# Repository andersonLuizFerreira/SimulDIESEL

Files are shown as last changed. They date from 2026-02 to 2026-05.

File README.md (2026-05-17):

# SimulDIESEL

---

# Português

O SimulDIESEL consiste em uma plataforma de bancada destinada à manutenção, diagnóstico, análise, simulação e validação de centrais e módulos automotivos da linha DIESEL, com foco em caminhões, máquinas agrícolas e equipamentos pesados.

Suas ferramentas permitem ao reparador realizar testes, simulações e análises de funcionamento de redes, sinais e módulos eletrônicos, auxiliando processos de manutenção, desenvolvimento, engenharia reversa e diagnóstico avançado em bancada.

Para conhecer mais sobre o projeto, leia:

- [`docs/README.md`](docs/README.md)
- [`docs/00-INDICE.md`](docs/00-INDICE.md)

Esses arquivos guiarão você pela documentação e estrutura do projeto.

## agentes de IA

Siga para:

- [`.agents/README.md`](.agents/README.md)

---

# English

SimulDIESEL is a bench platform designed for maintenance, diagnostics, analysis, simulation, and validation of DIESEL automotive control units and electronic modules, focused on trucks, agricultural machines, and heavy equipment.

Its tools allow technicians to perform tests, simulations, and analysis of networks, signals, and electronic modules, supporting maintenance, development, reverse engineering, and advanced bench diagnostics.

To learn more about the project, read:

- [`docs/README.md`](docs/README.md)
- [`docs/00-INDICE.md`](docs/00-INDICE.md)

These files will guide you through the project's documentation and structure.

## AI agents

Proceed to:

- [`.agents/README.md`](.agents/README.md)

---

# Español

SimulDIESEL es una plataforma de banco destinada al mantenimiento, diagnóstico, análisis, simulación y validación de centrales y módulos automotrices de la línea DIESEL, enfocada en camiones, maquinaria agrícola y equipos pesados.

Sus herramientas permiten al reparador realizar pruebas, simulaciones y análisis del funcionamiento de redes, señales y módulos electrónicos, ayudando en procesos de mantenimiento, desarrollo, ingeniería inversa y diagnóstico avanzado en banco.

Para conocer más sobre el proyecto, lea:

- [`docs/README.md`](docs/README.md)
- [`docs/00-INDICE.md`](docs/00-INDICE.md)

Estos archivos lo guiarán a través de la documentación y estructura del proyecto.

## agentes de IA

Diríjase a:

- [`.agents/README.md`](.agents/README.md)

---

# Deutsch

SimulDIESEL ist eine Prüfstandsplattform für Wartung, Diagnose, Analyse, Simulation und Validierung von Steuergeräten und elektronischen Modulen im DIESEL-Bereich mit Fokus auf Lastkraftwagen, landwirtschaftliche Maschinen und schwere Geräte.

Die Werkzeuge ermöglichen Technikern die Durchführung von Tests, Simulationen und Analysen von Netzwerken, Signalen und elektronischen Modulen und unterstützen Wartung, Entwicklung, Reverse Engineering und erweiterte Prüfstandsdiagnosen.

Um mehr über das Projekt zu erfahren, lesen Sie:

- [`docs/README.md`](docs/README.md)
- [`docs/00-INDICE.md`](docs/00-INDICE.md)

Diese Dateien führen Sie durch die Dokumentation und Struktur des Projekts.

## KI-Agenten

Weiter zu:

- [`.agents/README.md`](.agents/README.md)

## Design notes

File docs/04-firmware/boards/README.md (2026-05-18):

⬅ [Retornar para Catálogo de Baby Boards e Targets SDH](../05-catalogo-baby-boards.md)
⬅ [Retornar para Índice Geral](../../00-INDICE.md)

# Boards de Firmware

Esta pasta agrupa as boards sob o ponto de vista do firmware embarcado.

## Estado real da pasta

- **IMPLEMENTADO**: `BPM`, `GSA` e `UCE` têm firmware, arquivos, classes e fluxo observáveis.
- **PLANEJADO**: `PSU`, `GSC`, `URL`, `SLU`, `UCO`, `UCS`, `UIOD` e `UHM` permanecem como placeholders documentais.
- **LEGADO**: qualquer leitura que suponha firmware ativo para todas as boards listadas aqui.

## Índice

- [01. BPM](BPM/01-bpm.md)
- [02. PSU](PSU/02-psu.md)
- [03. GSA](GSA/03-gsa.md)
- [11. UCE](UCE/11-uce.md)
- [04. GSC](04-gsc.md)
- [05. URL](05-url.md)
- [06. SLU](06-slu.md)
- [07. UCO](07-uco.md)
- [08. UCS](08-ucs.md)
- [09. UIOD](09-uiod.md)
- [10. UHM](10-uhm.md)

## Leitura correta deste ramo

- `BPM`, `GSA` e `UCE` devem ser lidas como páginas vivas de firmware.
- As demais pages ajudam a preservar nomenclatura e intenção do projeto, mas ainda não representam código embarcado implementado.

## Glossário

- **Board**: unidade física com firmware próprio ou reservado.
- **Página viva**: documento ancorado em implementação real.
- **Placeholder documental**: página mantida para organização, mas sem código correspondente.

## Próximas camadas

- [BPM](BPM/01-bpm.md)
- [PSU](PSU/02-psu.md)
- [GSA](GSA/03-gsa.md)
- [UCE](UCE/11-uce.md)
- [GSC](04-gsc.md)
- [URL](05-url.md)
- [SLU](06-slu.md)
- [UCO](07-uco.md)
- [UCS](08-ucs.md)
- [UIOD](09-uiod.md)
- [UHM](10-uhm.md)

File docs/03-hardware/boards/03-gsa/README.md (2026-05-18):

⬅ [Retornar para Construção Física das Boards](../../05-boards-fisicas.md)
⬅ [Retornar para Índice Geral](../../../00-INDICE.md)

# GSA — Gerador de Sinais Analógicos

Esta página descreve a GSA como placa física.

## Evidências materiais usadas aqui

- `hardware/boards/GSA -gerador-sinais-analogicos/GSA - gerador de sinais analogicos.kicad_sch`
- `hardware/boards/GSA -gerador-sinais-analogicos/GERADOR DE NÍVEIS/GERADOR_NIVEIS.kicad_sch`
- firmware da GSA em `hardware/firmware/GSA - Gerador de sinais analógicos`

## Estrutura física confirmada

| bloco físico | evidência | papel | status |
| --- | --- | --- | --- |
| MCU principal | `Arduino_Nano_Every` no esquemático | lógica local da board | `IMPLEMENTADO` |
| `I2C` físico em `A4/A5` | esquemático + firmware | interface com a BPM | `IMPLEMENTADO` |
| `I2C` lógico em `D2/D3` | esquemático + firmware | barramento interno da board | `IMPLEMENTADO` |
| `IRQ` em `D4` | esquemático + firmware | evento assíncrono para a BPM | `IMPLEMENTADO` |
| reset do hub em `D8` | esquemático + firmware | controle do `TCA9548A` | `IMPLEMENTADO` |
| `TCA9548A` | `GERADOR_NIVEIS.kicad_sch` | seleção de ramo | `IMPLEMENTADO` |
| `MCP4725` | firmware e subprojeto da GSA | DAC por canal | `IMPLEMENTADO` |

## Empilhamento físico da placa

```text
BPM
  -> I2C físico
  -> MCU da GSA
  -> I2C lógico
  -> TCA9548A
  -> MCP4725
  -> estágio analógico
  -> saída do canal
```

## Observações importantes

- O firmware confirma 16 canais lógicos.
- O hub `TCA9548A` divide esses 16 canais em 8 ramos com 2 DACs por ramo.
- A GSA é hoje a principal referência física do projeto; outras boards ainda não apresentam o mesmo conjunto de evidências.

## Glossário

- **MCU**: microcontrolador principal da placa.
- **Ramo**: saída selecionável do `TCA9548A`.
- **DAC**: conversor digital-analógico responsável pelo valor base do canal.

## Próximas camadas

- [Funcionamento eletrônico](01-funcionamento-eletronico.md)

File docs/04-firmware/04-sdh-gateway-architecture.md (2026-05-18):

⬅ [Retornar para Arquitetura de Firmware](01-arquitetura-firmware.md)
⬅ [Retornar para Índice Geral](../00-INDICE.md)

# Arquitetura SDH no Gateway

O nome histórico desta página foi preservado, mas a verdade do código hoje é outra:

- o host interpreta `SDH`;
- a BPM não faz parse de `SDH`;
- o gateway embarcado recebe `SDGW` compacto e payload `TLV` já resolvido.

Esta página documenta **como o gateway realmente opera hoje**.

## Estado real do gateway

- **IMPLEMENTADO**: sessão `SDGW` com handshake textual, `COBS`, `CRC8`, `ACK`, `ERR`, sequência e watchdog.
- **IMPLEMENTADO**: roteamento local `BPM.gateway ping`.
- **IMPLEMENTADO**: roteamento remoto para a GSA via `GwRouter`.
- **IMPLEMENTADO**: roteamento remoto para a UCE via `GwRouter` e `GwSpiBus`.
- **PLANEJADO**: parser `SDH` dentro da BPM.

## Fluxo operacional real

```text
Host
  -> resolve SDH para SDGW compacto
  -> envia frame para BPM
  -> SdgwLink valida e trata handshake/ACK
  -> GatewayApp decide local x remoto
  -> GwRouter escolhe I2C ou SPI
  -> board remota responde TLV
  -> BPM devolve resposta SDGW
```

## Ponto de entrada do gateway

Em `src/main.cpp`, o loop principal da BPM é mínimo:

```cpp
void loop()
{
    sdgwLink.poll();
    app.tick();
}
```

Esse desenho é importante porque separa duas responsabilidades:

- `sdgwLink.poll()` cuida de sessão, framing e dispatch de comando;
- `app.tick()` drena eventos físicos pendentes, especialmente os da GSA.

## Onde o handshake acontece

O handshake não está em `GatewayApp`, mas em `SdgwLink`.

Trecho real de `SdgwLink::processHandshakeByte(...)`:

```cpp
if (memcmp(tail, SDGW_PC_BANNER, need) == 0)
{
    sendBanner();
    _hs = Linked;
    _tr.setTextEnabled(false);
}
```

Esse trecho faz três coisas críticas:

1. detecta o banner textual do host
2. responde com o banner do device
3. desliga o modo texto e entra em `Linked`

## Onde o comando vira ação local ou remota

O corte entre BPM local e board remota está em `GatewayApp::onCommand(...)`:

```cpp
const uint8_t addr = GW_CMD_ADDR(cmd);

if (addr == GW_ADDR_BPM) {
    handleGatewayLocal(cmd, data, dataLen);
    return;
}
```

Hoje isso significa:

- `GW_ADDR_BPM` fica na própria BPM;
- `GW_ADDR_GSA` segue para o roteador;
- `GW_ADDR_UCE` segue para o roteador;
- `GW_ADDR_BROADCAST` é ignorado no código atual.

## Onde a GSA entra no caminho

Quando a GSA baixa `IRQ`, a BPM não executa lógica analógica; ela apenas drena eventos:

```cpp
if (!_router.pollGsaEvent(eventPacket, sizeof(eventPacket), eventLen)) {
    break;
}

_link.sendEvent(SDGW_CMD_GSA_TLV, eventPacket, (uint8_t)eventLen);
```

Esse bloco existe para transformar o evento curto da GSA em evento `SDGW` para o host.

## Onde a UCE entra no caminho

A UCE está publicada na tabela de devices da BPM como `GW_ADDR_UCE` sobre `SPI`.

```cpp
{GW_ADDR_UCE, GW_BUS_SPI, 0x00, BPM_UCE_SPI_CS_PIN, BPM_UCE_IRQ_PIN, BPM_UCE_RESET_PIN, true}
```

Quando o host envia `SDGW_CMD_UCE_TLV`, a BPM não interpreta CAN ou LED. Ela seleciona a UCE por `CS`, transporta o TLV pelo `GwSpiBus` e devolve a resposta pelo mesmo link `SDGW`.

## Consequência arquitetural

O gateway ativo do projeto não é um interpretador semântico amplo. Ele é:

- um terminador de sessão `SDGW`;
- um roteador compacto `ADDR/OP`;
- um adaptador entre host e barramentos da bancada.
- um roteador físico que transporta TLV para GSA por `I2C` e para UCE por `SPI`.

## Glossário

- **GatewayApp**: camada da BPM que separa comandos locais de comandos roteados.
- **Handshake**: transição do banner textual para o modo binário `SDGW`.
- **ADDR/OP**: compactação do comando usada pelo gateway atual.
- **Tick**: trabalho cooperativo executado no loop fora do parser principal.
- **UCE**: board remota SPI que executa LED, CAN e SDCTP fora da BPM.

## Próximas camadas

- [Catálogo de Baby Boards e Targets SDH](05-catalogo-baby-boards.md)
- [Tabela Mestra de Binding Lógico-Físico do Gateway](06-gateway-binding-logico-fisico.md)
- [Resolver Engine do Gateway](07-resolver-engine-gateway.md)

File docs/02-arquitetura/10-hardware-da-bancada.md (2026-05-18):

⬅ [Retornar para Visão Física do Projeto](02-visao-fisica.md)
⬅ [Retornar para Índice Geral](../00-INDICE.md)

# Hardware da Bancada

Esta página agrupa a leitura **ONDE** do hardware físico restante do projeto.

## Inventário físico confirmado

| bloco | evidência real | papel | status |
| --- | --- | --- | --- |
| BPM | `hardware/firmware/BPM - BACKPLANE MANAGER MODULE` | gateway embarcado em ESP32 | `IMPLEMENTADO` |
| GSA | `hardware/firmware/GSA - Gerador de sinais analógicos`, `hardware/boards/GSA -gerador-sinais-analogicos` | baby board analógica | `IMPLEMENTADO` |
| backplane raiz SimulDIESEL | `hardware/boards/SimulDIESEL` | estrutura reservada da bancada | `PARCIALMENTE IMPLEMENTADO` |
| interligação BPM <-> GSA | `SdgwDefs.h`, `config.h`, esquemático da GSA | `I2C`, `IRQ`, reset | `IMPLEMENTADO` |
| X-CONN / chicote / módulo em teste | documentação viva e slots estruturais do host | interface inferior da bancada | `PARCIALMENTE IMPLEMENTADO` |

## Empilhamento físico real

```text
Host local
  -> BPM
  -> barramento físico BPM <-> GSA
  -> GSA
  -> backplane / X-CONN / chicote
  -> módulo em teste
```

## Limite de evidência desta camada

O diretório `hardware/boards/SimulDIESEL` existe, mas o arquivo `SimulDIESEL.kicad_sch` ainda não materializa um esquemático populado equivalente ao nível de detalhe da GSA.

Por isso:

- a posição estrutural do backplane é clara;
- a pinagem completa da placa mãe da bancada ainda não está no mesmo nível de confirmação da GSA.

## Papel desta página na árvore

Esta página não descreve handshake, parser ou fila de eventos. Ela só fixa onde cada parte física confirmada está na bancada.

## Glossário

- **Bancada**: conjunto físico de host, gateway, boards e módulo em teste.
- **Backplane**: base física de interligação da bancada.
- **Baby board**: placa especializada conectada à bancada.
- **X-CONN**: interface física entre bancada e chicote do módulo.

## Próximas camadas

- [Backplane](../03-hardware/01-backplane.md)

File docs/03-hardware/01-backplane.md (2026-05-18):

⬅ [Retornar para Hardware da Bancada](../02-arquitetura/10-hardware-da-bancada.md)
⬅ [Retornar para Índice Geral](../00-INDICE.md)

# Backplane

Esta página documenta o backplane sob a trilha **ONDE**.

## Estado real do backplane

- **PARCIALMENTE IMPLEMENTADO**: existe uma pasta física dedicada em `hardware/boards/SimulDIESEL`.
- **PARCIALMENTE IMPLEMENTADO**: `SimulDIESEL.kicad_pcb` e `SimulDIESEL.kicad_pro` existem como artefatos vivos.
- **PARCIALMENTE IMPLEMENTADO**: `SimulDIESEL.kicad_sch` ainda não materializa um esquemático populado no mesmo nível de detalhe da GSA.
- **IMPLEMENTADO**: a função estrutural do backplane aparece no firmware e na arquitetura física como base de interligação entre BPM, GSA, X-CONN e módulo em teste.

## Onde o backplane fica

```text
BPM
  -> backplane
  -> baby boards
  -> X-CONN
  -> módulo em teste
```

## O que já é possível afirmar com segurança

- a BPM ocupa o papel de gateway superior da bancada;
- a GSA é uma baby board efetivamente integrada à pilha;
- o backplane é a base física prevista para organizar essa ligação;
- a árvore física do projeto já reserva o caminho até X-CONN e chicote.

## O que ainda não é possível afirmar com a mesma segurança

- pinagem completa do backplane
- distribuição detalhada de cada net da placa raiz
- tabela definitiva de slots e conectores por board

Esses pontos permanecem parciais porque o esquemático raiz ainda não está populado como fonte de verdade equivalente à GSA.

## Glossário

- **Backplane**: base física de interligação da bancada.
- **Slot**: posição estrutural reservada para conexão de uma board.
- **Placa raiz**: PCB principal da bancada.

## Próximas camadas

- [Baby Boards](02-baby-boards.md)
- [Barramentos](03-barramentos.md)
- [Alimentação](04-alimentacao.md)

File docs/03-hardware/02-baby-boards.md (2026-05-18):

⬅ [Retornar para Backplane](01-backplane.md)
⬅ [Retornar para Índice Geral](../00-INDICE.md)

# Baby Boards

Esta página inventaria as boards físicas existentes no repositório.

## Inventário físico real

| board | evidência física | evidência de firmware | papel | status |
| --- | --- | --- | --- | --- |
| GSA | `hardware/boards/GSA -gerador-sinais-analogicos` | `hardware/firmware/GSA - Gerador de sinais analógicos` | geração de sinais analógicos | `IMPLEMENTADO` |
| BPM | não aparece aqui como baby board; atua acima da camada | `hardware/firmware/BPM - BACKPLANE MANAGER MODULE` | gateway da bancada | `IMPLEMENTADO` |
| legacy-comunicacao | `hardware/boards/SimulDIESEL/legacy-comunicacao` | nenhuma evidência ativa na pilha atual | acervo histórico | `LEGADO` |
| demais boards nomeadas na documentação | apenas páginas/documentação | não encontrada em `hardware/firmware` | catálogo reservado | `PLANEJADO` |

## Posição das baby boards na bancada

```text
BPM
  -> barramento físico
  -> baby board
  -> circuito local
  -> sinais para a bancada
```

## Observação importante

A GSA é hoje a única baby board com:

- pasta de hardware viva
- firmware vivo
- contrato funcional vivo no host

Por isso ela é a referência principal deste ramo.

## Glossário

- **Baby board**: placa especializada conectada ao backplane.
- **Acervo legado**: hardware mantido no repositório sem papel ativo na arquitetura corrente.
- **Referência física**: board que já possui evidência suficiente para documentar construção e integração.

## Próximas camadas

- [Construção Física das Boards](05-boards-fisicas.md)

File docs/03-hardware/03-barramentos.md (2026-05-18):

⬅ [Retornar para Backplane](01-backplane.md)
⬅ [Retornar para Índice Geral](../00-INDICE.md)

# Barramentos

Esta página fixa **onde** cada barramento físico confirmado entra na bancada.

## Barramentos confirmados

| barramento | origem | destino | evidência | status |
| --- | --- | --- | --- | --- |
| Serial | host | BPM | firmware BPM e `local-api` | `IMPLEMENTADO` |
| Bluetooth SPP | host | BPM | firmware BPM e `local-api` | `IMPLEMENTADO` |
| `I2C` físico | BPM `21/22` | GSA `A4/A5` | `SdgwDefs.h`, `config.h`, esquemático GSA | `IMPLEMENTADO` |
| `IRQ` dedicado | GSA `D4` | BPM `19` | `SdgwDefs.h`, `config.h` | `IMPLEMENTADO` |
| `SPI` | BPM `18/26/25` | UCE `SCK/MISO/MOSI` | `SdgwDefs.h`, `config.h`, `GwSpiBus`, `lib/core/transport/Transport.*` | `IMPLEMENTADO` |
| `CS` dedicado | BPM `33` | UCE `D10 / PA28 / NPCS0` | `SdgwDefs.h`, `config.h`, `lib/core/transport/Transport.*` | `IMPLEMENTADO` |
| `IRQ` dedicado | UCE `D2` | BPM `27` | `SdgwDefs.h`, `config.h`, `GwSpiBus`, `lib/core/transport/Transport.*` | `IMPLEMENTADO` |
| reset compartilhado | BPM `23` | reset físico da GSA e da UCE | `SdgwDefs.h`, `config.h` | `IMPLEMENTADO` |
| `I2C` lógico | GSA `D2/D3` | `TCA9548A` + `MCP4725` | `config.h`, firmware GSA | `IMPLEMENTADO` |

## Empilhamento físico dos barramentos

```text
Host
  -> Serial / Bluetooth
  -> BPM
  -> I2C físico / IRQ / reset
  -> GSA
  -> I2C lógico
  -> TCA9548A / MCP4725
  -> SPI / CS / IRQ / reset
  -> UCE
```

## Comentário orientado a código

Em `GwSpiBus::begin(...)`, o firmware fixa a pinagem `SPI` explicitamente:

```cpp
_spi.begin(_sckPin, _misoPin, _mosiPin, -1);
```

Isso existe para não usar o mapeamento padrão do ESP32, que conflitaria com o reset global em `GPIO23` e quebraria o contrato físico da UCE.

Na UCE, o `CS` fica sob o periférico nativo `SPI0` e recebe pull-up por registrador PIO:

```cpp
PIOA->PIO_PDR = kUceSpiSignalPins;
PIOA->PIO_ABSR &= ~kUceSpiSignalPins;
PIOA->PIO_PUER = kUceSpiNativeCsPin;
```

Esse trecho existe para manter `PA28/NPCS0` em função periférica, sem perder o nível alto de repouso do `CS`.

## Glossário

- **I2C físico**: barramento entre gateway BPM e GSA.
- **SPI físico**: barramento entre gateway BPM e UCE.
- **I2C lógico**: barramento interno da GSA para periféricos.
- **IRQ**: linha dedicada de sinalização assíncrona.
- **Open-drain por software**: técnica em que o firmware só força nível baixo e libera a linha no estado inativo.

## Próximas camadas

- Esta é uma página terminal do ramo físico. Os protocolos associados aos barramentos ficam no ramo lógico.

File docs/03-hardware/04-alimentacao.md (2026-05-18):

⬅ [Retornar para Backplane](01-backplane.md)
⬅ [Retornar para Índice Geral](../00-INDICE.md)

# Alimentação

Esta página documenta apenas o que a árvore atual permite afirmar com segurança sobre alimentação.

## Estado real

- **PARCIALMENTE IMPLEMENTADO**: a separação entre alimentação da bancada e lógica das boards aparece na arquitetura física e nas faixas de saída da GSA.
- **IMPLEMENTADO**: a GSA possui firmware e hardware orientados a canais `0..5 V` e `0..12 V`.
- **PARCIALMENTE IMPLEMENTADO**: a placa raiz da bancada ainda não expõe um esquema populado que permita documentar toda a distribuição de energia com pinagem e netlist.
- **PLANEJADO**: documentação completa de domínios, proteções e orçamento de potência do backplane.

## O que o código confirma

Em `config.h` da GSA:

- canais `1..8` usam faixa máxima de `5000 mV`
- canais `9..16` usam faixa máxima de `12000 mV`

Isso confirma a existência funcional de dois grupos de saída analógica.

## O que o hardware confirma parcialmente

- a GSA possui esquemático próprio e circuito local dedicado;
- a bancada possui placa raiz reservada em `hardware/boards/SimulDIESEL`;
- ainda falta material equivalente para descrever toda a distribuição de energia da placa mãe com o mesmo rigor da GSA.

## Leitura correta desta página

Esta não é uma ficha elétrica completa. Ela apenas registra que:

- há mais de um domínio funcional relevante na bancada;
- a GSA já opera com duas faixas de saída documentadas;
- a documentação de alimentação do backplane ainda está em maturação.

## Glossário

- **Domínio de alimentação**: conjunto de circuitos que compartilha uma mesma faixa ou propósito de energia.
- **Faixa de saída**: intervalo elétrico que um canal é projetado para produzir.
- **Placa mãe da bancada**: backplane físico principal do projeto.

## Próximas camadas

- Esta é uma página terminal deste ramo da documentação.

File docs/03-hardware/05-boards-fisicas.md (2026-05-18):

⬅ [Retornar para Baby Boards](02-baby-boards.md)
⬅ [Retornar para Índice Geral](../00-INDICE.md)

# Construção Física das Boards

Esta camada aprofunda a construção física das boards que possuem evidência suficiente no repositório.

## Estado real

- **IMPLEMENTADO**: a GSA possui esquemático, PCB e firmware coerentes entre si.
- **PARCIALMENTE IMPLEMENTADO**: a placa raiz `SimulDIESEL` existe como hardware, mas ainda não sustenta o mesmo nível de documentação física por netlist.
- **LEGADO**: `legacy-comunicacao` preserva uma solução anterior fora da arquitetura corrente.
- **PLANEJADO**: demais boards físicas ainda não atingiram o mesmo nível de detalhamento.

## Caminho deste ramo

```text
Board física
  -> MCU / lógica local
  -> barramentos locais
  -> periféricos elétricos
  -> conectores / saída
```

## Referência viva

A GSA é a board física mais madura desta árvore porque já mostra:

- microcontrolador identificado no esquemático
- barramento físico com a BPM
- barramento lógico interno
- periféricos `TCA9548A` e `MCP4725`
- firmware correspondente

## Glossário

- **Construção física**: leitura focada em componentes, conectores e interligações materiais.
- **Referência viva**: board que já possui evidência suficiente para aprofundamento.
- **Netlist**: material que permite afirmar conexões elétricas concretas.

## Próximas camadas

- [Abrir documentação física da GSA](./boards/03-gsa/README.md)

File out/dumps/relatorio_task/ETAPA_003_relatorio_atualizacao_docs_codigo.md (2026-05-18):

# ETAPA_003 - Relatorio de atualizacao docs <- codigo

## Status

Concluida em 2026-05-18.

## Escopo executado

Atualizacao de documentos existentes em `docs/` para refletir o estado atual comprovado no codigo versionado, conforme autorizacao humana explicita `codigo -> docs` desta etapa.

## Evidencias consultadas

- `local-api/src/SimulDIESEL/SimulDIESEL/BLL/Boards/BPM/Comm/Serial/BpmSerialService.cs`
- `local-api/src/SimulDIESEL/SimulDIESEL/BLL/Boards/UCE/UceClient.cs`
- `local-api/src/SimulDIESEL/SimulDIESEL/BLL/Boards/UCE/UceDispatcher.cs`
- `local-api/src/SimulDIESEL/SimulDIESEL/BLL/FormsLogic/UCE/FrmUceLogic.cs`
- `local-api/src/SimulDIESEL/SimulDIESEL/BLL/Services/CAN/CanControlApiService.cs`
- `local-api/src/SimulDIESEL/SimulDIESEL/BLL/Services/CAN/SDCTP/SdctpApiService.cs`
- `local-api/src/SimulDIESEL/SimulDIESEL/DAL/Protocols/SDH/SdhValidator.cs`
- `local-api/src/SimulDIESEL/SimulDIESEL/DAL/Protocols/SDH/SdhToSdgwMapper.cs`
- `local-api/src/SimulDIESEL/SimulDIESEL/DTL/Boards/UCE/`
- `local-api/src/SimulDIESEL/SimulDIESEL/DTL/Protocols/J1939/`
- `local-api/src/SimulDIESEL/SimulDIESEL/DTL/Protocols/SDCTP/`
- `hardware/firmware/BPM - BACKPLANE MANAGER MODULE/include/SdgwDefs.h`
- `hardware/firmware/BPM - BACKPLANE MANAGER MODULE/lib/GwDeviceTable/GwDeviceTable.cpp`
- `hardware/firmware/UCE - Unidade de comunicacao externa/src/main.cpp`
- `hardware/firmware/UCE - Unidade de comunicacao externa/lib/core/link/SpiLink.*`
- `hardware/firmware/UCE - Unidade de comunicacao externa/lib/core/transport/UceTransport.*`
- `hardware/firmware/UCE - Unidade de comunicacao externa/lib/core/services/UceServiceDispatcher.*`
- `hardware/firmware/UCE - Unidade de comunicacao externa/lib/services/can/`

## Arquivos atualizados

- `docs/00-INDICE.md`
- `docs/01-visao-geral/01-visao-geral-projeto.md`
- `docs/02-arquitetura/04-api-e-host-local.md`
- `docs/02-arquitetura/05-bll-do-host.md`
- `docs/02-arquitetura/05-bll-do-host/01-formslogic-e-fachadas.md`
- `docs/02-arquitetura/06-dal-do-host.md`
- `docs/02-arquitetura/06-dal-do-host/01-sessao-sdh-e-sdgw.md`
- `docs/02-arquitetura/07-dtl-do-host.md`
- `docs/02-arquitetura/07-dtl-do-host/01-contratos-sdh-e-dtos.md`
- `docs/04-firmware/01-arquitetura-firmware.md`
- `docs/04-firmware/02-drivers.md`
- `docs/04-firmware/04-sdh-gateway-architecture.md`
- `docs/04-firmware/boards/UCE/11-uce.md`
- `docs/05-software-dashboard/01-arquitetura-software.md`
- `docs/05-software-dashboard/04-sdh-host-architecture/04-parsing-e-tratamento-de-respostas.md`
- `docs/06-protocolos/07-uce-sdh-tlv.md`
- `docs/09-desenvolvimento/01-organizacao-repositorio.md`
- `docs/11-planejamento/01-planejamento.md`
- `docs/11-planejamento/02-proximas-funcionalidades.md`

## Principais divergencias corrigidas

- Estado geral do projeto deixou de tratar a UCE como proxima board apenas planejada e passou a refletir a rota `UCE.*` ja existente.
- Documentos de BLL, DAL e DTL passaram a incluir `UceClient`, `UceDispatcher`, `FrmUceLogic`, `CanControlApiService`, `SdctpApiService`, DTOs UCE, SDCTP e J1939.
- Documentos de firmware passaram a refletir a UCE real: `SpiLink`, `UceTransport`, `UceServiceDispatcher`, `LedService`, `SdctpService`, `CanService`, drivers e tabelas CAN.
- O gateway deixou de ser descrito como sem device `SPI`; a BPM publica a UCE por `GW_ADDR_UCE`.
- A organizacao do repositorio foi ajustada para remover referencias a `docs/archive`, `docs/generated` e pastas antigas de firmware que nao representam a arvore atual.
- O contrato UCE SDH/TLV passou a registrar comandos CAN/SDCTP e a restricao atual de `UCE.can.rx readAll` no mapper.

## Validacoes realizadas

- `git status --short`: alteracoes restritas a `docs/` antes da criacao deste relatorio.
- Verificacao de links Markdown em `docs/`: `broken_links=0`.
- Busca por referencias legadas removidas: `lib/app`, `lib/core/service`, `lib/protocol/tlv`, `lib/drivers/can`, `lib/diag/trace`, `Sam3xCanDriver`, `UceApp`, `docs/archive`, `docs/generated`, `esp32-api-bridge`.
- Conferencia da arvore real de firmware UCE com `rg --files`.
- Nenhum arquivo funcional de `local-api/`, `hardware/`, `cloud/`, `infra/`, `tools/` ou `tests/` foi alterado.

## Pendencias

- Validacao fisica de bancada ampla da UCE/CAN/SDCTP permanece fora desta etapa.
- Catalogo fisico completo de boards e detalhamento por netlist do backplane permanecem como evolucao futura.
- Commit de documentacao registrado: `2b061186` - `Update docs from code state`.

## Rollback

Como a etapa alterou apenas documentacao, relatorio e controle de execucao da propria ETAPA, o rollback pode ser feito revertendo o commit de documentacao correspondente.

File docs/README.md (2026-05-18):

# SimulDIESEL — Documentação Oficial

Bem-vindo à documentação oficial do **SimulDIESEL**.

Esta pasta é o ponto de entrada para a documentação consolidada do projeto. Ela não substitui o código, o histórico do Git ou os registros de validação, mas organiza a leitura humana sobre a arquitetura, os protocolos, o hardware, o firmware, o software e os casos de uso.

A documentação está organizada como uma **árvore hierárquica de aprofundamento progressivo**. A ideia é começar por um mapa geral, entrar na visão do projeto e avançar para documentos mais específicos somente quando necessário.

## Como navegar

Use o [índice geral](./00-INDICE.md) como ponto de partida. Ele funciona como o mapa global da documentação.

Dentro de cada página oficial:

* use o link de retorno ao pai imediato para subir um nível na árvore;
* use o link de retorno ao índice geral para voltar ao mapa principal;
* siga a seção **Próximas camadas** quando quiser continuar para documentos mais específicos.

Essa estrutura evita caminhos duplicados e mantém a leitura previsível.

## Visões de leitura

A documentação pode ser lida por duas perspectivas complementares:

* **visão física**: placas, conexões, sinais, barramentos e interfaces reais da bancada;
* **visão lógica**: camadas de software, protocolos, comandos, contratos e responsabilidades internas.

A visão geral do projeto está documentada em [Visão Geral do Projeto](./01-visao-geral/01-visao-geral-projeto.md).

## Governança documental

A governança oficial para agentes e manutenção documental está em [`.agents/README.md`](../.agents/README.md) e na skill [docs-governance](../.agents/skills/docs-governance/SKILL.md).

Para leitores humanos, a regra prática é simples: a pasta `docs/` deve explicar o projeto de forma clara, didática e atual, sem se confundir com logs de execução, dumps, prompts ou relatórios operacionais.

## Papel desta página

Esta página apresenta a lógica de navegação da pasta `docs/` e direciona o leitor para o índice global da documentação viva.

O acervo histórico removido da árvore viva continua preservado pelo Git e por registros em `out/dumps/`. Esses registros podem ser úteis para auditoria ou recuperação de versões antigas, mas não substituem a documentação consolidada desta pasta.

## Glossário

- **Documentação oficial**: árvore viva usada como referência atual do projeto.
- **Índice geral**: mapa global clicável da navegação documental.
- **Pai imediato**: documento estrutural acima da página atual.
- **Governança documental**: conjunto de regras que controla estrutura, navegação, estilo e revisões da documentação.
- **Visão física**: leitura orientada a placas, sinais, conectores, barramentos e módulos reais.
- **Visão lógica**: leitura orientada a camadas de software, protocolos, comandos, contratos e fluxos internos.

## Próximas camadas

* [00-INDICE — Índice Geral da Navegação](./00-INDICE.md)

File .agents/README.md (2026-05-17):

# .agents - Governanca de agentes do SimulDIESEL

Esta pasta e a unica estrutura oficial de governanca para agentes de IA no projeto SimulDIESEL.

## Objetivo

- Evitar dependencia de memoria conversacional.
- Centralizar bootstrap, regras globais e skills.
- Garantir consistencia arquitetural.
- Reduzir retrabalho e ambiguidade.
- Impedir implementacoes fora de escopo.
- Padronizar ETAPAS, validacoes, entregas e rollback.

## Bootstrap obrigatorio

Antes de qualquer analise, planejamento, ETAPA, alteracao de codigo ou alteracao documental:

1. Leia o `README.md` da raiz.
2. Leia este arquivo.
3. Carregue automaticamente a skill obrigatoria `.agents/skills/task-execution-workflow/SKILL.md`.
4. Carregue somente as demais skills relevantes em `.agents/skills/<skill>/SKILL.md`.
5. Consulte a documentacao aplicavel em `docs/`.
6. Trabalhe a partir dos arquivos versionados do repositorio, nunca apenas da memoria conversacional.

## Estrutura oficial

```text
.agents/
|-- README.md
|
|-- task-execution-workflow/
|   |-- ETAPA_001.md
|   |-- ETAPA_002.md
|
`-- skills/
    |-- task-execution-workflow/
    |   `-- SKILL.md
    `-- <skill>/
        `-- SKILL.md
```

A pasta `.agents/task-execution-workflow/` contem ETAPAS versionadas e pendentes de execucao.

Para regras operacionais de execucao de ETAPAS, selecao de tarefas, estados, tics, ownership, historico operacional, nomenclatura, validacao e fluxo de execucao:

```text
.agents/skills/task-execution-workflow/SKILL.md
```

Cada skill deve conter apenas conhecimento especializado do dominio.

Regras globais, bootstrap, rollback generico, validacao generica e regras globais de ETAPA pertencem exclusivamente a este README.

Detalhes operacionais, regras especificas de workflow e regras locais pertencem exclusivamente a skill correspondente.

Skills locais complementam a governanca global.

Skills locais nao podem reescrever, duplicar, substituir ou reinterpretar regras globais.

## Autoridade da governanca

A autoridade final sobre criacao, alteracao, remocao, consolidacao, excecao ou resolucao de conflito de governanca pertence ao humano responsavel pelo projeto.

A IA pode identificar lacunas, sugerir ajustes, validar coerencia e reportar conflitos, mas nao pode aprovar sozinha mudancas permanentes de governanca.

Quando houver duvida, lacuna, conflito ou ambiguidade de governanca, a IA deve interromper a ETAPA e solicitar decisao humana explicita.

## Hierarquia Global -> Local

A governanca segue obrigatoriamente esta hierarquia, sem fontes paralelas:

1. Global: `.agents/README.md`.
2. Local: `.agents/skills/<skill>/SKILL.md`.

Regras globais pertencem exclusivamente a `.agents/README.md`.

Regras locais pertencem exclusivamente a skill correspondente em `.agents/skills/<skill>/SKILL.md`.

Se uma regra nao existir nesse caminho Global -> Local, ela nao deve existir em nenhum outro local.

A busca por regras deve ocorrer somente em:

- `.agents/README.md`;
- `.agents/skills/<skill>/SKILL.md` da atividade em questao.

Quando uma ETAPA exigir mais de uma skill local, todas as skills aplicaveis devem ser lidas.

Se houver conflito, divergencia ou sobreposicao operacional entre skills locais, a IA nao deve escolher uma por conta propria: deve interromper a ETAPA, reportar o conflito e solicitar decisao humana.

## Fonte oficial

- `docs/` = documentacao consolidada do projeto.
- `.agents/` = governanca oficial de agentes.
- Git = historico, legado, rollback e recuperacao de versoes antigas.

Dumps registram historico e auditoria, mas nao substituem `docs/` nem `.agents/`.

## Arquitetura base

```text
UI -> BLL -> DAL -> DTL -> SDGW -> BPM -> SPI/BT/SERIAL -> UCE/GSA
```

## Fronteiras de responsabilidade

| Area | Pode conter | Nao deve conter |
| --- | --- | --- |
| UI | Formularios, controles, apresentacao e eventos de operador | TLV bruto, SDGW direto, regra de protocolo de baixo nivel |
| BLL | Casos de uso, FormsLogic, clients e servicos de aplicacao | Framing, COBS, CRC ou acesso direto a SerialPort |
| DAL | SDH, SDGW, sessao, scheduler e transportes | Regra de UI ou decoders automotivos |
| DTL | DTOs, enums e contratos | Logica de execucao, IO ou retry |
| SDGW | Transporte, framing, ACK/ERR, retry e roteamento | Regra CAN, J1939, UI ou negocio |
| SDCTP | Massa CAN, mirror, buffers e TX/RX table | Apresentacao, regra de tela ou framing SDGW |
| Firmware | Execucao embarcada e servicos fisicos | Dependencias de UI/host |

## Regras globais

- Use sempre o termo `ETAPA`; nunca `FASE`.
- Nao implementar comportamento nao validado.
- Nao ampliar escopo automaticamente.
- Nao misturar UI, BLL, DAL, DTL, firmware e protocolos sem autorizacao.
- Nao alterar contratos consolidados sem autorizacao explicita.
- Nao assumir comportamento nao confirmado por codigo, documentacao atual ou validacao.
- Registrar ambiguidades como `pendente de confirmacao`.
- Nao alterar codigo, firmware, banco, UI ou contratos quando o pedido for exclusivamente documental.
- Nao promover automaticamente algo de `PLANEJADO` para `IMPLEMENTADO` sem evidencia concreta no codigo, teste, build ou validacao aplicavel.
- BPM deve permanecer gateway/roteador.
- UCE deve permanecer camada de execucao fisica CAN/LED.
- GSA deve permanecer geradora de sinais analogicos.

## Estados documentais

- `IMPLEMENTADO`: confirmado em codigo, contrato ou validacao aplicavel.
- `PARCIALMENTE IMPLEMENTADO`: existe, mas com limite conhecido.
- `PLANEJADO`: descrito como futuro ou placeholder.
- `LEGADO`: preservado por compatibilidade ou historico.
- `pendente de confirmacao`: nao ha evidencia suficiente.

## Regras globais de ETAPA

Toda ETAPA deve declarar:

- tema e objetivo;
- escopo permitido;
- fora de escopo;
- arquivos provaveis;
- regras de implementacao;
- validacao obrigatoria;
- entrega esperada;
- restricoes e rollback.

ETAPAS de refatoracao devem preservar comportamento.

ETAPAS de limpeza de legado devem provar ausencia de uso por busca, teste ou evidencia equivalente.

ETAPAS de congelamento devem registrar decisoes congeladas, decisoes pendentes e regras de nao regressao.

Detalhes operacionais de ETAPA pertencem exclusivamente a:

```text
.agents/skills/task-execution-workflow/SKILL.md
```

## Validacao

Valide apenas o que se aplica ao escopo.

- API C# WinForms: build da solucao `local-api/src/SimulDIESEL/SimulDIESEL.sln`, quando houver alteracao funcional C#.
- Firmware BPM/UCE/GSA: `platformio run` na pasta correspondente, quando a ETAPA permitir.
- Protocolos CAN/SDCTP/J1939: scripts em `tools/testes/`, quando pertinentes.
- Banco de Modulos: validadores e dumps do modelo quando houver alteracao de schema/modelo.
- Documentacao: conferir arquivos criados, links basicos, referencias internas e coerencia com `docs/`.

Para ETAPA exclusivamente documental, nao execute build funcional se nao houver alteracao de codigo; registre que nao se aplica.

## Checklist geral de validacao

- O escopo da ETAPA foi respeitado.
- Nao houve alteracao fora do escopo autorizado.
- Arquivos funcionais nao foram alterados em ETAPA documental.
- Contratos SDH, SDGW e SDCTP foram preservados ou a alteracao foi explicitamente autorizada.
- UI, BLL, DAL, DTL, firmware e banco nao foram misturados sem autorizacao.
- Warnings, erros e limitacoes foram relatados.
- Lista de arquivos alterados foi gerada.
- Resultado de build/teste foi registrado ou marcado como nao aplicavel.
- Documentacao impactada foi revisada/atualizada ao concluir a ETAPA.
- Rollback foi preservado.

## Resolucao de conflitos

Quando houver duplicidade ou divergencia:

- Preserve a versao mais completa, mais atual e mais coerente com o estado real do projeto.
- Absorva conteudo util da versao inferior antes de remove-la.
- Mantenha apenas uma fonte oficial para cada regra.
- Aplique a regra mais conservadora ate confirmacao.
- Nao invente regra para preencher lacuna.
- Registre divergencias e decisoes na entrega da ETAPA.

Conflitos entre regras globais e locais, ou entre duas ou mais skills locais, nao podem ser resolvidos por escolha autonoma da IA. Nesses casos, a ETAPA deve ser interrompida e encaminhada para decisao humana.

## Rollback

- Use Git como mecanismo de recuperacao.
- Nao use `git reset --hard`, checkout destrutivo, limpeza de arquivos ou force push sem pedido explicito.
- Nunca reverta trabalho preexistente de outro autor sem autorizacao.
- Antes de commit, confira `git status --short` e os arquivos staged.
- Em entrega, informe arquivos removidos, migrados, alterados e validacoes executadas.

## Entrega obrigatoria

Toda entrega deve conter:

- arquivos criados, alterados, migrados e removidos;
- resumo objetivo do que mudou;
- conflitos resolvidos e redundancias removidas;
- validacoes executadas e resultados;
- warnings, erros ou validacoes nao executadas;
- pontos pendentes;
- confirmacao de rollback preservado;
- commit hash e confirmacao de push quando a ETAPA pedir commit/push.

## Skills oficiais

| Skill | Quando usar |
| --- | --- |
| `task-execution-workflow` | Workflow operacional de execucao de ETAPAS versionadas. |
| `simuldiesel-architecture` | Arquitetura geral, fronteiras e congelamentos. |
| `winforms-ui` | Telas WinForms, controles e FormsLogic. |
| `bll-dal-dtl` | Camadas BLL, DAL e DTL do host C#. |
| `sdh-contract` | Comandos, validacao e contrato semantico SDH. |
| `sdctp-contract` | Massa CAN RX/TX, mirror e output buffer. |
| `sdgw-transport` | Transporte/gateway SDGW no host e BPM. |
| `j1939-decode` | Decodificacao J1939, PGN, SPN e catalogos. |
| `module-database` | Banco de Modulos, schema, perfis e comandos SDH armazenados. |
| `firmware-uce` | Firmware UCE, SPI, LED, CAN e SDCTP embarcado. |
| `firmware-bpm` | Firmware BPM como SDGW e roteador fisico. |
| `git-checkpoint` | Status, diff, rollback e consolidacao Git autorizada. |
| `build-validation` | Builds, scripts e validacoes reproduziveis. |
| `dump-generation` | Dumps de ETAPA, inventarios e registros de decisoes. |
| `governance-rule-management` | Criacao, alteracao e consolidacao de regras de governanca. |

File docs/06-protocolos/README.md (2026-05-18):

⬅ [Retornar para Fluxo de Comunicação](../02-arquitetura/03-fluxo-de-comunicacao.md)
⬅ [Retornar para Índice Geral](../00-INDICE.md)

# Protocolos e Contratos

## Estado atual

Este ramo reúne os protocolos e contratos que participam da leitura lógica do sistema.

## Classificação de estado

- **IMPLEMENTADO**: cadeia SDH -> SDGW -> TLV curto para a GSA.
- **IMPLEMENTADO**: contrato funcional já exercitado para `BPM.gateway` e para o conjunto atual da GSA.
- **PARCIALMENTE IMPLEMENTADO**: CAN no host/UCE, com fluxo RX/TX consolidado por SDCTP e limites de bancada documentados.
- **PARCIALMENTE IMPLEMENTADO**: J1939 no host, sobre `CanFrameDto`, com decodificação, diagnósticos, gerenciamento de rede e captura temporal para engenharia reversa.

## Papel desta página

Ela separa a topologia física dos barramentos da semântica dos protocolos. Aqui o foco é **como os dados são modelados, encapsulados e interpretados**.

## Glossário

- **Protocolo**: conjunto de regras de comunicação e interpretação.
- **Contrato**: formato estável de um comando, resposta ou evento.
- **SDH**: envelope semântico de comandos do host.
- **SDGW**: enlace binário entre host e gateway.
- **TLV**: contrato compacto interno usado entre gateway e device.

## Próximas camadas

- [Onboarding — Arquitetura de Comandos (SDH)](00-onboarding-comandos.md)
- [CAN](04-can.md)
- [J1939](05-j1939.md)

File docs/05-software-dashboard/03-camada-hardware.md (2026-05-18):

⬅ [Retornar para Arquitetura do Software Dashboard (Local API)](01-arquitetura-software.md)
⬅ [Retornar para Índice Geral](../00-INDICE.md)

# Camada Hardware do Software

## O que esta camada faz

Na leitura lógica do host, a camada hardware do software é o conjunto de classes que:

- sobe a sessão entre host e BPM;
- mantém o link lógico vivo;
- transforma comandos SDH em frames SDGW;
- devolve respostas e eventos para a camada funcional.

## Componentes ativos

| função | classes | estado | observação |
| --- | --- | --- | --- |
| sessão e estados do link | `SdgwHostSession`, `BpmSerialService` | `IMPLEMENTADO` | fazem handshake textual, rearmam tentativa e projetam estado |
| semântica SDH | `SdhClient`, `SdhValidator`, `SdhToSdgwMapper` | `IMPLEMENTADO` | validam targets e montam payloads compactos |
| fila, framing e ACK | `SdGwTxScheduler`, `SdGwLinkEngine` | `IMPLEMENTADO` | stop-and-wait, COBS, CRC, timeout e retry |
| watchdog de saúde | `SdGwLinkSupervisor` | `IMPLEMENTADO` | mede silêncio de RX válido e agenda ping |
| adaptação física | `SwitchableTransport`, `SerialTransport`, `BluetoothTransport` | `IMPLEMENTADO` | entregam bytes ao endpoint físico ativo |
| casos funcionais de board | `GsaClient`, `UceClient`, `BpmClient` | `IMPLEMENTADO` | transformam resposta técnica em resultado funcional; `UceClient` agora cobre LED e configuração CAN |

## Fluxos lógicos confirmados

### Subida de sessão

`SdgwHostSession` abre o transporte, drena ruído inicial, envia o banner textual `SIMULDIESELAPI` e só então libera o estado `Linked`.

### Caminho de comando

`FrmGsaLogic`, `FrmUceLogic` ou `BpmClient` chamam `SdhClient`, que valida o comando, mapeia o target para TLV SDGW e entrega o envio para `SdgwSession`.

Na UCE, isso agora cobre dois grupos de uso:

- LED residual: `UCE.led set state=on|off`
- CAN: `UCE.can.config`, `UCE.can.enable`, `UCE.can.status` e `UCE.can reset`

### Caminho de resposta

`SdGwLinkEngine` decodifica o frame, valida CRC, trata `ACK` e `ERR`, e `SdgwSession` repassa o frame lógico para quem estiver inscrito.

Para a UCE, as respostas continuam síncronas e compactas. `UceParsers` agora interpreta:

- confirmação do LED
- resposta de `config`
- resposta de `enable`
- resposta de `status`
- resposta de `reset`
- erro funcional `0x7F`
- erro de gateway `0xFE`

### Caminho de evento

`GsaClient` consome `SdgwSession.EventReceived`, interpreta `fault` e resultado físico, e sobe esses eventos para `FrmGsaLogic` e `frmGSA_UI`. `UceClient` continua trabalhando apenas com resposta síncrona compacta e entrega o resultado para `FrmUceLogic` e `frmUCE_UI`; a feature CAN da UCE não abriu canal assíncrono novo no host.

## Ponto específico da UI da UCE

Na tela `frmUCE_UI`, a área CAN agora faz:

- leitura inicial de `UCE.can.status get` ao carregar a janela
- `UCE.can.config set` ao alterar velocidade ou modo
- `UCE.can.enable set` ao marcar ou desmarcar a porta

O controller segue fixo em `can0` na UI desta rodada.

## Trecho comentado: composição lógica do host

No construtor de `SdgwHostSession`, a pilha operacional aparece inteira:

```csharp
_engine = new SdGwLinkEngine(cfg, WriteRaw);
_txScheduler = new SdGwTxScheduler(_engine);
Sdgw = new SdgwSession(_engine, _txScheduler);
Sdh = new SdhClient(Sdgw);
_linkSupervisor = new SdGwLinkSupervisor(linkSupervisorCfg, SendSupervisorPingAsync);
```

O que esse trecho faz:

- define o encadeamento real entre envio semântico, fila, engine e supervisor;
- mostra que o host possui uma sessão própria, independente de `SerialPort`;
- prepara a base que todas as operações BPM/GSA usam depois.

## O que o código não sustenta

- Não há evidência em `local-api` de barramentos internos da BPM, pinos, ISR ou IRQ de firmware como entidades observáveis pelo host.
- Não há modelo remoto `BUSY`/`IDLE` além do `Busy` local do `SdGwLinkEngine`.
- Não há stack Bluetooth nativa além do reaproveitamento de COM SPP.

## Glossário

- **Subida de sessão**: processo que leva o host de desconectado para `Linked`.
- **Watchdog lógico**: regra que considera o link vivo ou morto a partir de atividade recebida.
- **Camada hardware do software**: zona do software PC que fala diretamente com sessão, enlace e transporte.

## Próximas camadas

- [Arquitetura SDH no Host](04-sdh-host-architecture.md)

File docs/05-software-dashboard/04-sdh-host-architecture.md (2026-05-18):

⬅ [Retornar para Camada Hardware do Software](03-camada-hardware.md)
⬅ [Retornar para Índice Geral](../00-INDICE.md)

# Arquitetura SDH no Host

## Objetivo

Este documento descreve o comportamento do host SDH/SDGW realmente implementado em `local-api`, sem misturar detalhes de firmware que o código do PC não observa.

## Pilha lógica ativa

```text
UI / FormsLogic
  -> BpmSerialService
  -> GsaClient / BpmClient
  -> SdhClient
  -> SdhValidator / SdhToSdgwMapper
  -> SdgwSession
  -> SdGwTxScheduler
  -> SdGwLinkEngine
  -> SwitchableTransport
  -> SerialTransport / BluetoothTransport
```

## Comportamentos confirmados

| comportamento | evidência principal | estado |
| --- | --- | --- |
| handshake textual antes do binário | `SdgwHostSession.LinkTick(...)`, `HandleHandshakeBytes(...)` | `IMPLEMENTADO` |
| sessão `Linked` habilita supervisor | `SdgwHostSession.OnStateChanged_ForLinkSupervisor(...)` | `IMPLEMENTADO` |
| envio concorrente passa por fila única | `SdGwTxScheduler.EnqueueAsync(...)` | `IMPLEMENTADO` |
| stop-and-wait com ACK/ERR/retry | `SdGwLinkEngine.SendWithSeq(...)`, `AckTimeoutTick(...)` | `IMPLEMENTADO` |
| saúde do link baseada em RX válido | `SdGwLinkSupervisor.OnValidFrameReceived(...)`, `Tick(...)` | `IMPLEMENTADO` |
| GSA com resposta síncrona e evento assíncrono | `GsaClient.ExecuteOperationAsync(...)`, `OnEventReceived(...)` | `IMPLEMENTADO` |
| parsing e tratamento de resposta | `SdhTextParser`, `SdhValidator`, `SdhToSdgwMapper`, `GsaParsers` | `IMPLEMENTADO` |

## Limites do host atual

- O host só valida e mapeia targets SDH conhecidos; outros targets geram `NotSupportedException`.
- O caminho funcional maduro está concentrado em `GSA.*` e no ping `BPM.gateway`.
- Bluetooth no host ainda é SPP sobre COM.
- O contrato `SdhResponse` existe, mas não participa do hot path desta aplicação.

## Aprofundamentos deste ramo

- [Handshake e Estados da Sessão](04-sdh-host-architecture/01-handshake-e-estados-da-sessao.md)
- [Scheduler, Retry e Supervisão do Link](04-sdh-host-architecture/02-scheduler-retry-e-supervisao.md)
- [Fluxo GSA do Comando ao Evento](04-sdh-host-architecture/03-fluxo-gsa-do-comando-ao-evento.md)
- [Parsing e Tratamento de Respostas](04-sdh-host-architecture/04-parsing-e-tratamento-de-respostas.md)

## Glossário

- **SDH**: envelope semântico que a aplicação monta antes do envio.
- **SDGW**: enlace compacto e enquadrado que circula no fio.
- **Linked**: estado em que o handshake terminou e o supervisor do link já pode operar.

## Próximas camadas

- [Handshake e Estados da Sessão](04-sdh-host-architecture/01-handshake-e-estados-da-sessao.md)
- [Scheduler, Retry e Supervisão do Link](04-sdh-host-architecture/02-scheduler-retry-e-supervisao.md)
- [Fluxo GSA do Comando ao Evento](04-sdh-host-architecture/03-fluxo-gsa-do-comando-ao-evento.md)
- [Parsing e Tratamento de Respostas](04-sdh-host-architecture/04-parsing-e-tratamento-de-respostas.md)

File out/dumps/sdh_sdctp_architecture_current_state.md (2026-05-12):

# Levantamento Arquitetural SDH / SDCTP / SDGW / UCE Dispatcher / CanService

Data do levantamento: 2026-05-11

Escopo: API C# em `local-api/src/SimulDIESEL/SimulDIESEL`, firmware UCE e firmware BPM relacionados a SDH, SDGW, Dispatcher UCE, CAN, SDCTP e J1939.

Terminologia oficial: `SDCTP` = SimulDIESEL CAN Transport Protocol.

## 1. Resumo Executivo

Estado atual encontrado:

- A API ja possui uma camada SDH formal no host: `SdhCommand`, `SdhValidator`, `SdhClient`, `SdhToSdgwMapper`, parsers/serializers de texto e JSON.
- O fluxo de controle CAN da UCE passa por metodos de alto nivel da UI, `FrmUceLogic`, `SdctpApiService`/`IUceDispatcher`, `UceClient`, `BoardTlvDispatcher`, `SdhClient`, `SdhToSdgwMapper`, `SdgwSession` e finalmente SDGW/BPM/UCE.
- O SDGW da API (`SdGwLinkEngine`, `SdgwSession`) esta essencialmente puro como frame/transporte: COBS, CRC, ACK/ERR, flags, sequencia, eventos e entrega de frames.
- O firmware BPM tambem atua como gateway/roteador: recebe SDGW, roteia TLV para GSA/UCE, valida TLV e drena eventos da UCE por IRQ.
- A massa de dados CAN esta formalizada no codigo como `SDCTP`, mas a implementacao ainda e uma fachada sobre classes historicas: na API `SdctpApiService` envolve `ApiCanService`; no firmware UCE `SdctpService` envolve `CanService`; `SdctpCodec` e typedef de `CanCrudProtocol`.
- O Dispatcher UCE da API (`UceClient`/`UceDispatcher`) ainda faz parsing de eventos CAN_RX e CAN CRUD antes de repassar para o CanService API. Isso e parcialmente correto como roteamento, mas tambem concentra conhecimento de tipos TLV CAN no lado dispatcher.
- A UI nao consome TLV bruto nem SDGW diretamente para massa CAN. Ela consome `FrmUceLogic.TryReadRxFrame`, que drena o `CanRxOutputBuffer` via `SdctpApiService`/`ApiCanService`.

Principais desvios de responsabilidade:

- `SdctpApiService` tambem expoe comandos de controle CAN (`SetCanConfigAsync`, `SetCanEnabledAsync`, `GetCanStatusAsync`, `ResetCanAsync`, `PollCanDriverLogAsync`). Pelo modelo desejado, SDCTP deveria ficar restrito a massa/sincronizacao CAN, enquanto controle/operação deveria ser SDH.
- `SdhValidator` e `SdhToSdgwMapper` conhecem detalhes de CAN TX, flags, DATA_MASK, periodos, indices e payloads. Isso mistura a linguagem SDH de operacao com detalhes de contrato CAN/SDCTP.
- `UceClient.OnEventReceived` conhece e classifica `CAN_RX_EVENT`, `CAN_CREATE`, `CAN_EDIT`, `CAN_DELETE`, `CAN_ROW`, `CAN_READ_ALL_DONE`, `CAN_TIC` via `UceParsers`. E um roteamento funcional, mas o dispatcher ainda precisa conhecer a lista de eventos de massa CAN.
- `FrmUceLogic` contem servicos J1939 e decodificacao J1939 sobre frames CAN. Isso nao mistura SDGW, mas coloca protocolo de aplicacao automotiva na logica do formulario. Pode ser aceitavel como camada de aplicacao, mas nao e uma abstracao preparada para multiplos protocolos de forma neutra.
- A UI referencia `GwProtocol` para interpretar status de TX e logs de driver. Nao consome TLV bruto, mas conhece constantes de contrato de baixo nivel.

Riscos arquiteturais:

- Risco de confusao semantica: SDH, SDCTP e TLV usam os mesmos codigos definidos em `GwProtocol`, entao a separacao existe por classes, mas nao por contratos de namespace/domínio.
- Risco de crescimento acoplado: K-LINE/J1949/J1939 futuros podem acabar entrando em `GwProtocol`, `UceParsers`, `UceClient` e `FrmUceLogic` sem fronteira clara.
- Risco de manutencao: a camada chamada SDCTP e, em varios pontos, apenas uma fachada, o que pode esconder responsabilidades antigas em `ApiCanService`, `CanService` e `CanCrudProtocol`.
- Risco de duplicidade de comando CAN: controle CAN passa tanto por `IUceDispatcher` quanto por `SdctpApiService`, tornando ambigua a fronteira "controle SDH" versus "massa SDCTP".

## 2. Fluxo atual de controle/operação

Fluxo real encontrado para configuracao/operacao da UCE:

`UI UCE -> FrmUceLogic -> SdctpApiService ou IUceDispatcher -> UceDispatcher -> UceClient -> BoardTlvDispatcher -> SdhClient -> SdhValidator/SdhToSdgwMapper -> SdgwSession -> SdGwLinkEngine -> BPM Gateway -> UCE Transport -> UceServiceDispatcher -> SdctpService/CanService ou LedService -> Hardware`

Evidencias principais:

- UI chama logica de formulario, nao SDGW diretamente:
  - `frmUCE_UI.ApplyCanConfigAsync` chama `_logic.SetCanConfigAsync(...)` em `local-api/.../UI/frmUCE_UI.cs:442`.
  - `frmUCE_UI.ApplyCanEnabledAsync` chama `_logic.SetCanEnabledAsync(...)` em `local-api/.../UI/frmUCE_UI.cs:466`.
  - `frmUCE_UI.RefreshCanStatusAsync` chama `_logic.GetCanStatusAsync()` em `local-api/.../UI/frmUCE_UI.cs:487`.
  - `frmUCE_UI.BtnEnable_Click` envia CAN TX pela logica em `local-api/.../UI/frmUCE_UI.cs:272`.

- `FrmUceLogic` decide se usa dispatcher direto ou `SdctpApiService`:
  - LED: `SetBuiltinLedAsync` chama `_uceDispatcher.SetBuiltinLedAsync(...)`.
  - CAN config/enable/status/reset/driverLog/readAll/TX: metodos chamam `_sdctp.*` em `local-api/.../BLL/FormsLogic/UCE/FrmUceLogic.cs`.

- `SdctpApiService` delega controle CAN para `IUceDispatcher`:
  - `SetCanConfigAsync`, `SetCanEnabledAsync`, `GetCanStatusAsync`, `ResetCanAsync`, `PollCanDriverLogAsync` chamam `RequireDispatcher().*` em `local-api/.../BLL/Services/CAN/SDCTP/SdctpApiService.cs`.
  - `RequestReadAllAsync`, `SendDirectAsync`, `StartTxAsync`, `StopTxAsync`, `CreateTxRowAsync`, `EditTxRowAsync`, `DeleteTxRowAsync` passam pelo `ApiCanService`/`CanTxManager`.

- `UceDispatcher` e um repassador sobre `UceClient`:
  - Interface `IUceDispatcher` em `local-api/.../BLL/Boards/UCE/UceDispatcher.cs:7`.
  - Classe `UceDispatcher` em `local-api/.../BLL/Boards/UCE/UceDispatcher.cs:32`.
  - Eventos e metodos sao repassados para `_client` em `UceDispatcher.cs:39` e seguintes.

- `UceClient` cria comandos SDH internamente:
  - `CreateCanConfigCommand` em `local-api/.../BLL/Boards/UCE/UceClient.cs:410`.
  - `CreateCanReadAllCommand` em `local-api/.../BLL/Boards/UCE/UceClient.cs:475`.
  - `ExecuteOperationAsync` chama `BoardTlvDispatcher.TransactAsync` em `UceClient.cs:222`.

- `BoardTlvDispatcher` envia via `SdhClient` e aguarda resposta TLV:
  - Classe em `local-api/.../BLL/Boards/BoardTlvDispatcher.cs:9`.
  - `TransactAsync` em `BoardTlvDispatcher.cs:36`.
  - `OnFrameReceived` filtra resposta por comando compacto e matcher em `BoardTlvDispatcher.cs:78`.

- `SdhClient` valida e mapeia SDH para SDGW:
  - Classe em `local-api/.../DAL/Protocols/SDGW/SdhClient.cs:12`.
  - `SendAsync(SdhCommand...)` valida com `SdhValidator` e mapeia com `SdhToSdgwMapper` em `SdhClient.cs:44`.

- `SdhToSdgwMapper` converte SDH em TLV:
  - Classe em `local-api/.../DAL/Protocols/SDGW/SdhToSdgwMapper.cs:15`.
  - `MapUce` em `SdhToSdgwMapper.cs:132`.
  - `BuildTlvPayload` em `SdhToSdgwMapper.cs:292`.

- `SdgwSession` e `SdGwLinkEngine` transportam:
  - `SdgwSession.OnAppFrameReceived` converte AppFrame em `SdgwFrame` e separa evento por flag em `local-api/.../DAL/Protocols/SDGW/SdgwSession.cs:27`.
  - `SdGwLinkEngine.OnBytesReceived` faz RX COBS/CRC/ACK e entrega AppFrame em `local-api/.../DAL/Protocols/SDGW/SdgwLinkEngine.cs:146`.
  - `SdGwLinkEngine.SendWithSeq` faz TX com ACK/retry/timeout em `SdgwLinkEngine.cs:256`.

- Firmware BPM roteia:
  - `GatewayApp::onCommand` recebe comando SDGW e chama `_router.route(...)` em `hardware/.../BPM.../lib/Gateway/GatewayApp.cpp:34`.
  - `GwRouter::route` escolhe bus e faz transact para a board em `hardware/.../BPM.../lib/GwRouter/GwRouter.cpp:15`.

- Firmware UCE executa:
  - `UceTransport::poll` recebe pacote SPI, parseia TLV e chama `_dispatcher.dispatch(...)` em `hardware/.../UCE.../lib/core/transport/UceTransport.cpp:11`.
  - `UceServiceDispatcher::dispatch` roteia `CMD_CAN_*` para `_sdctp.handleTlv(...)` em `hardware/.../UCE.../lib/core/services/UceServiceDispatcher.cpp:22`.
  - `CanService::handleTlv` executa comandos CAN em `hardware/.../UCE.../lib/services/can/service/CanService.cpp:100`.

Diagnostico do fluxo de controle:

- O fluxo passa por SDH no host/API, mas a UI nao gera objeto/texto SDH diretamente. Ela chama servicos de alto nivel; `UceClient` gera SDH.
- A conversao SDH -> TLV esta centralizada em `SdhToSdgwMapper`.
- Ha ambiguidade: `SdctpApiService` tambem oferece operacoes de controle, entao o nome SDCTP aparece no caminho de controle.

## 3. Fluxo atual de massa de dados CAN

Fluxo real encontrado:

`UCE CAN RX -> CanDriver/CanRxHub/CanRxTableManager -> CanService -> CanCrudProtocol ou CAN_RX_EVENT -> UceServiceDispatcher event queue -> UceTransport -> BPM Gateway pollUceEvent/drainPendingUceEvents -> SDGW event -> SdgwSession.EventReceived -> UceClient.OnEventReceived -> UceParsers -> UceDispatcher events -> ApiCanService.OnCanRxEventReceived/OnCanCrudEventReceived -> CanEventProcessor/CanRxMirrorManager/CanRxOutputBuffer -> FrmUceLogic.TryReadRxFrame -> UI/J1939`

Evidencias principais:

- Firmware UCE coleta massa CAN:
  - `CanService::collectRxFrames` em `hardware/.../UCE.../lib/services/can/service/CanService.cpp:368`.
  - Usa `_rxHub.process(...)`, `_rxTable` e gera eventos CRUD.
  - `CanRxTableManager::processFrame` decide `CMD_CAN_CREATE`, `CMD_CAN_EDIT`, `CMD_CAN_TIC` em `hardware/.../UCE.../lib/services/can/table/CanRxTableManager.cpp:46`.
  - `CanService::checkRxTimeouts` gera `CMD_CAN_DELETE` por timeout.

- Firmware UCE codifica SDCTP/CanCrud:
  - `CanCrudProtocol::encodeCreate`, `encodeEdit`, `encodeTic`, `encodeDelete`, `encodeReadAllDone` em `hardware/.../UCE.../lib/services/can/protocol/CanCrudProtocol.cpp:7`.
  - `SdctpCodec.h` define `typedef CanCrudProtocol SdctpCodec` e `SdctpProtocol` em `hardware/.../UCE.../lib/services/can/sdctp/SdctpCodec.h:7`.

- Firmware UCE publica eventos:
  - `CanService::publishNextCrudEvent` em `hardware/.../UCE.../lib/services/can/service/CanService.cpp:543`.
  - `CanService::publishNextRxEvent` em `CanService.cpp:570`.
  - `UceServiceDispatcher::enqueueEvent` monta evento TLV `[type,len,value]` em `UceServiceDispatcher.cpp`.
  - `UceTransport::drainPendingEvent` monta pacote TLV para SPI.

- BPM drena eventos UCE:
  - `GwRouter::pollUceEvent` em `hardware/.../BPM.../lib/GwRouter/GwRouter.cpp:121`.
  - `GatewayApp::drainPendingUceEvents` envia `SDGW_CMD_UCE_TLV` como evento SDGW em `hardware/.../BPM.../lib/Gateway/GatewayApp.cpp:132`.

- API recebe eventos:
  - `SdgwSession.OnAppFrameReceived` dispara `EventReceived` se flag evento estiver setada em `local-api/.../DAL/Protocols/SDGW/SdgwSession.cs:27`.
  - `UceClient.OnEventReceived` filtra comando UCE, tenta `TryReadLedEvent`, `TryReadCanRxEvent`, `TryReadCanCrudEvent`, `TryReadTransportDiagnosticEvent` em `local-api/.../BLL/Boards/UCE/UceClient.cs:286`.
  - `UceParsers.TryReadCanRxEvent` em `local-api/.../BLL/Boards/UCE/UceParsers.cs:352`.
  - `UceParsers.TryReadCanCrudEvent` em `UceParsers.cs:434`.

- API CanService atualiza massa CAN:
  - `ApiCanService` se inscreve em `IUceDispatcher.CanRxEventReceived` e `CanCrudEventReceived` em `local-api/.../BLL/Services/CAN/ApiCanService.cs:51`.
  - `ApiCanService.OnCanRxEventReceived` processa evento direto e enfileira frames em `ApiCanService.cs:243`.
  - `ApiCanService.OnCanCrudEventReceived` chama `_eventProcessor.ProcessEvent(...)` e, se aplicavel, reconstrói frame da mirror table em `ApiCanService.cs:253`.
  - `CanEventProcessor.ProcessEvent` decodifica `CAN_CREATE`, `CAN_EDIT`, `CAN_DELETE`, `CAN_ROW`, `CAN_READ_ALL_DONE`, `CAN_TIC` em `local-api/.../BLL/Services/CAN/CanEventProcessor.cs:22`.
  - `CanRxMirrorManager.ApplyCreate`, `ApplyEdit`, `ApplyReadAllDone` ficam em `local-api/.../BLL/Services/CAN/CanRxMirrorManager.cs:75`, `:101`, `:247`.
  - `CanRxOutputBuffer.Enqueue` em `local-api/.../BLL/Services/CAN/CanRxOutputBuffer.cs:60`.

- UI consome buffer:
  - `frmUCE_UI.DrainCanRxOutputBuffer` chama `_logic.TryReadRxFrame(out frame)` em `local-api/.../UI/frmUCE_UI.cs:846`.
  - `FrmUceLogic.TryReadRxFrame` chama `_sdctp.TryReadRxFrame(out frame)`.
  - `ApiCanService.TryReadRxFrame` chama `_rxOutputBuffer.TryDequeue(out frame)` em `ApiCanService.cs:181`.
  - `frmUCE_UI.ProcessJ1939Frame` decodifica J1939 a partir de `CanFrameDto` em `frmUCE_UI.cs:860`.

Diagnostico do fluxo de massa:

- A UI nao recebe TLV bruto nem SDGW bruto para massa CAN.
- A massa passa pelo dispatcher, mas e desviada por eventos tipados (`CanRxEventReceived`, `CanCrudEventReceived`) para o `ApiCanService`.
- A logica equivalente ao SDCTP esta formalmente em `BLL/Services/CAN/SDCTP`, mas a implementacao real ainda esta em `ApiCanService`, `CanEventProcessor`, `CanRxMirrorManager`, `CanRxOutputBuffer` e `CanTxManager`.

## 4. Mapa de responsabilidades atual

| Componente | Responsabilidade esperada | Responsabilidade atual encontrada | Esta correto? | Observacao |
|---|---|---|---|---|
| UI UCE | Acionar casos de uso e consumir dados tratados | Chama `FrmUceLogic`; consome `CanFrameDto` via buffer; tambem interpreta alguns status `GwProtocol` e executa exibicao/decodificacao J1939 | Parcial | Nao consome TLV bruto, mas conhece constantes de contrato baixo nivel e concentra parte de exibicao J1939 |
| UceDispatcher API | Roteador/decodificador de comandos/eventos da UCE | `UceDispatcher` repassa `UceClient`; `UceClient` cria SDH, espera respostas e classifica eventos CAN/LED/diag | Parcial | Roteia bem, mas ainda conhece lista detalhada de eventos de massa CAN |
| SDH | Linguagem de configuracao/operacao do hardware | Existe como `SdhCommand`, validator, mapper e client; gerado internamente por `UceClient` | Parcial | Central para comandos, mas contem detalhes CAN TX/SDCTP e nao e gerado pela UI diretamente |
| SDGW | Transporte/gateway API <-> BPM <-> UCE | API: COBS/CRC/ACK/eventos. BPM: roteia TLV para UCE/GSA e retorna eventos | Sim | Nao foi encontrada regra CAN/J1939 na engine SDGW da API; BPM conhece apenas enderecos/bus/TLV |
| CanService API | Dono da massa CAN, buffers, mirror table e protocolo SDCTP | `ApiCanService` recebe eventos do dispatcher, atualiza mirror e `CanRxOutputBuffer`, controla TX | Parcial | Dono real da massa, mas nome oficial SDCTP e fachada; tambem dispara READ_ALL via dispatcher |
| CanEventProcessor | Decodificar eventos SDCTP/CanCrud e aplicar na mirror | Processa `CREATE/EDIT/DELETE/TIC/ROW/READ_ALL_DONE` e aplica em `CanRxMirrorManager` | Sim | Responsabilidade coerente com massa CAN |
| CanRxMirrorManager | Estado interno da tabela espelho CAN RX | Aplica create/edit/delete/tic/row/done, detecta out-of-sync | Sim | Bom isolamento de mirror table |
| CanRxOutputBuffer | Saida oficial de frames CAN para aplicacao/UI | Fila clonada e limitada; recebe frames diretos e reconstruidos | Sim | UI consome por `TryReadRxFrame` |
| UCE firmware dispatcher | Roteador de TLV para servicos da UCE | `UceServiceDispatcher` roteia LED para `LedService` e CAN para `SdctpService` | Parcial | CAN config/enable/status/readAll/TX todos entram no servico SDCTP/CanService |
| UCE CanService | Operar CAN fisico e massa SDCTP | Faz config/enable/status/reset, RX hub, CRUD, direct RX events, TX, readAll | Parcial | Agrega controle de hardware e massa CAN no mesmo servico |
| CanCrudProtocol / equivalente | Codec de compactacao/sincronizacao de massa CAN | Implementa payloads `CREATE/EDIT/TIC/DELETE/ROW/READ_ALL_DONE`; `SdctpCodec` e typedef | Sim | Contrato de massa bem localizado no firmware |
| J1939 services | Decodificar J1939 sobre frames CAN | `J1939ProtocolService` e servicos de diagnostico/rede sao usados por `FrmUceLogic` e UI | Parcial | Nao esta no SDGW; esta na camada de aplicacao/UI logic. Para multiplos protocolos, faltam fronteiras mais genericas |

## 5. Pontos de mistura indevida

### 5.1 SDCTP usado como fachada tambem para comandos de controle CAN

- Arquivo: `local-api/src/SimulDIESEL/SimulDIESEL/BLL/Services/CAN/SDCTP/SdctpApiService.cs`
- Classe: `SdctpApiService`
- Metodo: `SetCanConfigAsync`, `SetCanEnabledAsync`, `GetCanStatusAsync`, `ResetCanAsync`, `PollCanDriverLogAsync`
- Descricao do problema: a classe nomeada como entrypoint SDCTP expoe controle de hardware CAN e delega para `IUceDispatcher`.
- Impacto: embaralha a fronteira conceitual entre SDH (controle/operação) e SDCTP (massa/sincronizacao CAN).
- Sugestao conceitual: manter SDCTP apenas para RX/TX massa, mirror, output buffer, readAll/sync; expor controle CAN por facade de aplicacao/SDH com nome separado.

### 5.2 SDH conhece detalhes de frame CAN TX e DATA_MASK

- Arquivo: `local-api/src/SimulDIESEL/SimulDIESEL/DAL/Protocols/SDGW/SdhValidator.cs`
- Classe: `SdhValidator`
- Metodo: `ValidateUceCanTx`, `ValidateCanFrameArgs`, `ValidateUceCanTxEdit`
- Descricao do problema: valida flags, DLC, ID, DATA_MASK, periodos, indices e bytes `d0..d7`.
- Impacto: SDH deixa de ser apenas linguagem de operacao e passa a conhecer detalhes de contrato CAN/SDCTP.
- Sugestao conceitual: decidir se TX e comando operacional SDH ou parte do dominio CanService; se for SDH, documentar explicitamente como "controle TX"; se for massa/SDCTP, mover regras de baixo nivel para contrato SDCTP.

### 5.3 Mapper SDH monta TLVs de SDCTP/TX diretamente

- Arquivo: `local-api/src/SimulDIESEL/SimulDIESEL/DAL/Protocols/SDGW/SdhToSdgwMapper.cs`
- Classe: `SdhToSdgwMapper`
- Metodo: `MapUce`, `BuildUceCanTxDirectPayload`, `BuildUceCanTxCreatePayload`, `BuildUceCanTxEditPayload`
- Descricao do problema: mapeador SDH monta payloads CAN TX direct/create/edit/delete e `CAN_READ_ALL`.
- Impacto: acopla SDH ao layout binario CAN/SDCTP.
- Sugestao conceitual: separar comandos de operacao de hardware de payloads de transporte de massa; usar builder/codec dedicado ao dominio CAN quando a montagem for inevitavel.

### 5.4 Dispatcher API classifica eventos de massa CAN

- Arquivo: `local-api/src/SimulDIESEL/SimulDIESEL/BLL/Boards/UCE/UceClient.cs`
- Classe: `UceClient`
- Metodo: `OnEventReceived`
- Descricao do problema: o client/dispatcher tenta `TryReadCanRxEvent` e `TryReadCanCrudEvent`, depois publica eventos especificos.
- Impacto: o dispatcher precisa conhecer todos os tipos de massa CAN para desviar corretamente.
- Sugestao conceitual: manter no dispatcher apenas classificacao minima por dominio/protocolo, por exemplo "TLV pertence ao dominio SDCTP", e entregar payload bruto desse dominio ao CanService/SDCTP.

### 5.5 Parser UCE contem parsers detalhados de massa CAN

- Arquivo: `local-api/src/SimulDIESEL/SimulDIESEL/BLL/Boards/UCE/UceParsers.cs`
- Classe: `UceParsers`
- Metodo: `TryReadCanRxEvent`, `TryReadCanCrudEvent`, `TryReadCanReadAllResponse`
- Descricao do problema: parser de board UCE conhece layout de eventos de massa CAN.
- Impacto: parser do dispatcher cresce junto com protocolos de massa.
- Sugestao conceitual: mover parsers de massa para namespace SDCTP/CanService e deixar `UceParsers` apenas para respostas de controle ou envelope minimo.

### 5.6 UI conhece constantes `GwProtocol`

- Arquivo: `local-api/src/SimulDIESEL/SimulDIESEL/UI/frmUCE_UI.cs`
- Classe: `frmUCE_UI`
- Metodo: `BtnEnable_Click`, `StopCanTxAsync`, `DescribeDriverEvent`, `FormatDriverEventDetail`
- Descricao do problema: UI compara status de TX e eventos de driver por constantes `GwProtocol`.
- Impacto: UI nao consome TLV bruto, mas conhece contrato de baixo nivel.
- Sugestao conceitual: mover traducao de status/eventos para DTOs ou servico de apresentacao da BLL.

### 5.7 Firmware UCE `CanService` agrega controle e massa

- Arquivo: `hardware/firmware/UCE - Unidade de comunicacao externa/lib/services/can/service/CanService.cpp`
- Classe: `CanService`
- Metodo: `handleTlv`, `collectRxFrames`, `handleReadAll`, `handleTx*`
- Descricao do problema: o mesmo servico trata config/enable/status/reset, RX massa, CRUD, TX direct/table e readAll.
- Impacto: no firmware, a separacao SDH x SDCTP ainda e interna/nominal; a classe concentra controle e massa.
- Sugestao conceitual: em etapa futura, separar "CAN control service" de "SDCTP RX/TX stream/sync service", mantendo os mesmos codigos ate estabilizar.

### 5.8 J1939 acoplado a logica de formulario

- Arquivo: `local-api/src/SimulDIESEL/SimulDIESEL/BLL/FormsLogic/UCE/FrmUceLogic.cs`
- Classe: `FrmUceLogic`
- Metodo: `TryDecodeJ1939Frame`, `TryProcessJ1939NetworkFrame`, `RequestJ1939DiagnosticCodesAsync`
- Descricao do problema: servicos J1939 sao instanciados diretamente na logica da tela UCE.
- Impacto: novos protocolos (K-LINE/J1949) podem entrar na mesma classe e misturar casos de uso.
- Sugestao conceitual: criar uma camada de aplicacao/protocolos automotivos acima do `CanRxOutputBuffer`, sem colocar isso no SDGW nem no dispatcher.

Nao foram encontradas evidencias fortes de:

- UI consumindo TLV bruto diretamente para massa CAN.
- SDGW API contendo regra CAN/J1939.
- CanService API dependendo da UI.

## 6. Contratos e codigos TLV envolvidos

Fonte principal API: `local-api/src/SimulDIESEL/SimulDIESEL/DTL/Protocols/SDGW/GwProtocol.cs`.

Fonte firmware UCE: `hardware/firmware/UCE - Unidade de comunicacao externa/include/defs.h`.

| Codigo | Nome simbolico API | Nome firmware UCE | Quem envia | Quem recebe | Dominio diagnosticado |
|---|---|---|---|---|---|
| `0x12` | `UceSetLedType` | `CMD_LED_BUILTIN` | API/UceClient via SDH | UCE `LedService` | SDH/controle |
| `0x13` | `UceLedEventType` | `CMD_LED_EVENT` | UCE | API/UceClient/UI | Evento controle |
| `0x20` | `UceCanConfigType` | `CMD_CAN_CONFIG` | API via SDH | UCE `CanService::handleConfig` | SDH/controle CAN |
| `0x21` | `UceCanEnableType` | `CMD_CAN_ENABLE` | API via SDH | UCE `CanService::handleEnable` | SDH/controle CAN |
| `0x22` | `UceCanStatusType` | `CMD_CAN_STATUS` | API via SDH | UCE `CanService::handleStatus` | SDH/controle CAN |
| `0x23` | `UceCanResetType` | `CMD_CAN_RESET` | API via SDH | UCE `CanService::handleReset` | SDH/controle CAN |
| `0x24` | `UceCanRxPollType` | `CMD_CAN_RX_POLL` | API via SDH | UCE `CanService::handleRxPoll` | Ambiguo: controle/poll legado de RX |
| `0x25` | `UceCanDriverLogPollType` | `CMD_CAN_DRIVER_LOG_POLL` | API via SDH | UCE `CanService::handleDriverLogPoll` | Diagnostico/controle |
| `0x26` | `UceCanTxType` | `CMD_CAN_TX` | API via SDH | UCE `CanService::handleTx` | Ambiguo/legado TX |
| `0x27` | `UceCanTxStopType` | `CMD_CAN_TX_STOP` | API via SDH | UCE `CanService::handleTxStop` | Controle TX |
| `0x28` | `UceCanRxEventType` | `CMD_CAN_RX_EVENT` | UCE `CanService::publishNextRxEvent` | API `UceClient` -> `ApiCanService` | SDCTP/massa CAN direta |
| `0x40` | `UceCanCreateType` | `CMD_CAN_CREATE` | UCE `CanService`/`CanRxTableManager` | API `CanEventProcessor` | SDCTP/massa CAN |
| `0x41` | `UceCanEditType` | `CMD_CAN_EDIT` | UCE `CanService`/`CanRxTableManager` | API `CanEventProcessor` | SDCTP/massa CAN |
| `0x42` | `UceCanDeleteType` | `CMD_CAN_DELETE` | UCE timeout/table | API `CanEventProcessor` | SDCTP/massa CAN |
| `0x43` | `UceCanReadAllType` | `CMD_CAN_READ_ALL` | API `ApiCanService.RequestReadAllAsync` via dispatcher/SDH | UCE `CanService::handleReadAll` | Ambiguo: comando SDH que dispara sync SDCTP |
| `0x44` | `UceCanRowType` | `CMD_CAN_ROW` | UCE `handleReadAll` | API `CanEventProcessor.ApplyRow` | SDCTP/massa CAN |
| `0x45` | `UceCanReadAllDoneType` | `CMD_CAN_READ_ALL_DONE` | UCE `handleReadAll` | API `CanEventProcessor.ApplyReadAllDone` | SDCTP/massa CAN |
| `0x46` | `UceCanTicType` | `CMD_CAN_TIC` | UCE `CanRxTableManager` | API `CanEventProcessor.ApplyTic` | SDCTP/massa CAN |
| `0x50` | `UceCanTxDirectType` | `CMD_CAN_TX_DIRECT` | API `CanTxManager`/SDH | UCE `CanService::handleTxDirect` | Ambiguo: operacao TX via CAN service |
| `0x51` | `UceCanTxCreateType` | `CMD_CAN_TX_CREATE` | API `CanTxManager`/SDH | UCE `CanService::handleTxCreate` | Ambiguo: tabela TX, controle/SDCTP |
| `0x52` | `UceCanTxEditType` | `CMD_CAN_TX_EDIT` | API `CanTxManager`/SDH | UCE `CanService::handleTxEdit` | Ambiguo: tabela TX, controle/SDCTP |
| `0x53` | `UceCanTxDeleteType` | `CMD_CAN_TX_DELETE` | API `CanTxManager`/SDH | UCE `CanService::handleTxDelete` | Ambiguo: tabela TX, controle/SDCTP |
| `0x7E` | `UceTransportDiagType` | `CMD_TRANSPORT_DIAG` | UCE dispatcher | API `UceClient`/`ApiCanService` | Diagnostico transporte/dispatcher |
| `0x7F` | `UceErrorType` | `CMD_FUNCTIONAL_ERROR` | UCE | API parser | Erro funcional |
| `0xFE` | `GatewayErrorType` | `SDGW_TLV_GATEWAY_ERR` no BPM | BPM gateway | API `UceParsers.TryReadGatewayError` | SDGW/erro gateway |

J1939:

- Nao ha TLV UCE especifico `0x81` encontrado no codigo analisado.
- J1939 e tratado como protocolo decodificado sobre `CanFrameDto` pela API:
  - `J1939ProtocolService.ProcessCanFrame` em `local-api/.../BLL/Protocols/J1939/J1939ProtocolService.cs:23`.
  - `FrmUceLogic.TryDecodeJ1939Frame` chama `_j1939Protocol.ProcessCanFrame(frame)` em `FrmUceLogic.cs:253`.
  - `frmUCE_UI.ProcessJ1939Frame` consome `CanFrameDto`, nao TLV, em `frmUCE_UI.cs:860`.

## 7. Diagnostico SDH

- SDH esta realmente centralizado?
  - Parcialmente. O modelo `SdhCommand`, validacao e mapeamento estao centralizados em `DTL/DAL/Protocols/SDGW`. Entretanto, a geracao dos comandos UCE esta dentro de `UceClient` e os detalhes CAN TX estao no validator/mapper.

- SDH e usado como linguagem de operacao do hardware?
  - Sim para LED, CAN config, enable, status, reset, driverLog, TX e readAll no caminho de comandos da API.

- A UI gera SDH ou pula essa camada?
  - A UI nao gera SDH diretamente. Ela chama `FrmUceLogic`, que chama `SdctpApiService` ou `IUceDispatcher`. O SDH e criado dentro de `UceClient` pelos metodos `Create*Command`.

- O Dispatcher converte SDH para TLV de forma clara?
  - A conversao clara esta em `SdhToSdgwMapper`, nao no `UceDispatcher` em si. O `BoardTlvDispatcher` envia o `SdhCommand` ao `SdhClient`, que valida e mapeia.

- Existem comandos de controle fora do SDH?
  - No caminho API analisado, comandos UCE passam por `UceClient`/SDH. A ambiguidade e de nomenclatura: chamadas de controle passam por `SdctpApiService` antes de chegar ao dispatcher.

## 8. Diagnostico SDCTP

- Existe protocolo formal para massa CAN?
  - Sim. O nome oficial e `SDCTP` = SimulDIESEL CAN Transport Protocol.

- O nome usado no codigo e SDCTP, CanCrudProtocol ou outro?
  - API: `BLL/Services/CAN/SDCTP/*`, `SdctpApiService`, `SdctpProtocol`, `SdctpEventProcessor`, `SdctpRxMirrorManager`.
  - Firmware UCE: `services/can/sdctp/*`, `SdctpService`, `SdctpCodec`, `SdctpProtocol`.
  - Implementacao historica/subjacente: `ApiCanService`, `CanEventProcessor`, `CanRxMirrorManager`, `CanRxOutputBuffer`, `CanTxManager`, `CanCrudProtocol`, `CanService`.

- O protocolo esta isolado no CanService?
  - Parcialmente. A massa RX esta no `ApiCanService`/`CanEventProcessor`/`CanRxMirrorManager`/`CanRxOutputBuffer`; a fachada oficial `SdctpApiService` envolve isso. No firmware, `SdctpService` e wrapper de `CanService`.

- Eventos CAN sao desviados corretamente pelo Dispatcher para o CanService?
  - Sim em termos funcionais: `UceClient` identifica eventos e `UceDispatcher` repassa; `ApiCanService` assina eventos do dispatcher. Mas o dispatcher ainda conhece tipos e parsing de massa CAN.

- A aplicacao consome buffer RX ou consome TLV bruto?
  - Consome buffer RX. `frmUCE_UI.DrainCanRxOutputBuffer` chama `_logic.TryReadRxFrame`, que chega ao `CanRxOutputBuffer.TryDequeue`.

## 9. Diagnostico SDGW

- SDGW esta puro como gateway/transporte?
  - API: sim. `SdGwLinkEngine` trata framing, COBS, CRC, ACK/ERR, sequencia, retries e entrega de frames.
  - BPM: majoritariamente sim. `GatewayApp` e `GwRouter` roteiam por endereco/bus e validam TLV; nao foi encontrada regra CAN/J1939 no gateway.

- SDGW tem conhecimento indevido de CAN/J1939?
  - Nao na API. No BPM, ha conhecimento de endereco UCE/GSA e diagnostico de erro SPI, mas nao de semantica CAN/J1939.

- SDGW depende de SDH ou SDCTP alem do transporte bruto?
  - `SdGwLinkEngine` nao. `SdgwSession` tambem nao. A dependencia semantica esta acima, em `SdhClient`, `UceClient` e `BoardTlvDispatcher`.

## 10. Preparacao para protocolos futuros

K-LINE:

- A arquitetura de transporte SDGW poderia carregar TLVs de K-LINE sem mudancas conceituais no link.
- O risco esta em adicionar K-LINE em `GwProtocol`, `UceParsers`, `UceClient`, `FrmUceLogic` e `CanService` sem criar um servico/protocolo separado.

J1939:

- Ja existe decodificacao J1939 sobre `CanFrameDto`, e isso e positivo porque nao polui SDGW.
- A decodificacao esta em `FrmUceLogic`/UI logic; para escalar, deveria ser um consumidor separado do `CanRxOutputBuffer`.

J1949:

- Nao foi encontrado contrato especifico J1949 no codigo analisado.
- Se for sobre CAN, deve consumir `CanFrameDto` do buffer como J1939. Se exigir transporte proprio, precisa de servico separado.

Outros protocolos automotivos:

- O SDGW esta preparado como transporte generico.
- A camada de aplicacao ainda nao tem uma abstracao generica clara para "protocolos consumidores de fluxo CAN" versus "servicos de controle de hardware".
- Recomendacao conceitual: manter quatro eixos separados: comando/controle (SDH), transporte/gateway (SDGW), massa CAN (SDCTP), decoders automotivos (J1939/K-LINE/J1949/etc.).

## 11. Proposta de ETAPAS de correcao

Nao implementar nesta etapa.

ETAPA 01 - Congelar contratos atuais e documentar nomes oficiais

- Documentar oficialmente `SDCTP` como SimulDIESEL CAN Transport Protocol.
- Documentar que `CanCrudProtocol` e codec interno do protocolo oficial, se essa for a decisao.
- Documentar quais codigos TLV pertencem a SDH/controle, SDCTP/massa, SDGW/erro.

ETAPA 02 - Formalizar separacao SDH x SDCTP x SDGW

- SDH: comandos operacionais.
- SDCTP: massa CAN RX/TX/sync.
- SDGW: transporte.
- Evitar nomes de fachada que misturem controle com massa.

ETAPA 03 - Corrigir fluxo de comandos da UI para SDH

- Manter UI chamando casos de uso, mas garantir que comandos de controle aparecam em facade de aplicacao/SDH, nao em `SdctpApiService`.

ETAPA 04 - Corrigir desvio de massa CAN para CanService

- Reduzir conhecimento de massa CAN no `UceClient`/`UceParsers`.
- Dispatcher deve rotear por dominio; CanService/SDCTP deve decodificar payloads de massa.

ETAPA 05 - Isolar SDCTP dentro do CanService

- Mover parsers/constantes de massa para namespace SDCTP.
- Transformar `ApiCanService` em implementacao interna ou renomear apenas em etapa planejada.

ETAPA 06 - Garantir que UI consuma apenas CanRxOutputBuffer

- Remover dependencias diretas da UI para `GwProtocol` quando forem apenas display/status.
- Fornecer DTOs de apresentacao para TX status e driver log.

ETAPA 07 - Preparar abstracao para K-LINE/J1939/J1949

- Criar consumidores de frames/eventos separados da tela.
- J1939 deve continuar sobre `CanFrameDto`, sem passar por SDGW/TLV.

ETAPA 08 - Criar testes/harness de validacao arquitetural

- Testes de mapeamento SDH -> TLV.
- Testes de roteamento de eventos SDCTP -> mirror/output buffer.
- Testes de que UI nao referencia SDGW/TLV bruto.
- Testes de que SDGW nao referencia protocolos de aplicacao.

## 12. Arquivos analisados

API C#:

- `local-api/src/SimulDIESEL/SimulDIESEL/DTL/Protocols/SDGW/GwProtocol.cs`
- `local-api/src/SimulDIESEL/SimulDIESEL/DTL/Protocols/SDGW/SdhCommand.cs`
- `local-api/src/SimulDIESEL/SimulDIESEL/DAL/Protocols/SDGW/SdhClient.cs`
- `local-api/src/SimulDIESEL/SimulDIESEL/DAL/Protocols/SDGW/SdhValidator.cs`
- `local-api/src/SimulDIESEL/SimulDIESEL/DAL/Protocols/SDGW/SdhToSdgwMapper.cs`
- `local-api/src/SimulDIESEL/SimulDIESEL/DAL/Protocols/SDGW/SdgwSession.cs`
- `local-api/src/SimulDIESEL/SimulDIESEL/DAL/Protocols/SDGW/SdgwLinkEngine.cs`
- `local-api/src/SimulDIESEL/SimulDIESEL/DAL/Protocols/SDGW/SdgwFrameCodec.cs`
- `local-api/src/SimulDIESEL/SimulDIESEL/BLL/Boards/BoardTlvDispatcher.cs`
- `local-api/src/SimulDIESEL/SimulDIESEL/BLL/Boards/UCE/UceClient.cs`
- `local-api/src/SimulDIESEL/SimulDIESEL/BLL/Boards/UCE/UceDispatcher.cs`
- `local-api/src/SimulDIESEL/SimulDIESEL/BLL/Boards/UCE/UceParsers.cs`
- `local-api/src/SimulDIESEL/SimulDIESEL/BLL/Boards/UCE/UceGatewayDiagnosticLog.cs`
- `local-api/src/SimulDIESEL/SimulDIESEL/BLL/FormsLogic/UCE/FrmUceLogic.cs`
- `local-api/src/SimulDIESEL/SimulDIESEL/UI/frmUCE_UI.cs`
- `local-api/src/SimulDIESEL/SimulDIESEL/BLL/Services/CAN/ApiCanService.cs`
- `local-api/src/SimulDIESEL/SimulDIESEL/BLL/Services/CAN/CanEventProcessor.cs`
- `local-api/src/SimulDIESEL/SimulDIESEL/BLL/Services/CAN/CanRxMirrorManager.cs`
- `local-api/src/SimulDIESEL/SimulDIESEL/BLL/Services/CAN/CanRxOutputBuffer.cs`
- `local-api/src/SimulDIESEL/SimulDIESEL/BLL/Services/CAN/CanTxManager.cs`
- `local-api/src/SimulDIESEL/SimulDIESEL/BLL/Services/CAN/SDCTP/SdctpApiService.cs`
- `local-api/src/SimulDIESEL/SimulDIESEL/BLL/Services/CAN/SDCTP/SdctpProtocol.cs`
- `local-api/src/SimulDIESEL/SimulDIESEL/BLL/Services/CAN/SDCTP/SdctpEventProcessor.cs`
- `local-api/src/SimulDIESEL/SimulDIESEL/BLL/Services/CAN/SDCTP/SdctpRxMirrorManager.cs`
- `local-api/src/SimulDIESEL/SimulDIESEL/BLL/Services/CAN/SDCTP/SdctpRxOutputBuffer.cs`
- `local-api/src/SimulDIESEL/SimulDIESEL/BLL/Protocols/ProtocolDecoderGateway.cs`
- `local-api/src/SimulDIESEL/SimulDIESEL/BLL/Protocols/J1939/J1939ProtocolService.cs`
- Arquivos J1939 sob `BLL/Protocols/J1939/*` e DTOs J1939 sob `DTL/Protocols/J1939/*` por busca/simbolos.
- DTOs CAN sob `local-api/src/SimulDIESEL/SimulDIESEL/DTL/Boards/UCE/Can/*`.
- DTOs UCE sob `local-api/src/SimulDIESEL/SimulDIESEL/DTL/Boards/UCE/*`.

Firmware UCE:

- `hardware/firmware/UCE - Unidade de comunicacao externa/include/defs.h`
- `hardware/firmware/UCE - Unidade de comunicacao externa/src/main.cpp`
- `hardware/firmware/UCE - Unidade de comunicacao externa/lib/core/transport/UceTransport.cpp`
- `hardware/firmware/UCE - Unidade de comunicacao externa/lib/core/transport/UceTransport.h`
- `hardware/firmware/UCE - Unidade de comunicacao externa/lib/core/services/UceServiceDispatcher.cpp`
- `hardware/firmware/UCE - Unidade de comunicacao externa/lib/core/services/UceServiceDispatcher.h`
- `hardware/firmware/UCE - Unidade de comunicacao externa/lib/services/can/service/CanService.cpp`
- `hardware/firmware/UCE - Unidade de comunicacao externa/lib/services/can/service/CanService.h`
- `hardware/firmware/UCE - Unidade de comunicacao externa/lib/services/can/protocol/CanCrudProtocol.cpp`
- `hardware/firmware/UCE - Unidade de comunicacao externa/lib/services/can/protocol/CanCrudProtocol.h`
- `hardware/firmware/UCE - Unidade de comunicacao externa/lib/services/can/table/CanRxTableManager.cpp`
- `hardware/firmware/UCE - Unidade de comunicacao externa/lib/services/can/table/CanRxTableManager.h`
- `hardware/firmware/UCE - Unidade de comunicacao externa/lib/services/can/table/CanTxTableManager.cpp`
- `hardware/firmware/UCE - Unidade de comunicacao externa/lib/services/can/table/CanTxTableManager.h`
- `hardware/firmware/UCE - Unidade de comunicacao externa/lib/services/can/rxhub/CanRxHub.cpp`
- `hardware/firmware/UCE - Unidade de comunicacao externa/lib/services/can/rxhub/CanRxHub.h`
- `hardware/firmware/UCE - Unidade de comunicacao externa/lib/services/can/sdctp/SdctpService.h`
- `hardware/firmware/UCE - Unidade de comunicacao externa/lib/services/can/sdctp/SdctpCodec.h`
- `hardware/firmware/UCE - Unidade de comunicacao externa/lib/services/can/sdctp/SdctpRxTableManager.h`
- `hardware/firmware/UCE - Unidade de comunicacao externa/lib/services/can/sdctp/SdctpTxTableManager.h`
- `hardware/firmware/UCE - Unidade de comunicacao externa/lib/services/can/sdctp/SdctpTypes.h`

Firmware BPM:

- `hardware/firmware/BPM - BACKPLANE MANAGER MODULE/include/SdgwDefs.h`
- `hardware/firmware/BPM - BACKPLANE MANAGER MODULE/lib/Gateway/GatewayApp.cpp`
- `hardware/firmware/BPM - BACKPLANE MANAGER MODULE/lib/Gateway/GatewayApp.h`
- `hardware/firmware/BPM - BACKPLANE MANAGER MODULE/lib/GwRouter/GwRouter.cpp`
- `hardware/firmware/BPM - BACKPLANE MANAGER MODULE/lib/GwRouter/GwRouter.h`
- `hardware/firmware/BPM - BACKPLANE MANAGER MODULE/lib/GwTlv/GwTlv.cpp`
- `hardware/firmware/BPM - BACKPLANE MANAGER MODULE/lib/GwTlv/GwTlv.h`
- `hardware/firmware/BPM - BACKPLANE MANAGER MODULE/lib/SdgwLink/SdgwLink.cpp`
- `hardware/firmware/BPM - BACKPLANE MANAGER MODULE/lib/SdgwLink/SdgwLink.h`
- `hardware/firmware/BPM - BACKPLANE MANAGER MODULE/lib/SdgwParser/SdgwParser.cpp`
- `hardware/firmware/BPM - BACKPLANE MANAGER MODULE/lib/SdgwParser/SdgwParser.h`

## 13. Conclusao

O que esta correto:

- SDGW na API esta bem separado como transporte/frame/ACK/evento.
- SDH existe como camada formal de comando no host/API.
- Massa CAN chega na UI por `CanRxOutputBuffer`, nao por TLV bruto.
- `CanEventProcessor`, `CanRxMirrorManager` e `CanRxOutputBuffer` formam um nucleo coerente para massa CAN na API.
- Firmware BPM atua majoritariamente como gateway, sem regra CAN/J1939 aparente.
- J1939 e decodificado a partir de `CanFrameDto`, nao dentro do SDGW.

O que esta errado ou desalinhado com o paradigma desejado:

- `SdctpApiService` esta sendo usado tambem como facade de controle CAN.
- `SdhValidator` e `SdhToSdgwMapper` conhecem detalhes profundos de payload CAN/SDCTP.
- `UceClient`/`UceParsers` conhecem e parseiam eventos de massa CAN em vez de apenas rotear para o dominio SDCTP/CanService.
- Firmware UCE `CanService` mistura controle de hardware CAN e massa SDCTP na mesma classe.
- UI conhece constantes `GwProtocol` em alguns pontos de status/log.

O que esta ambiguo:

- Se `CAN_TX_DIRECT`, `CAN_TX_CREATE`, `CAN_TX_EDIT`, `CAN_TX_DELETE` devem ser SDH/controle operacional ou SDCTP/TX table. O codigo atual trata como comando SDH que passa por CanService.
- Se `CAN_READ_ALL` deve ser considerado comando SDH de solicitacao ou parte integral do protocolo SDCTP. Atualmente e um comando SDH que dispara eventos SDCTP.
- Se a UI logic deve continuar sendo dona da decodificacao J1939 ou se deve existir uma camada de consumidores de protocolo acima do buffer CAN.

O que precisa ser decidido antes de alterar codigo:

- Nome oficial do protocolo de massa CAN: `SDCTP` = SimulDIESEL CAN Transport Protocol.
- Lista oficial de TLVs pertencentes a SDH, SDCTP e SDGW.
- Fronteira de TX CAN: comando de operacao SDH ou parte de SDCTP.
- Fronteira do dispatcher: parser detalhado de eventos CAN ou roteador por dominio.
- Fronteira de protocolos futuros: onde entram K-LINE, J1939 e J1949 sem acoplar UI, dispatcher e transporte.

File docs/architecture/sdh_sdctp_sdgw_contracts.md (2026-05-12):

# Contratos Arquiteturais SDH / SDCTP / SDGW

Documento oficial de congelamento arquitetural da ETAPA 01.

Base de referencia: levantamento arquitetural corrente gerado antes da ETAPA 01.

## 1. Nomenclatura oficial

- SDH: SimulDIESEL Hardware Language
- SDCTP: SimulDIESEL CAN Transport Protocol
- SDGW: SimulDIESEL Gateway

O termo correto e oficial e SDCTP.

Qualquer ocorrencia antiga com letras invertidas deve ser tratada como erro de digitacao em documentacao historica.

## 2. Responsabilidade de cada camada

### SDH

SDH e a linguagem de configuracao e operacao do hardware.

Pertencem ao SDH:

- Configurar bitrate CAN
- Configurar modo CAN
- Abrir, fechar, habilitar ou desabilitar CAN
- Solicitar status CAN
- Resetar servico CAN
- Operar LED e service commands
- Comandos futuros de configuracao ou operacao de hardware

Nao pertencem ao SDH:

- Trafego continuo de massa CAN RX
- CAN_CREATE
- CAN_EDIT
- CAN_DELETE
- CAN_ROW
- CAN_TIC
- Sincronizacao da tabela RX CAN
- Compactacao DATA_MASK de massa RX

### SDCTP

SDCTP e o protocolo de transporte, compactacao e sincronizacao de massa de dados CAN.

Pertencem ao SDCTP:

- CAN_RX_EVENT
- CAN_CREATE
- CAN_EDIT
- CAN_DELETE
- CAN_ROW
- CAN_READ_ALL_DONE
- CAN_TIC
- CAN_TX
- CAN_TX_STOP
- CAN_TX_DIRECT
- CAN_TX_CREATE
- CAN_TX_EDIT
- CAN_TX_DELETE
- Mirror table RX
- Mirror/buffer table TX
- CanRxOutputBuffer
- Compactacao por DATA_MASK
- Sincronizacao de massa CAN RX/TX entre UCE e API

TX CAN segue o mesmo paradigma de massa/sincronizacao do RX CAN. O CanService possui lado RX e lado TX: RX alimenta mirror table e `CanRxOutputBuffer`; TX utiliza tabela/buffer local para envio direto, envio ciclico e manutencao de linhas TX.

`CAN_READ_ALL` e legado. O fluxo oficial nao deve solicitar `CAN_READ_ALL` para funcionamento da UI/API; consumidores devem usar `CanRxOutputBuffer`, snapshot local da mirror table e eventos SDCTP. `CAN_READ_ALL_DONE` pode permanecer apenas como compatibilidade tecnica de evento recebido enquanto o firmware ainda puder emiti-lo.

Nao pertencem ao SDCTP:

- Framing SDGW
- ACK/ERR SDGW
- COBS/CRC SDGW
- Regra de UI
- Decodificacao J1939, K-LINE ou outros protocolos automotivos de aplicacao

### SDGW

SDGW e o gateway/transporte puro entre API, BPM e UCE.

Pertencem ao SDGW:

- Framing
- COBS
- CRC
- ACK/ERR
- Sequencia
- Retry
- Timeout
- Transporte de TLVs
- Entrega de eventos

Nao pertencem ao SDGW:

- Regra CAN
- Regra J1939
- Regra K-LINE
- Decodificacao de massa CAN
- Decodificacao de PGN
- Regra de UI
- Regra de aplicacao

## 3. Fluxos oficiais

### Fluxo de controle/operação

```text
UI / Aplicacao
-> caso de uso BLL
-> comando SDH
-> Dispatcher UCE API
-> conversao SDH para TLV
-> SDGW
-> BPM gateway
-> UCE dispatcher
-> servico de hardware
-> resposta
```

### Fluxo de massa CAN RX

```text
Interface CAN UCE
-> CanService UCE
-> SDCTP
-> TLV de massa CAN
-> SDGW
-> Dispatcher UCE API
-> roteamento para CanService API / SDCTP
-> mirror table / CanRxOutputBuffer
-> aplicacao/UI consome CanFrameDto
```

## 4. Regras de fronteira

1. UI nao deve consumir TLV bruto.
2. UI nao deve conhecer SDGW para massa CAN.
3. UI deve consumir massa CAN por DTO/buffer de aplicacao.
4. SDGW nao deve conhecer CAN, J1939, K-LINE ou protocolos automotivos.
5. Dispatcher UCE deve rotear por dominio, nao concentrar regra de massa CAN.
6. SDH deve ser usado para operacao/configuracao de hardware.
7. SDCTP deve ser usado para massa/sincronizacao CAN.
8. CanService API deve ser o dono da mirror table e do CanRxOutputBuffer.
9. Decoders como J1939 devem consumir CanFrameDto, nunca TLV bruto.
10. Protocolos futuros devem entrar como dominios proprios, sem poluir SDGW.

## 5. Classificação inicial dos TLVs

| Codigo | Nome | Dominio oficial | Situacao | Observacao |
|---|---|---|---|---|
| `0x12` | LED | SDH / Controle | Congelado | Operacao de LED/service command |
| `0x20` | CAN_CONFIG | SDH / Controle | Congelado | Configura bitrate, modo e parametros de operacao CAN |
| `0x21` | CAN_ENABLE | SDH / Controle | Congelado | Habilita, desabilita, abre ou fecha CAN |
| `0x22` | CAN_STATUS | SDH / Controle | Congelado | Solicita estado atual do servico CAN |
| `0x23` | CAN_RESET | SDH / Controle | Congelado | Reseta servico/porta CAN |
| `0x25` | CAN_DRIVER_LOG_POLL | SDH / Controle | Congelado | Diagnostico operacional do driver CAN |
| `0x28` | CAN_RX_EVENT | SDCTP / Massa CAN | Congelado | Evento de frame CAN RX direto |
| `0x40` | CAN_CREATE | SDCTP / Massa CAN | Congelado | Criacao de entrada na mirror table RX |
| `0x41` | CAN_EDIT | SDCTP / Massa CAN | Congelado | Atualizacao compactada de entrada RX |
| `0x42` | CAN_DELETE | SDCTP / Massa CAN | Congelado | Remocao/invalidation de entrada RX |
| `0x44` | CAN_ROW | SDCTP / Massa CAN | Congelado | Linha de snapshot RX |
| `0x45` | CAN_READ_ALL_DONE | SDCTP / Massa CAN | Compatibilidade legada | Marcador recebido de conclusao de sincronizacao RX; nao deve depender de solicitacao nova de CAN_READ_ALL |
| `0x46` | CAN_TIC | SDCTP / Massa CAN | Congelado | Evento de vida/recorrencia de entrada RX |
| `0x24` | CAN_RX_POLL | Ambiguo / Pendente | Pendente | Poll legado de RX; fronteira oficial ainda nao congelada |
| `0x26` | CAN_TX | SDCTP / Massa CAN TX | Legado | TX legado; manter apenas enquanto houver compatibilidade com contrato antigo |
| `0x27` | CAN_TX_STOP | SDCTP / Massa CAN TX | Congelado | Parada de TX periodico |
| `0x43` | CAN_READ_ALL | Legado / Deprecated | Removido do fluxo principal | Nao deve ser usado por UI/API como contrato valido |
| `0x50` | CAN_TX_DIRECT | SDCTP / Massa CAN TX | Congelado | Envio CAN TX direto |
| `0x51` | CAN_TX_CREATE | SDCTP / Massa CAN TX | Congelado | Criacao de linha TX |
| `0x52` | CAN_TX_EDIT | SDCTP / Massa CAN TX | Congelado | Edicao compactada de linha TX |
| `0x53` | CAN_TX_DELETE | SDCTP / Massa CAN TX | Congelado | Remocao de linha TX |
| `0x7E` | TRANSPORT_DIAG | Diagnostico / Transporte | Congelado | Diagnostico de transporte/dispatcher |
| `0x7F` | FUNCTIONAL_ERROR | Diagnostico / Transporte | Congelado | Erro funcional retornado pela UCE |
| `0xFE` | GATEWAY_ERROR | Diagnostico / Transporte | Congelado | Erro gerado pelo gateway BPM |

## 6. Decisões congeladas

- Nome oficial: SDCTP.
- SDH e controle/operacao.
- SDCTP e massa/sincronizacao CAN.
- RX CAN pertence ao SDCTP.
- TX CAN pertence ao SDCTP.
- SDGW e transporte.
- UI nao consome TLV bruto.
- CanRxOutputBuffer e a saida oficial de massa CAN para aplicacao/UI.
- CanService API possui lado RX e lado TX.
- J1939 deve consumir CanFrameDto, nao TLV bruto.
- SDGW nao deve receber regra de protocolo automotivo.
- CAN_READ_ALL e legado e nao deve ser usado no fluxo principal.

## 7. Decisões pendentes

- Se UceClient deve apenas rotear payload bruto SDCTP ou continuar parseando eventos.
- Se UceParsers deve manter parsers CAN ou mover tudo para namespace SDCTP.
- Separacao futura entre CanControlService e SdctpCanDataService no firmware UCE.
- Camada futura para consumidores de protocolo automotivo, como J1939, K-LINE e J1949.

## 8. ETAPAS futuras sugeridas

ETAPA 02 - Separar fachada de controle CAN da fachada SDCTP na API.

ETAPA 03 - Reduzir conhecimento SDCTP dentro de UceClient/UceParsers.

ETAPA 04 - Consolidar SDCTP RX/TX e remover CAN_READ_ALL legado.

ETAPA 05 - Reduzir conhecimento SDCTP dentro de UceClient/UceParsers remanescente.

ETAPA 06 - Revisar mecanismo futuro de snapshot SDCTP sem CAN_READ_ALL.

ETAPA 07 - Remover dependencia da UI em GwProtocol onde for apenas apresentacao.

ETAPA 08 - Preparar camada de consumidores de protocolos automotivos.

ETAPA 09 - Avaliar separacao do CanService firmware em controle CAN e massa SDCTP.

## 9. Validação

Este documento executa somente a ETAPA 01 de congelamento arquitetural.

Validacoes aplicaveis:

- Nao altera codigo funcional.
- Nao renomeia classes.
- Nao move arquivos.
- Nao cria refatoracao.
- Nao altera contratos runtime.
- TX CAN foi congelado como SDCTP na ETAPA 04.
- CAN_READ_ALL foi declarado legado na ETAPA 04.

Ambiguidades registradas:

- Dispatcher UCE API ainda precisa de decisao futura sobre roteamento por payload bruto SDCTP versus parsing local.
- UceParsers ainda precisa de decisao futura sobre permanencia dos parsers CAN ou migracao para namespace SDCTP.
- Firmware UCE ainda precisa de decisao futura sobre separacao entre controle CAN e massa SDCTP.
- O mecanismo futuro de snapshot SDCTP sem `CAN_READ_ALL` ainda precisa ser especificado para recuperacao completa apos perda de mirror table.

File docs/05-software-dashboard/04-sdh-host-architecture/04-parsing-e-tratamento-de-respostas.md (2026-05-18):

⬅ [Retornar para Arquitetura SDH no Host](../04-sdh-host-architecture.md)
⬅ [Retornar para Índice Geral](../../00-INDICE.md)

# Parsing e Tratamento de Respostas

## Função lógica

Esta página cobre a trilha `COMO` do parsing real do host: como texto SDH vira comando validado, como o mapper vira TLV SDGW e como a resposta volta como DTO ou erro tipado.

## Blocos lógicos envolvidos

| classe | função lógica | estado |
| --- | --- | --- |
| `SdhTextParser` | transforma texto em `SdhCommand` | `IMPLEMENTADO` |
| `SdhTextSerializer` | serializa `SdhCommand` em texto ordenado | `IMPLEMENTADO` |
| `SdhTarget` | quebra `target` em `Board`, `Resource`, `Subresource` | `IMPLEMENTADO` |
| `SdhValidator` | valida versão, target, op e argumentos | `IMPLEMENTADO` |
| `SdhToSdgwMapper` | transforma SDH em `cmd + payload + timeout + retries` | `IMPLEMENTADO` |
| `GsaParsers` | interpreta TLVs síncronos, erros e eventos da GSA | `IMPLEMENTADO` |
| `SdhResponse` | contrato pronto para resposta semântica | `PARCIALMENTE IMPLEMENTADO` |

## Trecho comentado: parser textual

Em `SdhTextParser.Parse(...)`:

```csharp
string[] tokens = text.Split(new[] { ' ' }, StringSplitOptions.RemoveEmptyEntries);
if (tokens.Length < 3)
    throw new InvalidOperationException("Comando SDH inválido. Esperado: version target op [chave=valor...]");
```

O que esse trecho faz:

- exige pelo menos `version target op`;
- permite argumentos extras apenas no formato `chave=valor`;
- cria um `SdhCommand` usado depois pela mesma trilha de validação e mapeamento da UI.

## Trecho comentado: validação do catálogo

Em `SdhValidator.Validate(...)`, o host fecha explicitamente o escopo aceito:

```csharp
if (string.Equals(target.Board, GsaBoard, StringComparison.OrdinalIgnoreCase))
{
    ValidateGsaCommand(target, command);
    return;
}

if (string.Equals(target.Board, BpmBoard, StringComparison.OrdinalIgnoreCase) &&
    string.Equals(target.Resource, BpmResource, StringComparison.OrdinalIgnoreCase) &&
    string.IsNullOrWhiteSpace(target.Subresource))
{
    ValidateBpmGateway(command);
    return;
}
```

Por que isso importa:

- impede que a documentação trate targets futuros como presentes;
- concentra em um ponto único as regras de `channel`, `state`, `kind`, `value` e faixa de canais `1..16`.

## Trecho comentado: montagem do TLV

Em `SdhToSdgwMapper.BuildTlvPayload(...)`, a DAL fecha o payload GSA:

```csharp
byte[] payload = new byte[payloadLength + 3];
payload[0] = type;
payload[1] = (byte)payloadLength;
...
payload[payload.Length - 1] = SdgwFrameCodec.Crc8Atm(payload, 0, payload.Length - 1);
```

O que esse trecho faz:

- monta `type + len + data + crc`;
- deixa o payload GSA pronto para ser encapsulado no frame SDGW;
- explica por que `GsaParsers.TryReadTlv(...)` aceita payload com ou sem o CRC final.

## Trecho comentado: tratamento de resposta GSA

Em `GsaClient.ExecuteOperationAsync(...)`, o client tenta três caminhos de interpretação antes do DTO final:

```csharp
if (GsaParsers.TryReadGatewayError(responseFrame, out gatewayError, out gatewayErrorParseMessage))
    return GsaOperationResult<T>.Fail(gatewayError.Message, outcome);

if (GsaParsers.TryReadFunctionalError(responseFrame, out functionalError, out functionalErrorParseMessage))
    return GsaOperationResult<T>.FunctionalFail(functionalError, outcome);

if (!parser(responseFrame, out response, out error))
    return GsaOperationResult<T>.Fail(error, outcome);
```

O que esse trecho faz:

- separa erro de gateway vindo da BPM;
- separa erro funcional devolvido pela própria GSA;
- só no final chama o parser específico do DTO esperado.

## Trecho comentado: leitura do TLV

Em `GsaParsers.TryReadTlv(...)`, o host aplica checagens mínimas antes de aceitar o payload:

```csharp
if (payloadLength != expectedLen + 2 && payloadLength != expectedLen + 3)
{
    error = "Resposta da GSA com tamanho inválido para " + operationName + ".";
    return false;
}
```

Esse detalhe é importante porque o host aceita:

- payload sem CRC final destacado;
- payload com CRC TLV embutido;
- mas continua exigindo `type` e `len` exatos para cada operação.

## O que ainda não virou fluxo quente

- `SdhResponse` existe como tipo de contrato, mas não é a forma usada hoje para devolver resposta ao restante do host.
- `OperationStatusDto` existe como DTO comum, mas a trilha ativa prefere resultados específicos de BPM, GSA e UCE.

## Glossário

- **Parsing**: interpretação estrutural de texto, target ou payload em tipos do host.
- **Erro de gateway**: falha retornada pela BPM ao intermediar uma operação da GSA.
- **Erro funcional**: falha devolvida pela própria GSA para o TLV solicitado.

## Próximas camadas

- Esta é uma página terminal deste ramo da documentação.

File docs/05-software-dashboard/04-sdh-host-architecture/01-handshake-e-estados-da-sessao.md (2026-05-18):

⬅ [Retornar para Arquitetura SDH no Host](../04-sdh-host-architecture.md)
⬅ [Retornar para Índice Geral](../../00-INDICE.md)

# Handshake e Estados da Sessão

## Função lógica

`SdgwHostSession` é a classe que leva o host de `Disconnected` para `Linked`. Ela segura o binário SDGW até terminar o bootstrap textual com a BPM.

## Estados confirmados

| estado na sessão | papel | estado de implementação |
| --- | --- | --- |
| `Disconnected` | sem transporte aberto | `IMPLEMENTADO` |
| `TransportConnected` | transporte abriu, mas ainda sem banner aceito | `IMPLEMENTADO` |
| `Draining` | janela curta para drenar ruído inicial | `IMPLEMENTADO` |
| `BannerSent` | banner textual foi enviado e a sessão aguarda a linha da BPM | `IMPLEMENTADO` |
| `Linked` | sessão SDGW estabelecida | `IMPLEMENTADO` |
| `LinkFailed` | tentativa expirou ou supervisor derrubou o link | `IMPLEMENTADO` |

Na UI BPM, esse estado ainda é projetado como `SerialConnected` ou `BluetoothConnected` por `BpmSerialService.MapState(...)`.

## Parâmetros reais

- `DrainWindow = 300 ms`
- `HandshakeTimeout = 2000 ms`
- `RetryInterval = 3 s`
- `ApiBanner = "\nSIMULDIESELAPI\n"`
- prefixo de identificação esperado pela BPM: `SimulDIESEL ver`

## Trecho comentado: abertura de tentativa

Em `SdgwHostSession.LinkTick(...)`, linhas em torno da abertura da tentativa:

```csharp
if (!_attemptActive)
{
    _rxBuffer.Clear();
    _draining = true;
    _drainUntil = now.Add(DrainWindow);
    _attemptDeadlineUtc = now.Add(HandshakeTimeout);
    _attemptActive = true;
    SetState(SessionState.Draining);
    return;
}
```

O que esse trecho faz:

- inicia uma tentativa formal de subida do link;
- limpa texto residual acumulado no buffer;
- abre uma janela curta de drenagem antes do banner;
- fixa um deadline absoluto para a tentativa atual.

## Trecho comentado: envio do banner

Ainda em `LinkTick(...)`, quando a janela de drain termina:

```csharp
if (_draining && now >= _drainUntil)
{
    _draining = false;
    _transport.Write(Encoding.ASCII.GetBytes(ApiBanner));
    SetState(SessionState.BannerSent);
}
```

Esse é o ponto exato em que o host troca o estado de apenas conectado para tentativa efetiva de sessão.

## Trecho comentado: aceitação da interface

Em `HandleHandshakeBytes(...)`, o host fecha a transição para `Linked`:

```csharp
if (BpmParsers.TryParseInterfaceInfo(line, out deviceInfo))
{
    _sdgwSessionEstablished = true;
    SetState(SessionState.Linked);
    _attemptActive = false;
    StopAndDisposeLinkTimer_NoLock();
    InterfaceName = deviceInfo.Version;
}
```

O que esse trecho faz:

- testa cada linha ASCII recebida contra `BpmParsers.TryParseInterfaceInfo(...)`;
- só considera o handshake concluído quando a linha contém `SimulDIESEL ver`;
- grava o texto inteiro em `InterfaceName`, que depois sobe para a UI.

## Regras de transição observadas

- se o transporte caiu, a sessão volta para `Disconnected`;
- se a tentativa local de handshake expirou, a sessão entra em `LinkFailed` e só tenta de novo após `RetryInterval`;
- se o supervisor derruba a saúde do link já em `Linked`, a sessão entra em `LinkFailed` e rearma a tentativa imediatamente.

## Glossário

- **Bootstrap textual**: etapa inicial em que o host ainda conversa por linhas ASCII.
- **Drain**: janela curta de descarte de ruído antes do banner.
- **Linha de interface**: texto da BPM que identifica a versão e autoriza a entrada em `Linked`.
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

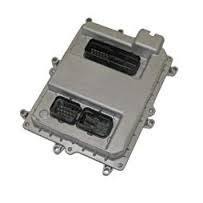
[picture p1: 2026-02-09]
local-api/src/SimulDIESEL/SimulDIESEL/RESOURCES/EDC7.jpg

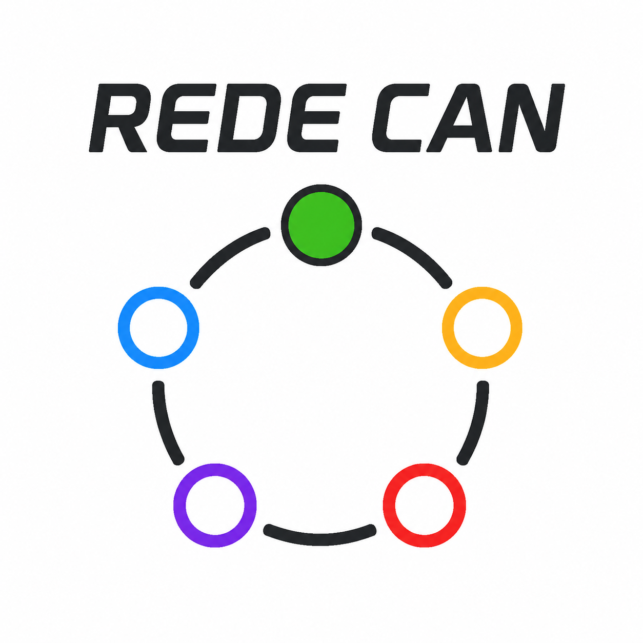
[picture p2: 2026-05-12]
local-api/src/SimulDIESEL/SimulDIESEL/RESOURCES/Rede_can_ico.png

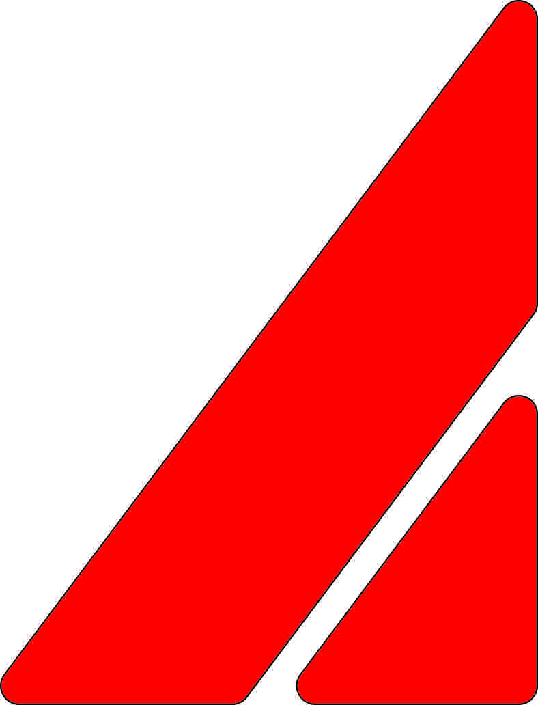
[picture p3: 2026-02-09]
local-api/src/SimulDIESEL/SimulDIESEL/RESOURCES/Simbolo ANDERTECH.jpg

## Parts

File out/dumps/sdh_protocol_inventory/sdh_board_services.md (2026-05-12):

# Mapeamento por board e por servico

## BPM

Endereco: `GwProtocol.BpmAddress = 0x0`

| Servico | Comandos | Codigos | Classes |
|---|---|---|---|
| gateway | `BPM.gateway ping` | compact cmd `0x00`, op `BpmPingOp 0x0` | `BpmClient`, `SdhToSdgwMapper`, `SdhValidator` |
| serial/bluetooth/link | Nao exposto como SDH funcional, mas presente no host | NAO CONFIRMADO NO CODIGO como comando SDH | `BpmSerialService`, `BluetoothTransport`, `SerialTransport`, `SdgwHostSession` |
| backplane/xconn | Servicos BLL existem, comandos SDH nao confirmados | NAO CONFIRMADO NO CODIGO | `BackplaneService`, `XConnService` |

Observacao: BPM e tambem gateway SDGW. No host, `BpmClient.GetStatus()` le estado local de conexao/link/transporte, nao comando SDH.

## GSA

Endereco: `GwProtocol.GsaAddress = 0x1`; operacao compacta `GsaTlvTransactOp = 0x0`; command compact `0x10`.

| Servico | Comandos SDH | TLV type | Request | Response/event |
|---|---|---:|---|---|
| led | `GSA.led set` | `0x12` | `state` | `GsaLedResponse` |
| channel.setpoint | `GSA.channel.setpoint set` | `0x10` | `channel`, `value` | `GsaChannelSetpointResponse` |
| channel.enable | `GSA.channel.enable set` | `0x11` | `channel`, `state` | `GsaChannelEnableResponse` |
| channels.enable | `GSA.channels.enable set` | `0x14` | `state` | `GsaChannelsEnableResponse` |
| channel.status | `GSA.channel.status get` | `0x1B` | `channel` | `GsaChannelStatusResponse` |
| channels.status | `GSA.channels.status get` | `0x13` | vazio | `GsaChannelsStatusResponse` |
| channel.fault | `GSA.channel.fault reset` | `0x15` | `channel` | `GsaChannelFaultResetResponse` |
| channel.offset | `set|get|save|reset` | `0x16..0x19` | `channel`, `kind`, `value` conforme op | offset/save/reset DTOs |
| offset | `GSA.offset reset` | `0x1A` | vazio | `GsaOffsetResetResponse` |
| async fault | nao e comando SDH | `0x30` | Board -> API | `GsaChannelFaultEvent` |
| async physical op | nao e comando SDH | `0x31` | Board -> API | `GsaPhysicalOperationEvent` |
| functional error | resposta de erro | `0x7F` | Board -> API | `GsaFunctionalErrorResponse` |

Servicos internos host:

- `GsaClient`: monta `SdhCommand`, executa transacao e interpreta resposta.
- `GsaDispatcher`: fachada/event bridge.
- `GsaParsers`: interpreta TLV de resposta/evento.
- `FrmGsaLogic`: camada de forms logic para UI.

## UCE

Endereco: `GwProtocol.UceAddress = 0x2`; operacao compacta `UceTlvTransactOp = 0x0`; command compact `0x20`.

| Servico | Comandos SDH | TLV type | Request | Response/event |
|---|---|---:|---|---|
| led | `UCE.led set` | `0x12` | `state` | `UceLedResponse` |
| led event | nao e comando SDH | `0x13` | Board -> API | `UceLedEvent` |
| can.config | `UCE.can.config set` | `0x20` | `controller`, `bitrate`, `mode`, possivel `rxMode` | `UceCanConfigResponse` |
| can.enable | `UCE.can.enable set` | `0x21` | `controller`, `state` | `UceCanEnableResponse` |
| can.status | `UCE.can.status get` | `0x22` | `controller` | `UceCanStatusResponse` |
| can.reset | `UCE.can reset` | `0x23` | `controller` | `UceCanResetResponse` |
| can.rx poll | `UCE.can.rx poll` | `0x24` | `controller` | `UceCanRxPollResponse` |
| can.driverLog | `UCE.can.driverLog poll` | `0x25` | `controller` | `UceCanDriverLogPollResponse` |
| can.tx legado | `UCE.can.tx send` | `0x26` | frame + period | `UceCanTxResponse` |
| can.tx stop | `UCE.can.tx stop` | `0x27` | `controller`, `slot` | `UceCanTxStopResponse` |
| CAN_RX event | nao e comando SDH | `0x28` | Board -> API | `UceCanRxEvent` |
| CAN TX direct | `UCE.can.tx direct` | `0x50` | frame | `UceCanTxResponse` |
| CAN TX create | `UCE.can.tx create` | `0x51` | row completa | `UceCanTxResponse` |
| CAN TX edit | `UCE.can.tx edit` | `0x52` | row parcial por mask | `UceCanTxResponse` |
| CAN TX delete | `UCE.can.tx delete` | `0x53` | `index`, `reason` | `UceCanTxResponse` |
| CAN CRUD create | nao e comando SDH direto | `0x40` | Board -> API | `CanCreateDto` via processors |
| CAN CRUD edit | nao e comando SDH direto | `0x41` | Board -> API | `CanEditDto` |
| CAN CRUD delete | nao e comando SDH direto | `0x42` | Board -> API | `CanDeleteDto` |
| CAN read all | `UCE.can.rx readAll` no client/mapper | `0x43` | sem payload TLV no mapper | `UceCanReadAllResponse`, eventos `0x44/0x45` |
| CAN row | nao e comando SDH | `0x44` | Board -> API | `CanRowDto` |
| CAN read all done | nao e comando SDH | `0x45` | Board -> API | `CanReadAllResponseDto` |
| CAN tic | nao e comando SDH | `0x46` | Board -> API | `CanTicDto` |
| transport diag | nao e comando SDH | `0x7E` | Board -> API | `UceDispatcherOverflowDiagnostic` |
| functional error | resposta de erro | `0x7F` | Board -> API | mensagem funcional |

Servicos internos host:

- `UceClient`: monta comandos SDH e parseia respostas/eventos.
- `UceDispatcher`: fachada/event bridge.
- `UceParsers`: interpreta TLVs de UCE.
- `ApiCanService` e `SdctpApiService`: fronteiras de servico CAN/SDCTP sobre UCE.
- `CanEventProcessor`, `CanRxMirrorManager`, `SdctpEventProcessor`, `SdctpRxMirrorManager`: processam eventos CAN/SDCTP.
- `FrmUceLogic`: camada de forms logic para UI.

## Boards documentais sem suporte SDH host confirmado

| Board | Evidencia | Status |
|---|---|---|
| PSU | docs oficiais de boards/exemplos | NAO CONFIRMADO NO CODIGO host |
| UCO | docs oficiais de boards/exemplos | NAO CONFIRMADO NO CODIGO host |
| URL | docs oficiais de boards/exemplos | NAO CONFIRMADO NO CODIGO host |
| UIOD | docs oficiais de boards/exemplos | NAO CONFIRMADO NO CODIGO host |
| GSC | docs oficiais de boards/exemplos | NAO CONFIRMADO NO CODIGO host |

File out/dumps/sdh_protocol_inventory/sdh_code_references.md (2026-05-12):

# Referencias de codigo SDH

## Contratos e DAL

| Arquivo | Classes/metodos | Conteudo relevante |
|---|---|---|
| `DTL/Protocols/SDGW/SdhCommand.cs` | `SdhCommand` | DTO de comando SDH; `Version`, `Target`, `Op`, `Args`, `Meta`. |
| `DTL/Protocols/SDGW/SdhResponse.cs` | `SdhResponse` | DTO de resposta SDH documental; nao e usado como resposta principal de board. |
| `DTL/Protocols/SDGW/SdhTarget.cs` | `SdhTarget.Parse` | Divide `Board.resource.subresource`. |
| `DTL/Protocols/SDGW/GwProtocol.cs` | constantes | Enderecos, ops, TLV types, payload lengths, status e masks. |
| `DTL/Protocols/SDGW/SdgwCommand.cs` | enum | `Ping 0x55`, `Ack 0xF1`, `Err 0xF2`. |
| `DTL/Protocols/SDGW/SdgwFrame.cs` | `SdgwFrame` | Frame logico sem CRC/COBS. |
| `DAL/Protocols/SDGW/SdhTextParser.cs` | `Parse` | Parser textual `sdh/1 target op chave=valor`. |
| `DAL/Protocols/SDGW/SdhTextSerializer.cs` | `Serialize` | Serializador textual; args ordenados por chave. |
| `DAL/Protocols/SDGW/SdhValidator.cs` | `Validate*` | Catalogo aceito e validacao de argumentos. |
| `DAL/Protocols/SDGW/SdhToSdgwMapper.cs` | `Map*`, `BuildTlvPayload` | Traducao SDH -> SDGW/TLV. |
| `DAL/Protocols/SDGW/SdhClient.cs` | `SendAsync`, `SendTextAsync`, `ToText` | Entrada semantica SDH. |
| `DAL/Protocols/SDGW/SdgwSession.cs` | `SendAsync`, `FrameReceived`, `EventReceived` | Sessao SDGW e eventos por flag. |
| `DAL/Protocols/SDGW/SdGwTxScheduler.cs` | `EnqueueAsync` | Agendamento TX. |
| `DAL/Protocols/SDGW/SdgwLinkEngine.cs` | framing/app frames | Link engine e estados de transporte. |

## BPM

| Arquivo | Classes/metodos | Conteudo relevante |
|---|---|---|
| `BLL/Boards/BPM/BpmClient.cs` | `PingGatewayAsync` | Cria `SdhCommand Target=BPM.gateway Op=ping`. |
| `BLL/Boards/BPM/Comm/Serial/BpmSerialService.cs` | `Shared`, `BoardDispatcher`, `Sdctp` | Monta servicos compartilhados, transporte serial/Bluetooth e dispatchers. |
| `BLL/Boards/BPM/Comm/SdgwHostSession.cs` | sessao host | Conecta engine/sessao SDGW no host. |
| `DTL/Boards/BPM/BpmStatusDto.cs` | `BpmStatusDto` | Status local de link/transporte. |

## GSA

| Arquivo | Classes/metodos | Conteudo relevante |
|---|---|---|
| `BLL/Boards/GSA/GsaClient.cs` | `SetBuiltinLedAsync`, `SetChannelSetpointAsync`, `SetChannelEnableAsync`, `SetChannelsEnableAsync`, `GetChannelStatusAsync`, `GetChannelsStatusAsync`, `ResetChannelFaultAsync`, offsets | Cria comandos SDH GSA e executa transacoes. |
| `BLL/Boards/GSA/GsaParsers.cs` | `TryRead*` | Parse de TLVs GSA, erros e eventos. |
| `BLL/Boards/GSA/GsaDispatcher.cs` | eventos e fachada | Encaminha eventos e metodos publicos. |
| `BLL/FormsLogic/GSA/FrmGsaLogic.cs` | forms logic | Consome dispatcher GSA para UI. |
| `DTL/Boards/GSA/GsaRequests.cs` | request DTOs | Requisicoes tipadas BLL/UI. |
| `DTL/Boards/GSA/GsaResponses.cs` | response DTOs | Respostas tipadas. |
| `DTL/Boards/GSA/GsaCommon.cs` | enums/event DTOs | `GsaOffsetKind`, erros, eventos. |

## UCE

| Arquivo | Classes/metodos | Conteudo relevante |
|---|---|---|
| `BLL/Boards/UCE/UceClient.cs` | LED, CAN config/enable/status/reset/rx/driverLog/tx | Cria comandos SDH UCE e executa transacoes. |
| `BLL/Boards/UCE/UceParsers.cs` | `TryRead*` | Parse de TLVs UCE, erros e eventos. |
| `BLL/Boards/UCE/UceDispatcher.cs` | eventos e fachada | Encaminha eventos e metodos publicos. |
| `BLL/Boards/UCE/UceGatewayDiagnosticLog.cs` | diagnosticos | Log de erros gateway/CAN/transport. |
| `BLL/FormsLogic/UCE/FrmUceLogic.cs` | forms logic | Usa `UceDispatcher`/`SdctpApiService`; CAN/J1939 acima da UCE. |
| `DTL/Boards/UCE/UceCanProtocol.cs` | enums/conversoes | Controller, mode, bitrate, status. |
| `DTL/Boards/UCE/UceCanResponses.cs` | response/event DTOs | CAN/LED responses e eventos. |
| `DTL/Boards/UCE/Can/*.cs` | CAN DTOs | `CanCreateDto`, `CanEditDto`, `CanDeleteDto`, `CanRowDto`, `CanFrameDto`, `CanReadAllResponseDto`, `CanTicDto`, `CanTxRowDto`. |

## CAN/SDCTP sobre UCE

| Arquivo | Conteudo relevante |
|---|---|
| `BLL/Services/CAN/ApiCanService.cs` | Servico CAN legado/alto nivel; solicita readAll, processa eventos UCE. |
| `BLL/Services/CAN/CanEventProcessor.cs` | Decodifica CAN_CREATE/EDIT/DELETE/ROW/READ_ALL_DONE/TIC. |
| `BLL/Services/CAN/CanRxMirrorManager.cs` | Tabela espelho CAN RX. |
| `BLL/Services/CAN/CanRxOutputBuffer.cs` | Buffer de frames RX para consumidores. |
| `BLL/Services/CAN/CanTxManager.cs` | Gerencia TX CAN. |
| `BLL/Services/CAN/SDCTP/SdctpApiService.cs` | Fronteira atual recomendada para CAN/SDCTP. |
| `BLL/Services/CAN/SDCTP/SdctpProtocol.cs` | Alias dos TLVs UCE CAN/SDCTP. |
| `BLL/Services/CAN/SDCTP/SdctpEventProcessor.cs` | Facade para eventos SDCTP. |
| `BLL/Services/CAN/SDCTP/SdctpRxMirrorManager.cs` | Mirror SDCTP. |
| `BLL/Services/CAN/SDCTP/SdctpRxOutputBuffer.cs` | Output buffer SDCTP. |

## Firmware e documentacao correlata

| Caminho | Conteudo |
|---|---|
| `hardware/firmware/UCE - Unidade de comunicacao externa/include/defs.h` | Defines UCE/TLV como `CMD_CAN_READ_ALL 0x43`, `CMD_CAN_CREATE 0x40`, etc. |
| `hardware/firmware/UCE - Unidade de comunicacao externa/lib/core/services/UceServiceDispatcher.cpp` | Despacho interno UCE. |
| `hardware/firmware/UCE - Unidade de comunicacao externa/lib/services/can/service/CanService.cpp` | CAN_READ_ALL, publish RX events, CAN_READ_ALL_DONE. |
| `hardware/firmware/BPM - BACKPLANE MANAGER MODULE/lib/*` | SDGW transport/router/link no firmware BPM. |
| `docs/official/06-protocolos/01-sdh-command-model.md` | Modelo documental SDH. |
| `docs/official/06-protocolos/02-sdh-response-model.md` | Modelo documental de resposta/JSON. |
| `docs/official/06-protocolos/06-gsa-sdh-tlv.md` | Contrato GSA SDH/TLV. |
| `docs/official/06-protocolos/07-uce-sdh-tlv.md` | Contrato UCE SDH/TLV. |

## Exemplos encontrados

Confirmados em codigo:

```text
sdh/1 BPM.gateway ping
sdh/1 GSA.led set state=on
sdh/1 GSA.channel.setpoint set channel=6 value=128
sdh/1 UCE.can.config set controller=can0 bitrate=250 mode=normal
sdh/1 UCE.can.tx direct controller=can0 extended=1 rtr=0 id=419364352 dlc=8 d0=0 ...
```

Somente documentais / NAO CONFIRMADO NO CODIGO host:

```text
sdh/1 PSU.power.main set state=on
sdh/1 UCO.can1 cfg bitrate=250000 mode=normal
sdh/1 URL.relay3 status
sdh/1 UIOD.di1 read
sdh/1 GSC.signal1 cfg mode=pulse freq=1000 duty=50
```

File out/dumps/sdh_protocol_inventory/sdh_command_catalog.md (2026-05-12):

# Catalogo de comandos SDH encontrados

Formato base: `sdh/1 <target> <op> chave=valor ...`  
CommandCode abaixo e o comando compacto SDGW quando aplicavel: `GwProtocol.MakeCompactCommand(address, op)`. Para GSA/UCE, o `TLVMapping` identifica o type interno transportado no payload.

## BPM

### BPM.gateway ping

- CommandName: `BPM.gateway ping`
- CommandCode: `0x00` (`BpmAddress 0x0`, `BpmPingOp 0x0`)
- Board: BPM
- Service: gateway
- Direction: API -> Board
- RequestPayload: vazio
- ResponsePayload: ACK SDGW; DTO final `BpmCommandResult`
- JsonContract: NAO CONFIRMADO NO CODIGO
- TLVMapping: nenhum TLV; payload `Array.Empty<byte>()`
- SourceFiles: `BLL/Boards/BPM/BpmClient.cs`, `DAL/Protocols/SDGW/SdhValidator.cs`, `DAL/Protocols/SDGW/SdhToSdgwMapper.cs`
- UsedBy: `BpmClient.PingGatewayAsync()`
- Notes: timeout 150 ms, 1 retry no mapper.
- DatabaseRelevance: baixo para perfil de modulo; alto para diagnostico de conectividade da bancada.

## GSA

### GSA.led set

- CommandName: `GSA.led set`
- CommandCode: `0x10`
- Board: GSA
- Service: led
- Direction: API -> Board
- RequestPayload: `state=on|off`
- ResponsePayload: `GsaLedResponse.AcceptedState`
- JsonContract: NAO CONFIRMADO NO CODIGO
- TLVMapping: `GsaSetLedType 0x12`, payload `[state: 0|1]`
- SourceFiles: `GsaClient.cs`, `GsaParsers.cs`, `SdhValidator.cs`, `SdhToSdgwMapper.cs`, `GwProtocol.cs`
- UsedBy: `GsaClient.SetBuiltinLedAsync()`, `FrmGsaLogic`
- Notes: comando operacional simples.
- DatabaseRelevance: baixo; util para teste de presenca/atuacao basica.

### GSA.channel.setpoint set

- CommandName: `GSA.channel.setpoint set`
- CommandCode: `0x10`
- Board: GSA
- Service: channel.setpoint
- Direction: API -> Board
- RequestPayload: `channel=1..16`, `value=0..255`
- ResponsePayload: `GsaChannelSetpointResponse.Channel`, `AcceptedValue`
- JsonContract: NAO CONFIRMADO NO CODIGO
- TLVMapping: `GsaChannelSetpointType 0x10`, payload `[channel, value]`
- SourceFiles: `GsaClient.cs`, `GsaParsers.cs`, `SdhValidator.cs`, `SdhToSdgwMapper.cs`
- UsedBy: `GsaClient.SetChannelSetpointAsync()`, `FrmGsaLogic`
- Notes: controla setpoint analogico por canal.
- DatabaseRelevance: alto para sinais eletricos e perfis de modulo.

### GSA.channel.enable set

- CommandName: `GSA.channel.enable set`
- CommandCode: `0x10`
- Board: GSA
- Service: channel.enable
- Direction: API -> Board
- RequestPayload: `channel=1..16`, `state=on|off`
- ResponsePayload: `GsaChannelEnableResponse.Channel`, `AcceptedState`
- JsonContract: NAO CONFIRMADO NO CODIGO
- TLVMapping: `GsaChannelEnableType 0x11`, payload `[channel, state]`
- SourceFiles: `GsaClient.cs`, `GsaParsers.cs`, `SdhValidator.cs`, `SdhToSdgwMapper.cs`
- UsedBy: `GsaClient.SetChannelEnableAsync()`
- Notes: habilita/desabilita canal individual.
- DatabaseRelevance: alto para configuracao de hardware/sinais.

### GSA.channels.enable set

- CommandName: `GSA.channels.enable set`
- CommandCode: `0x10`
- Board: GSA
- Service: channels.enable
- Direction: API -> Board
- RequestPayload: `state=on|off`
- ResponsePayload: `GsaChannelsEnableResponse.RequestedState`, `AffectedCount`
- JsonContract: NAO CONFIRMADO NO CODIGO
- TLVMapping: `GsaChannelsEnableType 0x14`, payload `[state]`
- SourceFiles: `GsaClient.cs`, `GsaParsers.cs`, `SdhValidator.cs`, `SdhToSdgwMapper.cs`
- UsedBy: `GsaClient.SetChannelsEnableAsync()`
- Notes: enable global.
- DatabaseRelevance: medio/alto para aplicar perfil de bancada.

### GSA.channel.status get

- CommandName: `GSA.channel.status get`
- CommandCode: `0x10`
- Board: GSA
- Service: channel.status
- Direction: API -> Board
- RequestPayload: `channel=1..16`
- ResponsePayload: `GsaChannelStatusResponse`: `Channel`, `Setpoint`, `VoltageRead`, `CurrentRead`, `Enabled`, `Fault`
- JsonContract: NAO CONFIRMADO NO CODIGO
- TLVMapping: `GsaChannelStatusType 0x1B`, payload request `[channel]`, response len `0x06`
- SourceFiles: `GsaClient.cs`, `GsaParsers.cs`, `SdhValidator.cs`, `SdhToSdgwMapper.cs`
- UsedBy: `GsaClient.GetChannelStatusAsync()`
- Notes: leitura por canal.
- DatabaseRelevance: alto para captura de estado, validacao e testes.

### GSA.channels.status get

- CommandName: `GSA.channels.status get`
- CommandCode: `0x10`
- Board: GSA
- Service: channels.status
- Direction: API -> Board
- RequestPayload: vazio
- ResponsePayload: `GsaChannelsStatusResponse.Channels`, 16 registros de 6 bytes no parser atual
- JsonContract: NAO CONFIRMADO NO CODIGO
- TLVMapping: `GsaChannelsStatusType 0x13`, request vazio, response len `0x60`
- SourceFiles: `GsaClient.cs`, `GsaParsers.cs`, `SdhValidator.cs`, `SdhToSdgwMapper.cs`
- UsedBy: `GsaClient.GetChannelsStatusAsync()`
- Notes: snapshot global GSA.
- DatabaseRelevance: alto para captura temporal e perfil de modulo.

### GSA.channel.fault reset

- CommandName: `GSA.channel.fault reset`
- CommandCode: `0x10`
- Board: GSA
- Service: channel.fault
- Direction: API -> Board
- RequestPayload: `channel=1..16`
- ResponsePayload: `GsaChannelFaultResetResponse.Channel`, `FaultState`
- JsonContract: NAO CONFIRMADO NO CODIGO
- TLVMapping: `GsaChannelFaultResetType 0x15`, payload `[channel]`
- SourceFiles: `GsaClient.cs`, `GsaParsers.cs`, `SdhValidator.cs`, `SdhToSdgwMapper.cs`
- UsedBy: `GsaClient.ResetChannelFaultAsync()`
- Notes: limpa latch de fault por canal.
- DatabaseRelevance: medio para rotinas de teste/manutencao.

### GSA.channel.offset set/get/save/reset

- CommandName: `GSA.channel.offset set|get|save|reset`
- CommandCode: `0x10`
- Board: GSA
- Service: channel.offset
- Direction: API -> Board
- RequestPayload: `channel=1..16`; `kind=vout|vread|iread` para set/get; `value=int16` para set
- ResponsePayload: set/get `GsaChannelOffsetResponse`; save/reset retornam o `Channel`
- JsonContract: NAO CONFIRMADO NO CODIGO
- TLVMapping: `0x16 set`, `0x17 get`, `0x18 save`, `0x19 reset`; kind `vout=0x01`, `vread=0x02`, `iread=0x03`
- SourceFiles: `GsaClient.cs`, `GsaParsers.cs`, `SdhValidator.cs`, `SdhToSdgwMapper.cs`, `GsaCommon.cs`
- UsedBy: `GsaClient.Set/Get/Save/ResetChannelOffsetAsync()`
- Notes: offset little-endian via `BitConverter.GetBytes(short)`.
- DatabaseRelevance: alto para calibracao, configuracao eletrica e perfis salvos.

### GSA.offset reset

- CommandName: `GSA.offset reset`
- CommandCode: `0x10`
- Board: GSA
- Service: offset
- Direction: API -> Board
- RequestPayload: vazio
- ResponsePayload: `GsaOffsetResetResponse.AffectedChannels`
- JsonContract: NAO CONFIRMADO NO CODIGO
- TLVMapping: `GsaOffsetResetType 0x1A`
- SourceFiles: `GsaClient.cs`, `GsaParsers.cs`, `SdhValidator.cs`, `SdhToSdgwMapper.cs`
- UsedBy: `GsaClient.ResetOffsetsAsync()`
- Notes: reset global.
- DatabaseRelevance: medio para restauracao/limpeza de perfil.

## UCE

### UCE.led set

- CommandName: `UCE.led set`
- CommandCode: `0x20`
- Board: UCE
- Service: led
- Direction: API -> Board
- RequestPayload: `state=on|off`
- ResponsePayload: `UceLedResponse.AcceptedState`
- JsonContract: NAO CONFIRMADO NO CODIGO
- TLVMapping: `UceSetLedType 0x12`, payload `[state]`
- SourceFiles: `UceClient.cs`, `UceParsers.cs`, `SdhValidator.cs`, `SdhToSdgwMapper.cs`
- UsedBy: `UceClient.SetBuiltinLedAsync()`, `FrmUceLogic`
- Notes: equivalente ao LED GSA para UCE.
- DatabaseRelevance: baixo; diagnostico de board.

### UCE.can.config set

- CommandName: `UCE.can.config set`
- CommandCode: `0x20`
- Board: UCE
- Service: can.config
- Direction: API -> Board
- RequestPayload: `controller=can0|can1`, `bitrate=5|10|25|50|125|250|500|800|1000`, `mode=normal|listen|loopback`; `rxMode=auto|directOnly` aparece no mapper/client, mas NAO e aceito pelo validator atual
- ResponsePayload: `UceCanConfigResponse.Controller`, `AcceptedBitrateKbps`, `AcceptedMode`
- JsonContract: NAO CONFIRMADO NO CODIGO
- TLVMapping: `UceCanConfigType 0x20`, payload `[controller, bitrateCode, mode]` ou `[controller, bitrateCode, mode, rxMode]`
- SourceFiles: `UceClient.cs`, `UceParsers.cs`, `UceCanProtocol.cs`, `SdhValidator.cs`, `SdhToSdgwMapper.cs`
- UsedBy: `UceClient.SetCanConfigAsync()`, `SdctpApiService`, `FrmUceLogic`
- Notes: divergencia validator vs mapper para `rxMode`.
- DatabaseRelevance: alto para CAN/J1939 e configuracao de hardware.

### UCE.can.enable set

- CommandName: `UCE.can.enable set`
- CommandCode: `0x20`
- Board: UCE
- Service: can.enable
- Direction: API -> Board
- RequestPayload: `controller=can0|can1`, `state=on|off`
- ResponsePayload: `UceCanEnableResponse.Controller`, `EffectiveEnabled`
- JsonContract: NAO CONFIRMADO NO CODIGO
- TLVMapping: `UceCanEnableType 0x21`, payload `[controller, state]`
- SourceFiles: `UceClient.cs`, `UceParsers.cs`, `SdhValidator.cs`, `SdhToSdgwMapper.cs`
- UsedBy: `UceClient.SetCanEnabledAsync()`, `SdctpApiService`, `FrmUceLogic`
- Notes: abre/fecha porta CAN via UCE.
- DatabaseRelevance: alto para execucao de testes e perfis CAN.

### UCE.can.status get

- CommandName: `UCE.can.status get`
- CommandCode: `0x20`
- Board: UCE
- Service: can.status
- Direction: API -> Board
- RequestPayload: `controller=can0|can1`
- ResponsePayload: `UceCanStatusResponse.Controller`, `State`, `BitrateKbps`, `Mode`
- JsonContract: NAO CONFIRMADO NO CODIGO
- TLVMapping: `UceCanStatusType 0x22`, request `[controller]`, response len `0x04`
- SourceFiles: `UceClient.cs`, `UceParsers.cs`, `SdhValidator.cs`, `SdhToSdgwMapper.cs`
- UsedBy: `UceClient.GetCanStatusAsync()`, `FrmUceLogic`
- Notes: status operacional CAN.
- DatabaseRelevance: alto para validacao e auditoria de execucao.

### UCE.can reset

- CommandName: `UCE.can reset`
- CommandCode: `0x20`
- Board: UCE
- Service: can
- Direction: API -> Board
- RequestPayload: `controller=can0|can1`
- ResponsePayload: `UceCanResetResponse.Controller`, `ResetSucceeded`
- JsonContract: NAO CONFIRMADO NO CODIGO
- TLVMapping: `UceCanResetType 0x23`, payload `[controller]`
- SourceFiles: `UceClient.cs`, `UceParsers.cs`, `SdhValidator.cs`, `SdhToSdgwMapper.cs`
- UsedBy: `UceClient.ResetCanAsync()`
- Notes: reset da interface CAN.
- DatabaseRelevance: medio para procedimentos de teste.

### UCE.can.rx poll

- CommandName: `UCE.can.rx poll`
- CommandCode: `0x20`
- Board: UCE
- Service: can.rx
- Direction: API -> Board
- RequestPayload: `controller=can0|can1`
- ResponsePayload: `UceCanRxPollResponse.Controller`, lista `UceCanFrame`
- JsonContract: NAO CONFIRMADO NO CODIGO
- TLVMapping: `UceCanRxPollType 0x24`, payload `[controller]`; frame `[id32, flags, dlc, data8]`
- SourceFiles: `UceClient.cs`, `UceParsers.cs`, `SdhValidator.cs`, `SdhToSdgwMapper.cs`
- UsedBy: `UceClient.PollCanRxAsync()`
- Notes: parser aceita ate `UceCanRxMaxFramesPerResponse = 3`.
- DatabaseRelevance: alto para captura temporal e monitor CAN/J1939.

### UCE.can.rx readAll

- CommandName: `UCE.can.rx readAll`
- CommandCode: `0x20`
- Board: UCE
- Service: can.rx
- Direction: API -> Board
- RequestPayload: `controller=can0|can1` no `UceClient`; mapper envia TLV sem payload
- ResponsePayload: ACK/`UceCanReadAllResponse.Accepted`, eventos posteriores `CAN_ROW`/`CAN_READ_ALL_DONE`
- JsonContract: NAO CONFIRMADO NO CODIGO
- TLVMapping: `UceCanReadAllType 0x43`
- SourceFiles: `UceClient.cs`, `UceParsers.cs`, `SdhToSdgwMapper.cs`, `SdhValidator.cs`
- UsedBy: `UceClient.RequestCanReadAllAsync()`, `ApiCanService`/`SdctpApiService`
- Notes: NAO CONFIRMADO COMO ACEITO PELO VALIDATOR atual; `SdhValidator` aceita apenas `poll` para `UCE.can.rx`.
- DatabaseRelevance: alto para snapshot de tabela CAN e recuperacao de mirror.

### UCE.can.driverLog poll

- CommandName: `UCE.can.driverLog poll`
- CommandCode: `0x20`
- Board: UCE
- Service: can.driverLog
- Direction: API -> Board
- RequestPayload: `controller=can0|can1`
- ResponsePayload: `UceCanDriverLogPollResponse.Controller`, lista `UceCanDriverLogEntry`
- JsonContract: NAO CONFIRMADO NO CODIGO
- TLVMapping: `UceCanDriverLogPollType 0x25`
- SourceFiles: `UceClient.cs`, `UceParsers.cs`, `SdhValidator.cs`, `SdhToSdgwMapper.cs`
- UsedBy: `FrmUceLogic.PollCanDriverLogAsync()`
- Notes: diagnostico de driver CAN.
- DatabaseRelevance: medio para auditoria de testes e falhas.

### UCE.can.tx send/direct/create/edit/delete/stop

- CommandName: `UCE.can.tx send|direct|create|edit|delete|stop`
- CommandCode: `0x20`
- Board: UCE
- Service: can.tx
- Direction: API -> Board
- RequestPayload: ver detalhes abaixo
- ResponsePayload: `UceCanTxResponse` para send/direct/create/edit/delete; `UceCanTxStopResponse` para stop
- JsonContract: NAO CONFIRMADO NO CODIGO
- TLVMapping: `0x26 send legado`, `0x50 direct`, `0x51 create`, `0x52 edit`, `0x53 delete`, `0x27 stop`
- SourceFiles: `UceClient.cs`, `UceParsers.cs`, `SdhValidator.cs`, `SdhToSdgwMapper.cs`, `UceCanProtocol.cs`
- UsedBy: `UceClient`, `SdctpApiService`, `FrmUceLogic.SendCanAsync()`
- Notes: `send` legado esta marcado `[Obsolete]`; preferencia atual para `direct` e tabela TX SDCTP.
- DatabaseRelevance: muito alto para simulacao/reproducao de perfis CAN/J1939.

Detalhes de payload:

| Op | Args obrigatorios |
|---|---|
| `send` | `controller`, `extended`, `id`, `dlc`, `period`, `d0..d7` |
| `direct` | `controller`, `extended`, `rtr`, `id`, `dlc`, `d0..d7` |
| `create` | `controller`, `index`, `extended`, `rtr`, `id`, `dlc`, `d0..d7`, `period`, `enabled` |
| `edit` | `controller`, `index`, `mask`, e campos condicionais por mask: `flags`, `id`, `dlc`, `dataMask`, `d0..d7`, `period`, `enabled` |
| `delete` | `controller`, `index`, `reason=1..4` |
| `stop` | `controller`, `slot=0|255` |

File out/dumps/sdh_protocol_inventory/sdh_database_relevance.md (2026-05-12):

# Relevancia do SDH para o futuro Banco de Dados de Modulos

## Premissa

Este dump nao implementa banco de dados. A analise abaixo identifica quais partes do SDH atual podem virar entidades, tabelas ou contratos de execucao para um Banco de Dados de Modulos.

## Entidades candidatas

| Entidade futura | Origem SDH/codigo | Campos candidatos |
|---|---|---|
| BoardType | `SdhTarget.Board`, `GwProtocol.*Address` | nome, endereco SDGW, firmware esperado, capacidades |
| BoardService | targets como `GSA.channel.setpoint`, `UCE.can.config` | board, resource, subresource, op, tlvType |
| CommandDefinition | `SdhValidator`, `SdhToSdgwMapper` | target, op, args obrigatorios, ranges, enum values, databaseRelevance |
| CommandArgument | `Require*Arg`, DTOs request | nome, tipo, obrigatorio, range, enum, default |
| TlvContract | `GwProtocol`, parsers | type, length, payload schema, direction |
| ResponseContract | DTOs response/event | dto, propriedades, tipos, mapping TLV |
| ModuleProfile | comandos SDH parametrizados | sequencia, args, versionamento, board dependencies |
| TestStep | comandos + assertions | comando, timeout, retries, expected response/event |
| CaptureChannel | CAN/GSA status events | fonte, periodicidade, tipo de dado |
| DiagnosticEvent | eventos/erros | board, type, payload, severidade |

## Relevancia por dominio

### Configurar hardware

Comandos relevantes:

- `GSA.channel.enable set`
- `GSA.channels.enable set`
- `GSA.channel.setpoint set`
- `GSA.channel.offset set/save/reset`
- `UCE.can.config set`
- `UCE.can.enable set`
- `UCE.can reset`

Observacao: outros boards de hardware aparecem em docs, mas nao estao confirmados em `SdhValidator`.

### Configurar sinais eletricos

Comandos mais relevantes:

- `GSA.channel.setpoint set`: valor 0..255 por canal.
- `GSA.channel.enable set`: liga/desliga canal.
- `GSA.channel.offset set/get/save/reset`: calibracao `vout`, `vread`, `iread`.
- `GSA.channels.status get`: snapshot de todos os canais.

Campos que merecem modelagem:

- canal 1..16;
- setpoint;
- offset por kind;
- enabled/fault;
- leituras `VoltageRead` e `CurrentRead`.

### Configurar alimentacao

No host atual nao ha comando SDH implementado para PSU/alimentacao. Exemplos `PSU.power.main` aparecem em docs, mas sao **NAO CONFIRMADO NO CODIGO**. Para banco futuro, tratar como capacidade planejada, nao como contrato executavel.

### Configurar CAN/J1939

Comandos relevantes:

- `UCE.can.config set`
- `UCE.can.enable set`
- `UCE.can.status get`
- `UCE.can.rx poll`
- `UCE.can.rx readAll` com ressalva de validator
- `UCE.can.tx direct/create/edit/delete/stop`

Eventos relevantes:

- `UceCanRxEvent 0x28`
- `CAN_CREATE 0x40`
- `CAN_EDIT 0x41`
- `CAN_DELETE 0x42`
- `CAN_ROW 0x44`
- `CAN_READ_ALL_DONE 0x45`
- `CAN_TIC 0x46`

J1939 atual e derivado de frames CAN no host, nao de comando SDH proprio. Para banco, armazenar perfis J1939 como especializacao de mensagens CAN/PGN, nao como protocolo SDH independente ate surgir contrato dedicado.

### Configurar sensores simulados

Confirmado no codigo via GSA:

- setpoints e enables de canais analogicos;
- offsets de calibracao;
- status/leitura por canal.

Nao confirmado no codigo:

- outros tipos de sensores via GSC/UIOD/UCO/PSU.

### Ler atuadores

Confirmado parcialmente:

- GSA status por canal/global.
- CAN RX/TX status via UCE.

Atuadores de outras boards: NAO CONFIRMADO NO CODIGO.

### Medir corrente

Confirmado em GSA:

- `GsaChannelStatusResponse.CurrentRead`
- `GsaChannelsStatusResponse.Channels[].CurrentRead`
- offset kind `iread`.

Unidades/escala fisica final: NAO CONFIRMADO NO CODIGO deste inventario; verificar `GsaChannelScaling.cs` antes de modelar unidade final.

### Executar testes automatizados

O SDH e adequado como contrato de test step:

- `SdhCommand` pode ser o comando executavel.
- `MappedSdgwCommand.TimeoutMs` e `Retries` dao parametros tecnicos iniciais.
- Responses/events sao DTOs para assertions.

Recomendacao de modelagem:

- `test_steps.command_target`
- `test_steps.command_op`
- `test_steps.args_json`
- `test_steps.expected_response_type`
- `test_steps.expected_event_type`
- `test_steps.timeout_ms`
- `test_steps.retry_count`

### Capturar dados temporais

Fontes confirmadas:

- `GSA.channel.status get` / `GSA.channels.status get`
- `GsaChannelFaultEvent`
- `GsaPhysicalOperationEvent`
- `UceCanRxEvent`
- CAN mirror events `CREATE/EDIT/DELETE/ROW/TIC`
- driver logs `UCE.can.driverLog poll`

Modelar timestamps no host, pois varios DTOs atuais nao carregam timestamp absoluto no payload.

### Salvar perfil de modulo

Campos SDH uteis:

- lista de comandos de preparacao GSA;
- configuracao CAN UCE;
- linhas CAN TX (`CanTxRowDto`);
- offsets GSA;
- criterios de leitura/status.

Guardar tambem:

- versao do contrato SDH (`sdh/1`);
- commit/versao do software;
- firmware esperado;
- board address / target.

### Reproduzir perfil de modulo

Sequencia sugerida baseada no contrato atual:

1. `BPM.gateway ping`
2. Configurar GSA offsets/setpoints/enables.
3. Configurar UCE CAN (`config`, `enable`).
4. Criar linhas CAN TX com `UCE.can.tx create` ou enviar frames com `direct`.
5. Capturar `UCE.can.rx`/eventos e status GSA.
6. Aplicar assertions.
7. Limpar/parar TX com `UCE.can.tx stop/delete` e desabilitar recursos conforme perfil.

## Riscos e lacunas para banco

| Lacuna | Evidencia | Impacto |
|---|---|---|
| JSON SDH nao implementado | Apenas docs; sem parser JSON SDH no host | Banco pode armazenar JSON, mas precisa adaptador. |
| `SdhValidator` diverge do mapper/client em `rxMode` e `readAll` | Codigo real | Algumas capacidades existentes em BLL podem falhar via SDH ate corrigir contrato. |
| Unidades fisicas GSA nao consolidadas neste dump | DTOs usam bytes; escala em outro servico | Banco deve guardar unidade/escala explicitamente. |
| Boards futuras sem validator | PSU/UCO/URL/UIOD/GSC em docs | Nao executar via SDH ate implementar host/firmware. |
| Timestamps ausentes em varios DTOs | DTOs atuais | Banco de captura deve adicionar timestamp no host. |

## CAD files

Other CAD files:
hardware/boards/mechanical/gsa-board-outline.FCStd
hardware/boards/mechanical/gsa-board-outline.dxf

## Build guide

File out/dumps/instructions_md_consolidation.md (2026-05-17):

# Dump - Consolidacao definitiva do bootstrap CODEX usando .agents/README.md

Data: 2026-05-12

## Tema e objetivo

ETAPA documental para eliminar a ambiguidade entre o arquivo sem extensao no diretorio `.agents` e `.agents/README.md`.

Objetivo: consolidar o bootstrap CODEX oficial usando somente `.agents/README.md`.

## Escopo executado

- Documentacao de bootstrap CODEX.
- `.agents/README.md`.
- `.agents/README.md`.
- `.agents/`.
- Dumps com registro historico da duplicidade.

## Fora de escopo preservado

- Codigo funcional.
- Firmware.
- Banco.
- UI.
- Contratos SDH, SDGW e SDCTP.
- Scripts automatizados.
- Branch, commit e tag.

## Arquivos alterados

- `.agents/README.md`
- `.agents/README.md`
- `.agents/README.md`
- `out/dumps/codex_agents_skills_bootstrap.md`

## Arquivos removidos

- Arquivo sem extensao no diretorio `.agents`.

## Arquivos criados

- `out/dumps/instructions_md_consolidation.md`

## Referencias corrigidas

- `.agents/README.md`: passou a declarar o fluxo oficial CODEX:
  1. `.agents/README.md`
  2. `.agents/README.md`
  3. `.agents/skills/`
  4. `.agents/`
- `.agents/README.md`: passou a se declarar como arquivo oficial de bootstrap CODEX e a listar a ordem oficial.
- `.agents/README.md`: passou a incluir `.agents/README.md` no fluxo de leitura.
- `out/dumps/codex_agents_skills_bootstrap.md`: o registro historico da duplicidade foi marcado como supersedido, sem manter instrucao ativa de uso do arquivo sem extensao.

## Confirmacao da remocao

- O arquivo sem extensao no diretorio `.agents` foi removido.
- `.agents/README.md` foi preservado como bootstrap oficial.

## Referencias restantes

- Referencias validas a `.agents/README.md` permanecem em documentacao ativa.
- Nenhuma referencia ativa ao arquivo sem extensao deve permanecer.
- O termo `instructions` ainda pode aparecer como palavra generica ou como parte de `.agents/README.md`.

## Riscos encontrados

- Nao foram encontrados scripts automatizados ou integracoes reais apontando para o arquivo sem extensao no diretorio `.agents`.
- O dump `out/dumps/codex_agents_skills_bootstrap.md` continha registro historico da duplicidade; foi atualizado para indicar que essa decisao foi supersedida.

## Validacao

- Busca textual inicial identificou a duplicidade fisica no diretorio `.agents`.
- Busca textual inicial identificou referencias historicas de duplicidade em `out/dumps/codex_agents_skills_bootstrap.md`.
- Confirmado que o arquivo sem extensao no diretorio `.agents` nao existe: `Test-Path` retornou `False`.
- Confirmado que `.agents/README.md` continua integro e legivel.
- Busca textual final para o caminho sem extensao nao encontrou ocorrencias.
- `git status --short` executado ao final da ETAPA; mostrou a remocao do arquivo sem extensao no diretorio `.agents`, quatro arquivos documentais modificados e este dump novo ainda nao rastreado.

## Confirmacao funcional

- Nao houve alteracao funcional.
- Build C# nao executado: nao aplicavel a ETAPA exclusivamente documental.
- PlatformIO nao executado: nao aplicavel, pois firmware ficou fora de escopo.
- Validadores de banco nao executados: nao aplicavel, pois banco ficou fora de escopo.

## Rollback

- Rollback preservado por alteracoes documentais pequenas e rastreaveis.
- Nenhum commit, branch ou tag foi criado.

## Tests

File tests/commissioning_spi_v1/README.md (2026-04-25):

# [COMMISSIONING_SPI_V1] Comissionamento SPI V1

Testes obrigatorios cobertos por `test_spi_v1_protocol.py` e `test_spi_v1_protocol.mjs`:

- baseline logico de frame fisico COBS + delimitador `0x00`
- frame DATA com multiplas mensagens
- ACK com status `1`, `2` e `3`
- distribuicao de prioridade `6:3:1`
- regra de nao fragmentar e nao pular mensagem quando nao cabe
- pausa/resume por IRQ
- timeout de 500 ms sem progresso
- ciclo de janela com ACK, RETRY e DROP

Baseline fisico antes de bancada:

1. Gravar BPM e UCE com logs habilitados.
2. Validar CS, IRQ, CLK, MOSI e MISO em osciloscopio/analisador logico.
3. Enviar comando LED toggle pela rota UCE.
4. Confirmar no log da BPM os bytes COBS transmitidos e recebidos.
5. Confirmar no `SerialUSB` da UCE a captura do frame, parse DATA e emissao de ACK/DATA.

Aceite fisico minimo:

- CS permanece LOW durante a sessao.
- CLK ocorre apenas com IRQ LOW.
- IRQ HIGH pausa o clock e IRQ LOW retoma.
- A sessao aborta apos 500 ms sem progresso.
- O comando LED alterna e a resposta TLV valida retorna ao host.

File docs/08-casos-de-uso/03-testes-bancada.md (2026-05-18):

⬅ [Retornar para Diagnóstico de Falhas](02-diagnostico.md)
⬅ [Retornar para Índice Geral](../00-INDICE.md)

# Testes de Bancada

## Estado atual

Os testes de bancada sustentados pelo repositório continuam majoritariamente manuais, mas agora devem seguir a arquitetura operacional atual do link host <-> BPM.

O foco é validar:

- conexão serial
- bootstrap textual inicial
- operação binária SDGW
- arbitragem correta de TX no host
- resposta funcional da BPM e da board remota

Nesta fase, é importante separar:

- o que já foi validado fisicamente em bancada
- o que já está implementado no código e comissionado por build, mas ainda depende de ensaio físico formal

## Elementos concretos disponíveis

- abertura de porta serial
- handshake e transição para `Linked`
- supervisão de saúde do link por RX válido
- roteamento da BPM para a GSA
- roteamento da BPM para a UCE por `SPI`
- leitura e escrita do LED embutido da GSA
- leitura e escrita do `LED_BUILTIN` da UCE
- suporte implementado para configuração da porta CAN da UCE pela mesma rota `SPI`

## Roteiro mínimo de bancada

```text
1. Ligar a bancada
2. Abrir a serial no software local
3. Confirmar banner da BPM
4. Verificar se o link entra em Linked
5. Executar um comando funcional real
6. Validar resposta e efeito físico
7. Observar se o link permanece vivo por atividade SDGW válida
```

Ping manual pode ser usado como ferramenta auxiliar de observação, mas não deve mais ser tratado como rotina central da operação normal.

## Papel das próximas camadas

As páginas inferiores deste ramo separam o mesmo cenário de bancada em três lentes complementares:

* **hardware**: integridade física do caminho entre host, gateway e board
* **firmware**: comportamento do parser, do roteamento e do serviço embarcado
* **integração**: travessia ponta a ponta entre UI, host, gateway e device

Essa divisão existe para que o leitor consiga validar a bancada por camada, sem perder o roteiro operacional comum.

## Exemplos ponta a ponta atuais

Caso de teste 1: acionamento do LED da GSA.

1. a UI aciona `SetBuiltinLedAsync`
2. o comando entra em `GsaClient -> SdhClient -> SdgwSession`
3. o `SdGwTxScheduler` envia com prioridade `High`
4. o `SdGwLinkEngine` aguarda `ACK`
5. a BPM roteia a transação para a GSA
6. a GSA grava o estado e responde
7. a BPM devolve a resposta ao host
8. o `GsaClient` valida o payload e confirma o estado aplicado

Caso de teste 2: acionamento do `LED_BUILTIN` da UCE.

1. a UI aciona `SetBuiltinLedAsync`
2. o comando entra em `FrmUceLogic -> UceClient -> SdhClient -> SdgwSession`
3. a BPM valida o target lógico `0x2` e roteia para `GwSpiBus`
4. a UCE recebe o TLV por `SPI`, aplica o estado do LED e arma a resposta
5. a UCE sinaliza resposta pronta por `IRQ`
6. a BPM lê `header` e `payload+CRC` em dois bursts SPI
7. o `UceClient` valida a resposta síncrona
8. a UI confirma o estado aplicado do `LED_BUILTIN`

Caso de teste 3: configuração e leitura de status da porta CAN da UCE.

1. a UI aciona `UCE.can.status get controller=can0` ao carregar a janela
2. a UI envia `UCE.can.config set controller=can0 bitrate=... mode=...` ao alterar velocidade ou modo
3. a UI envia `UCE.can.enable set controller=can0 state=on|off` ao alterar o checkbox da porta
4. o comando entra em `FrmUceLogic -> UceClient -> SdhClient -> SdgwSession`
5. a BPM mantém a mesma rota lógica `0x2` e segue para `GwSpiBus`
6. a UCE despacha `CMD_CAN_CONFIG`, `CMD_CAN_ENABLE` ou `CMD_CAN_STATUS` em `Service`
7. a response TLV síncrona volta ao host com `CRC`
8. a UI atualiza o texto de status da CAN

Observação:

- este roteiro já está implementado no código e comissionado por build
- a validação física em bancada da feature CAN ainda precisa ser executada e registrada

## Evidências técnicas esperadas

- o host entra em `Linked`
- o comando funcional passa pela fila central de TX
- há RX SDGW válido mantendo a saúde do link
- a BPM não derruba a sessão só por ausência de ping explícito
- o router responde dentro da janela operacional atual
- o fluxo SPI da UCE fecha com `CRC` válido
- a feature CAN da UCE reutiliza exatamente a mesma rota compacta da board, sem `GW_OP` novo

## Parâmetros relevantes no cenário atual

- supervisor do host com ping apenas sob silêncio
- timeout lógico do host em `3000 ms`
- timeout de atividade da BPM em `4000 ms`
- timeout do router/gateway em `100 ms`
- comando de LED da GSA com timeout de `400 ms` e `2` retries

## Limitações

O procedimento ainda depende:

- de observação do operador
- da montagem física correta
- de instrumentação manual quando for necessário isolar falha entre host, BPM e board

## Evolução prevista

Os testes de bancada podem evoluir para:

- roteiros repetíveis por board
- captura estruturada de payloads e respostas
- checklists de diagnóstico por camada
- ampliação para novos comandos além da GSA
- ampliação de casos de uso da UCE além do `LED_BUILTIN`
- validação física específica de `UCE.can.config`, `UCE.can.enable`, `UCE.can.status` e `UCE.can reset`

## Glossário

- **Caso de uso**: fluxo funcional documentado para operação, simulação, diagnóstico ou teste.
- **GSA**: board de geração de sinais analógicos hoje mais madura na árvore oficial.
- **Evento**: mensagem assíncrona publicada durante ou após uma operação.
- **Validação**: verificação de comportamento esperado em bancada.
- **SDGW**: nomenclatura oficial vigente do enlace host/gateway: SimulDiesel GateWay.

## Próximas camadas

- [Testes de Hardware](../10-testes/01-testes-hardware.md)
- [Testes de Firmware](../10-testes/02-testes-firmware.md)
- [Testes de Integração](../10-testes/03-testes-integracao.md)

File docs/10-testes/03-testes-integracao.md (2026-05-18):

⬅ [Retornar para Testes de Bancada](../08-casos-de-uso/03-testes-bancada.md)
⬅ [Retornar para Índice Geral](../00-INDICE.md)

# Testes de Integração

## Estado atual

Os testes de integração mais relevantes do projeto são os que atravessam toda a cadeia:

    WinForms -> host SDGW/SDH -> BPM -> baby board

Historicamente, o caso mais representativo foi o fluxo do LED da GSA.

Com a entrada da UCE no host e no gateway, esse cenário continua válido como teste-base, mas já não é o único fluxo funcional relevante. A tela da UCE agora também possui integração real para configuração da porta CAN usando a mesma rota compacta da UCE.

## Caminho integrado real

```text
WinForms
  -> FrmGsaLogic / FrmUceLogic / FrmBpmLogic
  -> BpmSerialService.Shared
  -> GsaClient / UceClient / BpmClient
  -> SdhClient
  -> SdgwSession
  -> SdGwTxScheduler
  -> SdGwLinkEngine
  -> SerialTransport
  -> BPM / link do gateway / GatewayApp
  -> GwRouter
  -> I2C / SPI
  -> GSA / UCE
```

## Cenários de integração mais representativos

Caso de teste: alterar o estado do LED embutido da GSA.

1. a UI dispara o comando
2. o `GsaClient` monta `SdhCommand` para `GSA.led`
3. o `SdhClient` valida e mapeia para SDGW compacto
4. o `SdGwTxScheduler` envia em prioridade `High`
5. o `SdGwLinkEngine` aguarda `ACK`
6. a BPM valida o frame e roteia a transação para a GSA
7. a GSA devolve a resposta TLV síncrona
8. a BPM devolve essa resposta ao host
9. a GSA conclui a etapa física, aciona IRQ e publica `0x31`
10. a BPM busca o evento e o reencaminha ao host
11. o `GsaClient` valida a resposta síncrona e o evento físico final

Caso de teste: alterar o estado do `LED_BUILTIN` da UCE.

1. a UI dispara o comando em `frmUCE_UI`
2. o `UceClient` monta `SdhCommand` para `UCE.led`
3. o `SdhClient` valida e mapeia para `SDGW_CMD_UCE_TLV`
4. o `SdGwTxScheduler` envia em prioridade `High`
5. a BPM valida o frame e roteia a transação para `GwSpiBus`
6. a UCE devolve a resposta TLV síncrona por `SPI`
7. a BPM valida o `CRC` da resposta da UCE
8. o `UceClient` confirma o estado aceito do `LED_BUILTIN`

Caso de teste: configurar a porta CAN da UCE.

1. a UI dispara `UCE.can.config set controller=can0 bitrate=... mode=...`
2. `FrmUceLogic` mantém o controller fixo em `can0`
3. `UceClient` monta o `SdhCommand` e espera uma response fixa de `0x20`
4. o `SdhClient` valida e mapeia para `SDGW_CMD_UCE_TLV`
5. a BPM mantém o mesmo binding lógico `0x2` e roteia a transação para `GwSpiBus`
6. a UCE despacha `CMD_CAN_CONFIG` em `Service` e chama `CanService::configure(...)`
7. a UCE devolve response TLV síncrona com controller, bitrate e modo aceitos
8. o host atualiza a UI a partir de `UCE.can.status get`

Caso de teste: habilitar, desabilitar e consultar status da porta CAN da UCE.

1. a UI envia `UCE.can.enable set controller=can0 state=on|off`
2. a UCE mapeia `state=on` para `CanService::open()` e `state=off` para `CanService::close()`
3. a UI envia `UCE.can.status get controller=can0`
4. a UCE responde com `controller`, `interface_state`, `bitrate_code` e `mode`
5. o `UceClient` e `UceParsers` atualizam a UI com status textual compacto

## Evidências atuais de robustez

- estados de link explícitos no `BpmSerialService`
- stop-and-wait técnico concentrado no `SdGwLinkEngine`
- arbitragem de TX centralizada no `SdGwTxScheduler`
- keepalive por atividade SDGW válida no host e na BPM
- tolerância do host para `ACK`s e respostas tardias após o primeiro `Linked`

## O que não deve mais ser tratado como fluxo principal

Os testes de integração não devem mais assumir:

- envio manual de ping como passo central da operação normal
- concorrência interna resolvida por `Busy`
- arquitetura baseada em `SerialLink`, `SerialLinkService`, `SdGgwClient` ou `SdgwHealthService`

## Limitações

O conjunto de testes de integração ainda é pequeno em diversidade funcional.

Hoje:

- o caso GSA LED é o principal cenário ponta a ponta já exercitado
- o caso UCE LED já foi validado em bancada com resposta síncrona e `CRC` estável
- a feature CAN da UCE foi comissionada por análise de fluxo e build, mas ainda não teve validação física registrada em bancada nesta rodada
- ainda faltam roteiros equivalentes para setpoint, status, offsets e fault event da GSA
- o roteiro oficial precisa validar também o caminho físico `D21/D22`, `D4/D19` e `D23`
- o roteiro oficial agora também cobre `SPI 18/26/25`, `CS 33`, `IRQ 27` e `RESET 23` para a UCE
- ainda não há cobertura equivalente para múltiplas boards em paralelo
- a recepção funcional ainda é baseada em frame lógico tipado do enlace
- não há evento assíncrono novo da UCE para a feature CAN
- o comando `UCE.can reset ...` existe no contrato e na implementação, mas não está ligado a um botão da UI

## Evolução prevista

Os próximos ganhos naturais são:

- mais cenários além do LED
- validação física em bancada da configuração CAN da UCE
- roteiros específicos para:
  - `GSA.channel.status`
  - `GSA.channels.status`
  - `GSA.channel.offset`
  - evento assíncrono de fault
- roteiros específicos para `UCE.can.config`, `UCE.can.enable` e `UCE.can.status`
- validação de eventos assíncronos
- testes cruzando múltiplos destinos da BPM
- maior formalização dos roteiros de integração

## Glossário

- **Caso de uso**: fluxo funcional documentado para operação, simulação, diagnóstico ou teste.
- **GSA**: board de geração de sinais analógicos hoje mais madura na árvore oficial.
- **Evento**: mensagem assíncrona publicada durante ou após uma operação.
- **Validação**: verificação de comportamento esperado em bancada.
- **SDGW**: nomenclatura oficial vigente do enlace host/gateway: SimulDiesel GateWay.
- **SDH**: SimulDiesel Hardware Command, envelope semântico de comandos do projeto.
- **TLV**: Type-Length-Value, formato interno de payload usado em transações específicas.

## Próximas camadas

- Esta é uma página terminal deste ramo da documentação.

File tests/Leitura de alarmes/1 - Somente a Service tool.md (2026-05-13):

# Sessao
Id: 880fba0af21b4912ba5a74ef5fa05972
Inicio: 2026-05-13 16:35:53.286
Fim: 2026-05-13 16:35:55.826
DuracaoMs: 2540
FramesRecebidos: 3
FramesUnicos: 1
EventosExportados: 2

# Resumo por PGN
- PGN=0x00DA00 eventos=2 frames=4

# Resumo por Source Address
- SA=0xF9 eventos=2 frames=4

# Address Claims detectados

# Periodicidade detectada
- 2026-05-13 16:35:55.447 SA=0xF9 DST=GLOBAL PGN=0x00DA00 intervalo_ms=1014 repeticoes=3

# Top talkers
- SA=0xF9 frames=4

# Eventos
[2026-05-13 16:35:53.418]
DeltaMs: 0
Origem: 0xF9
Destino: GLOBAL
RawCanId: 0x18DAFFF9
PGN: 0x00DA00
Dados: 01 3E FF FF FF FF FF FF
Evento: NEW_FRAME
Repeticoes: 1
Notas: Pipeline Dados J1939

[2026-05-13 16:35:55.447]
DeltaMs: 2028
Origem: 0xF9
Destino: GLOBAL
RawCanId: 0x18DAFFF9
PGN: 0x00DA00
Dados: 01 3E FF FF FF FF FF FF
Evento: PERIODIC_TICK
Repeticoes: 3
IntervaloMs: 1014
Notas: Frames identicos consecutivos agrupados para reduzir spam temporal.

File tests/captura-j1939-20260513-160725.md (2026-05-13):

# Sessao
Id: 6518f6d07f4d49b2883eb52c6af58779
Inicio: 2026-05-13 16:07:18.271
Fim: 2026-05-13 16:07:25.845
DuracaoMs: 7573
FramesRecebidos: 281
FramesUnicos: 281
EventosExportados: 281

# Resumo por PGN
- PGN=0x00FF2A eventos=75 frames=75
- PGN=0x00FF25 eventos=38 frames=38
- PGN=0x00FF26 eventos=37 frames=37
- PGN=0x00FF27 eventos=37 frames=37
- PGN=0x00FF28 eventos=15 frames=15
- PGN=0x00FF29 eventos=15 frames=15
- PGN=0x00FF7C eventos=15 frames=15
- PGN=0x000000 eventos=7 frames=7
- PGN=0x00FF11 eventos=7 frames=7
- PGN=0x00FF15 eventos=7 frames=7
- PGN=0x00FF2B eventos=7 frames=7
- PGN=0x00FF2C eventos=7 frames=7
- PGN=0x00FFA7 eventos=7 frames=7
- PGN=0x00FFA8 eventos=7 frames=7

# Resumo por Source Address
- SA=0xC0 eventos=281 frames=281

# Periodicidade detectada

# Top talkers
- SA=0xC0 frames=281

# Eventos
[2026-05-13 16:07:18.240]
DeltaMs: 0
Origem: 0xC0
Destino: GLOBAL
PGN: 0x00FF25
Dados: 00 FF 00 00 00 00 00 00
Evento: NEW_FRAME
Repeticoes: 1
Notas: Pipeline Dados J1939

[2026-05-13 16:07:18.280]
DeltaMs: 39
Origem: 0xC0
Destino: GLOBAL
PGN: 0x00FF2A
Dados: 91 FF 00 00 81 FF FF FF
Evento: TRANSITION
Repeticoes: 1
Notas: Transicao detectada por mudanca de PGN, payload.

[2026-05-13 16:07:18.371]
DeltaMs: 90
Origem: 0xC0
Destino: GLOBAL
PGN: 0x00FF26
Dados: 00 00 00 00 00 00 00 00
Evento: TRANSITION
Repeticoes: 1
Notas: Transicao detectada por mudanca de PGN, payload.

[2026-05-13 16:07:18.371]
DeltaMs: 0
Origem: 0xC0
Destino: GLOBAL
PGN: 0x00FF27
Dados: 00 FF 00 00 00 00 00 00
Evento: TRANSITION
Repeticoes: 1
Notas: Transicao detectada por mudanca de PGN, payload.

[2026-05-13 16:07:18.380]
DeltaMs: 8
Origem: 0xC0
Destino: GLOBAL
PGN: 0x00FF2A
Dados: 91 FF 00 00 81 FF FF FF
Evento: TRANSITION
Repeticoes: 1
Notas: Transicao detectada por mudanca de PGN, payload.

[2026-05-13 16:07:18.440]
DeltaMs: 59
Origem: 0xC0
Destino: GLOBAL
PGN: 0x00FF25
Dados: 00 FF 00 00 00 00 00 00
Evento: TRANSITION
Repeticoes: 1
Notas: Transicao detectada por mudanca de PGN, payload.

[2026-05-13 16:07:18.481]
DeltaMs: 40
Origem: 0xC0
Destino: GLOBAL
PGN: 0x00FF2A
Dados: 91 FF 00 00 81 FF FF FF
Evento: TRANSITION
Repeticoes: 1
Notas: Transicao detectada por mudanca de PGN, payload.

[2026-05-13 16:07:18.571]
DeltaMs: 89
Origem: 0xC0
Destino: GLOBAL
PGN: 0x00FF26
Dados: 00 00 00 00 00 00 00 00
Evento: TRANSITION
Repeticoes: 1
Notas: Transicao detectada por mudanca de PGN, payload.

[2026-05-13 16:07:18.572]
DeltaMs: 0
Origem: 0xC0
Destino: GLOBAL
PGN: 0x00FF27
Dados: 00 FF 00 00 00 00 00 00
Evento: TRANSITION
Repeticoes: 1
Notas: Transicao detectada por mudanca de PGN, payload.

[2026-05-13 16:07:18.581]
DeltaMs: 8
Origem: 0xC0
Destino: GLOBAL
PGN: 0x00FF2A
Dados: 91 FF 00 00 81 FF FF FF
Evento: TRANSITION
Repeticoes: 1
Notas: Transicao detectada por mudanca de PGN, payload.

[2026-05-13 16:07:18.641]
DeltaMs: 59
Origem: 0xC0
Destino: GLOBAL
PGN: 0x00FF25
Dados: 00 FF 00 00 00 00 00 00
Evento: TRANSITION
Repeticoes: 1
Notas: Transicao detectada por mudanca de PGN, payload.

[2026-05-13 16:07:18.672]
DeltaMs: 30
Origem: 0xC0
Destino: GLOBAL
PGN: 0x00FF28
Dados: 00 FF 00 FE FF FE FE 01
Evento: TRANSITION
Repeticoes: 1
Notas: Transicao detectada por mudanca de PGN, payload.

[2026-05-13 16:07:18.672]
DeltaMs: 0
Origem: 0xC0
Destino: GLOBAL
PGN: 0x00FF29
Dados: C4 00 00 00 05 3F FF FF
Evento: TRANSITION
Repeticoes: 1
Notas: Transicao detectada por mudanca de PGN, payload.

[2026-05-13 16:07:18.682]
DeltaMs: 9
Origem: 0xC0
Destino: GLOBAL
PGN: 0x00FF2A
Dados: 91 FF 00 00 81 FF FF FF
Evento: TRANSITION
Repeticoes: 1
Notas: Transicao detectada por mudanca de PGN, payload.

[2026-05-13 16:07:18.682]
DeltaMs: 0
Origem: 0xC0
Destino: GLOBAL
PGN: 0x00FF7C
Dados: FF FF FF FF FF FF FF FC
Evento: TRANSITION
Repeticoes: 1
Notas: Transicao detectada por mudanca de PGN, payload.

[2026-05-13 16:07:18.772]
DeltaMs: 90
Origem: 0xC0
Destino: GLOBAL
PGN: 0x00FF26
Dados: 00 00 00 00 00 00 00 00
Evento: TRANSITION
Repeticoes: 1
Notas: Transicao detectada por mudanca de PGN, payload.

[2026-05-13 16:07:18.772]
DeltaMs: 0
Origem: 0xC0
Destino: GLOBAL
PGN: 0x00FF27
Dados: 00 FF 00 00 00 00 00 00
Evento: TRANSITION
Repeticoes: 1
Notas: Transicao detectada por mudanca de PGN, payload.

[2026-05-13 16:07:18.781]
DeltaMs: 9
Origem: 0xC0
Destino: GLOBAL
PGN: 0x00FF2A
Dados: 91 FF 00 00 81 FF FF FF
Evento: TRANSITION
Repeticoes: 1
Notas: Transicao detectada por mudanca de PGN, payload.

[2026-05-13 16:07:18.841]
DeltaMs: 60
Origem: 0xC0
Destino: GLOBAL
PGN: 0x00FF25
Dados: 00 FF 00 00 00 00 00 00
Evento: TRANSITION
Repeticoes: 1
Notas: Transicao detectada por mudanca de PGN, payload.

[2026-05-13 16:07:18.881]
DeltaMs: 39
Origem: 0xC0
Destino: GLOBAL
PGN: 0x00FF2A
Dados: 91 FF 00 00 81 FF FF FF
Evento: TRANSITION
Repeticoes: 1
Notas: Transicao detectada por mudanca de PGN, payload.

[2026-05-13 16:07:18.972]
DeltaMs: 91
Origem: 0xC0
Destino: GLOBAL
PGN: 0x00FF26
Dados: 00 00 00 00 00 00 00 00
Evento: TRANSITION
Repeticoes: 1
Notas: Transicao detectada por mudanca de PGN, payload.

[2026-05-13 16:07:18.972]
DeltaMs: 0
Origem: 0xC0
Destino: GLOBAL
PGN: 0x00FF27
Dados: 00 FF 00 00 00 00 00 00
Evento: TRANSITION
Repeticoes: 1
Notas: Transicao detectada por mudanca de PGN, payload.

[2026-05-13 16:07:18.981]
DeltaMs: 8
Origem: 0xC0
Destino: GLOBAL
PGN: 0x00FF2A
Dados: 91 FF 00 00 81 FF FF FF
Evento: TRANSITION
Repeticoes: 1
Notas: Transicao detectada por mudanca de PGN, payload.

[2026-05-13 16:07:19.042]
DeltaMs: 60
Origem: 0xC0
Destino: 0x00
PGN: 0x000000
Dados: 00 00 00 FA FF FF FF FF
Evento: TRANSITION
Repeticoes: 1
Notas: Transicao detectada por mudanca de destino, PGN, payload.

[2026-05-13 16:07:19.042]
DeltaMs: 0
Origem: 0xC0
Destino: GLOBAL
PGN: 0x00FF11
Dados: FF FF FF FF FF FF FF FF
Evento: TRANSITION
Repeticoes: 1
Notas: Transicao detectada por mudanca de destino, PGN, payload.

[2026-05-13 16:07:19.042]
DeltaMs: 0
Origem: 0xC0
Destino: GLOBAL
PGN: 0x00FF15
Dados: FF FF FF 00 FF FF FF FF
Evento: TRANSITION
Repeticoes: 1
Notas: Transicao detectada por mudanca de PGN, payload.

[2026-05-13 16:07:19.044]
DeltaMs: 1
Origem: 0xC0
Destino: GLOBAL
PGN: 0x00FF25
Dados: 00 FF 00 00 00 00 00 00
Evento: TRANSITION
Repeticoes: 1
Notas: Transicao detectada por mudanca de PGN, payload.

[2026-05-13 16:07:19.081]
DeltaMs: 36
Origem: 0xC0
Destino: GLOBAL
PGN: 0x00FF2A
Dados: 91 FF 00 00 81 FF FF FF
Evento: TRANSITION
Repeticoes: 1
Notas: Transicao detectada por mudanca de PGN, payload.

[2026-05-13 16:07:19.172]
DeltaMs: 90
Origem: 0xC0
Destino: GLOBAL
PGN: 0x00FF26
Dados: 00 00 00 00 00 00 00 00
Evento: TRANSITION
Repeticoes: 1
Notas: Transicao detectada por mudanca de PGN, payload.

[2026-05-13 16:07:19.172]
DeltaMs: 0
Origem: 0xC0
Destino: GLOBAL
PGN: 0x00FF27
Dados: 00 FF 00 00 00 00 00 00
Evento: TRANSITION
Repeticoes: 1
Notas: Transicao detectada por mudanca de PGN, payload.

[2026-05-13 16:07:19.172]
DeltaMs: 0
Origem: 0xC0
Destino: GLOBAL
PGN: 0x00FF28
Dados: 00 FF 00 FE FF FE FE 01
Evento: TRANSITION
Repeticoes: 1
Notas: Transicao detectada por mudanca de PGN, payload.

[2026-05-13 16:07:19.174]
DeltaMs: 1
Origem: 0xC0
Destino: GLOBAL
PGN: 0x00FF29
Dados: C4 00 00 00 05 3F FF FF
Evento: TRANSITION
Repeticoes: 1
Notas: Transicao detectada por mudanca de PGN, payload.

[2026-05-13 16:07:19.182]
DeltaMs: 7
Origem: 0xC0
Destino: GLOBAL
PGN: 0x00FF2A
Dados: 91 FF 00 00 81 FF FF FF
Evento: TRANSITION
Repeticoes: 1
Notas: Transicao detectada por mudanca de PGN, payload.

[2026-05-13 16:07:19.182]
DeltaMs: 0
Origem: 0xC0
Destino: GLOBAL
PGN: 0x00FF2B
Dados: E3 C8 71 00 04 06 F7 B6
Evento: TRANSITION
Repeticoes: 1
Notas: Transicao detectada por mudanca de PGN, payload.

[2026-05-13 16:07:19.182]
DeltaMs: 0
Origem: 0xC0
Destino: GLOBAL
PGN: 0x00FF2C
Dados: 00 00 00 00 00 00 FF FF
Evento: TRANSITION
Repeticoes: 1
Notas: Transicao detectada por mudanca de PGN, payload.

[2026-05-13 16:07:19.184]
DeltaMs: 1
Origem: 0xC0
Destino: GLOBAL
PGN: 0x00FF7C
Dados: FF FF FF FF FF FF FF FC
Evento: TRANSITION
Repeticoes: 1
Notas: Transicao detectada por mudanca de PGN, payload.

[2026-05-13 16:07:19.192]
DeltaMs: 7
Origem: 0xC0
Destino: GLOBAL
PGN: 0x00FFA7
Dados: 40 17 9A 03 00 00 00 00
Evento: TRANSITION
Repeticoes: 1
Notas: Transicao detectada por mudanca de PGN, payload.

[2026-05-13 16:07:19.192]
DeltaMs: 0
Origem: 0xC0
Destino: GLOBAL
PGN: 0x00FFA8
Dados: FF FF FF FF FF FF FF FF
Evento: TRANSITION
Repeticoes: 1
Notas: Transicao detectada por mudanca de PGN, payload.

[2026-05-13 16:07:19.240]
DeltaMs: 48
Origem: 0xC0
Destino: GLOBAL
PGN: 0x00FF25
Dados: 00 FF 00 00 00 00 00 00
Evento: TRANSITION
Repeticoes: 1
Notas: Transicao detectada por mudanca de PGN, payload.

[2026-05-13 16:07:19.280]
DeltaMs: 39
Origem: 0xC0
Destino: GLOBAL
PGN: 0x00FF2A
Dados: 91 FF 00 00 81 FF FF FF
Evento: TRANSITION
Repeticoes: 1
Notas: Transicao detectada por mudanca de PGN, payload.

[2026-05-13 16:07:19.371]
DeltaMs: 90
Origem: 0xC0
Destino: GLOBAL
PGN: 0x00FF26
Dados: 00 00 00 00 00 00 00 00
Evento: TRANSITION
Repeticoes: 1
Notas: Transicao detectada por mudanca de PGN, payload.

[2026-05-13 16:07:19.371]
DeltaMs: 0
Origem: 0xC0
Destino: GLOBAL
PGN: 0x00FF27
Dados: 00 FF 00 00 00 00 00 00
Evento: TRANSITION
Repeticoes: 1
Notas: Transicao detectada por mudanca de PGN, payload.

[2026-05-13 16:07:19.380]
DeltaMs: 8
Origem: 0xC0
Destino: GLOBAL
PGN: 0x00FF2A
Dados: 91 FF 00 00 81 FF FF FF
Evento: TRANSITION
Repeticoes: 1
Notas: Transicao detectada por mudanca de PGN, payload.

[2026-05-13 16:07:19.440]
DeltaMs: 59
Origem: 0xC0
Destino: GLOBAL
PGN: 0x00FF25
Dados: 00 FF 00 00 00 00 00 00
Evento: TRANSITION
Repeticoes: 1
Notas: Transicao detectada por mudanca de PGN, payload.

[2026-05-13 16:07:19.493]
DeltaMs: 52
Origem: 0xC0
Destino: GLOBAL
PGN: 0x00FF2A
Dados: 91 FF 00 00 81 FF FF FF
Evento: TRANSITION
Repeticoes: 1
Notas: Transicao detectada por mudanca de PGN, payload.

[2026-05-13 16:07:19.577]
DeltaMs: 83
Origem: 0xC0
Destino: GLOBAL
PGN: 0x00FF26
Dados: 00 00 00 00 00 00 00 00
Evento: TRANSITION
Repeticoes: 1
Notas: Transicao detectada por mudanca de PGN, payload.

[2026-05-13 16:07:19.577]
DeltaMs: 0
Origem: 0xC0
Destino: GLOBAL
PGN: 0x00FF27
Dados: 00 FF 00 00 00 00 00 00
Evento: TRANSITION
Repeticoes: 1
Notas: Transicao detectada por mudanca de PGN, payload.

[2026-05-13 16:07:19.581]
DeltaMs: 3
Origem: 0xC0
Destino: GLOBAL
PGN: 0x00FF2A
Dados: 91 FF 00 00 81 FF FF FF
Evento: TRANSITION
Repeticoes: 1
Notas: Transicao detectada por mudanca de PGN, payload.

[2026-05-13 16:07:19.641]
DeltaMs: 59
Origem: 0xC0
Destino: GLOBAL
PGN: 0x00FF25
Dados: 00 FF 00 00 00 00 00 00
Evento: TRANSITION
Repeticoes: 1
Notas: Transicao detectada por mudanca de PGN, payload.

[2026-05-13 16:07:19.672]
DeltaMs: 30
Origem: 0xC0
Destino: GLOBAL
PGN: 0x00FF28
Dados: 00 FF 00 FE FF FE FE 01
Evento: TRANSITION
Repeticoes: 1
Notas: Transicao detectada por mudanca de PGN, payload.

[2026-05-13 16:07:19.672]
DeltaMs: 0
Origem: 0xC0
Destino: GLOBAL
PGN: 0x00FF29
Dados: C4 00 00 00 05 3F FF FF
Evento: TRANSITION
Repeticoes: 1
Notas: Transicao detectada por mudanca de PGN, payload.

[2026-05-13 16:07:19.682]
DeltaMs: 9
Origem: 0xC0
Destino: GLOBAL
PGN: 0x00FF2A
Dados: 91 FF 00 00 81 FF FF FF
Evento: TRANSITION
Repeticoes: 1
Notas: Transicao detectada por mudanca de PGN, payload.

[2026-05-13 16:07:19.682]
DeltaMs: 0
Origem: 0xC0
Destino: GLOBAL
PGN: 0x00FF7C
Dados: FF FF FF FF FF FF FF FC
Evento: TRANSITION
Repeticoes: 1
Notas: Transicao detectada por mudanca de PGN, payload.

[2026-05-13 16:07:19.772]
DeltaMs: 89
Origem: 0xC0
Destino: GLOBAL
PGN: 0x00FF26
Dados: 00 00 00 00 00 00 00 00
Evento: TRANSITION
Repeticoes: 1
Notas: Transicao detectada por mudanca de PGN, payload.

[2026-05-13 16:07:19.772]
DeltaMs: 0
Origem: 0xC0
Destino: GLOBAL
PGN: 0x00FF27
Dados: 00 FF 00 00 00 00 00 00
Evento: TRANSITION
Repeticoes: 1
Notas: Transicao detectada por mudanca de PGN, payload.

[2026-05-13 16:07:19.781]
DeltaMs: 9
Origem: 0xC0
Destino: GLOBAL
PGN: 0x00FF2A
Dados: 91 FF 00 00 81 FF FF FF
Evento: TRANSITION
Repeticoes: 1
Notas: Transicao detectada por mudanca de PGN, payload.

[2026-05-13 16:07:19.841]
DeltaMs: 59
Origem: 0xC0
Destino: GLOBAL
PGN: 0x00FF25
Dados: 00 FF 00 00 00 00 00 00
Evento: TRANSITION
Repeticoes: 1
Notas: Transicao detectada por mudanca de PGN, payload.

[2026-05-13 16:07:19.881]
DeltaMs: 40
Origem: 0xC0
Destino: GLOBAL
PGN: 0x00FF2A
Dados: 91 FF 00 00 81 FF FF FF
Evento: TRANSITION
Repeticoes: 1
Notas: Transicao detectada por mudanca de PGN, payload.

[2026-05-13 16:07:19.972]
DeltaMs: 91
Origem: 0xC0
Destino: GLOBAL
PGN: 0x00FF26
Dados: 00 00 00 00 00 00 00 00
Evento: TRANSITION
Repeticoes: 1
Notas: Transicao detectada por mudanca de PGN, payload.

[2026-05-13 16:07:19.972]
DeltaMs: 0
Origem: 0xC0
Destino: GLOBAL
PGN: 0x00FF27
Dados: 00 FF 00 00 00 00 00 00
Evento: TRANSITION
Repeticoes: 1
Notas: Transicao detectada por mudanca de PGN, payload.

[2026-05-13 16:07:19.981]
DeltaMs: 8
Origem: 0xC0
Destino: GLOBAL
PGN: 0x00FF2A
Dados: 91 FF 00 00 81 FF FF FF
Evento: TRANSITION
Repeticoes: 1
Notas: Transicao detectada por mudanca de PGN, payload.

[2026-05-13 16:07:20.042]
DeltaMs: 61
Origem: 0xC0
Destino: 0x00
PGN: 0x000000
Dados: 00 00 00 FA FF FF FF FF
Evento: TRANSITION
Repeticoes: 1
Notas: Transicao detectada por mudanca de destino, PGN, payload.

[2026-05-13 16:07:20.042]
DeltaMs: 0
Origem: 0xC0
Destino: GLOBAL
PGN: 0x00FF11
Dados: FF FF FF FF FF FF FF FF
Evento: TRANSITION
Repeticoes: 1
Notas: Transicao detectada por mudanca de destino, PGN, payload.

[2026-05-13 16:07:20.042]
DeltaMs: 0
Origem: 0xC0
Destino: GLOBAL
PGN: 0x00FF15
Dados: FF FF FF 00 FF FF FF FF
Evento: TRANSITION
Repeticoes: 1
Notas: Transicao detectada por mudanca de PGN, payload.

[2026-05-13 16:07:20.043]
DeltaMs: 1
Origem: 0xC0
Destino: GLOBAL
PGN: 0x00FF25
Dados: 00 FF 00 00 00 00 00 00
Evento: TRANSITION
Repeticoes: 1
Notas: Transicao detectada por mudanca de PGN, payload.

[2026-05-13 16:07:20.081]
DeltaMs: 37
Origem: 0xC0
Destino: GLOBAL
PGN: 0x00FF2A
Dados: 91 FF 00 00 81 FF FF FF
Evento: TRANSITION
Repeticoes: 1
Notas: Transicao detectada por mudanca de PGN, payload.

[2026-05-13 16:07:20.172]
DeltaMs: 91
Origem: 0xC0
Destino: GLOBAL
PGN: 0x00FF26
Dados: 00 00 00 00 00 00 00 00
Evento: TRANSITION
Repeticoes: 1
Notas: Transicao detectada por mudanca de PGN, payload.

[2026-05-13 16:07:20.172]
DeltaMs: 0
Origem: 0xC0
Destino: GLOBAL
PGN: 0x00FF27
Dados: 00 FF 00 00 00 00 00 00
Evento: TRANSITION
Repeticoes: 1
Notas: Transicao detectada por mudanca de PGN, payload.

[2026-05-13 16:07:20.172]
DeltaMs: 0
Origem: 0xC0
Destino: GLOBAL
PGN: 0x00FF28
Dados: 00 FF 00 FE FF FE FE 01
Evento: TRANSITION
Repeticoes: 1
Notas: Transicao detectada por mudanca de PGN, payload.

[2026-05-13 16:07:20.174]
DeltaMs: 1
Origem: 0xC0
Destino: GLOBAL
PGN: 0x00FF29
Dados: C4 00 00 00 05 3F FF FF
Evento: TRANSITION
Repeticoes: 1
Notas: Transicao detectada por mudanca de PGN, payload.

[2026-05-13 16:07:20.181]
DeltaMs: 6
Origem: 0xC0
Destino: GLOBAL
PGN: 0x00FF2A
Dados: 91 FF 00 00 81 FF FF FF
Evento: TRANSITION
Repeticoes: 1
Notas: Transicao detectada por mudanca de PGN, payload.

[2026-05-13 16:07:20.182]
DeltaMs: 0
Origem: 0xC0
Destino: GLOBAL
PGN: 0x00FF2B
Dados: E3 C8 71 00 04 06 F7 B6
Evento: TRANSITION
Repeticoes: 1
Notas: Transicao detectada por mudanca de PGN, payload.

[2026-05-13 16:07:20.182]
DeltaMs: 0
Origem: 0xC0
Destino: GLOBAL
PGN: 0x00FF2C
Dados: 00 00 00 00 00 00 FF FF
Evento: TRANSITION
Repeticoes: 1
Notas: Transicao detectada por mudanca de PGN, payload.

[2026-05-13 16:07:20.183]
DeltaMs: 0
Origem: 0xC0
Destino: GLOBAL
PGN: 0x00FF7C
Dados: FF FF FF FF FF FF FF FC
Evento: TRANSITION
Repeticoes: 1
Notas: Transicao detectada por mudanca de PGN, payload.

[2026-05-13 16:07:20.191]
DeltaMs: 7
Origem: 0xC0
Destino: GLOBAL
PGN: 0x00FFA7
Dados: 40 17 9A 03 00 00 00 00
Evento: TRANSITION
Repeticoes: 1
Notas: Transicao detectada por mudanca de PGN, payload.

[2026-05-13 16:07:20.192]
DeltaMs: 0
Origem: 0xC0
Destino: GLOBAL
PGN: 0x00FFA8
Dados: FF FF FF FF FF FF FF FF
Evento: TRANSITION
Repeticoes: 1
Notas: Transicao detectada por mudanca de PGN, payload.

[2026-05-13 16:07:20.241]
DeltaMs: 48
Origem: 0xC0
Destino: GLOBAL
PGN: 0x00FF25
Dados: 00 FF 00 00 00 00 00 00
Evento: TRANSITION
Repeticoes: 1
Notas: Transicao detectada por mudanca de PGN, payload.

[2026-05-13 16:07:20.281]
DeltaMs: 39
Origem: 0xC0
Destino: GLOBAL
PGN: 0x00FF2A
Dados: 91 FF 00 00 81 FF FF FF
Evento: TRANSITION
Repeticoes: 1
Notas: Transicao detectada por mudanca de PGN, payload.

[2026-05-13 16:07:20.372]
DeltaMs: 90
Origem: 0xC0
Destino: GLOBAL
PGN: 0x00FF26
Dados: 00 00 00 00 00 00 00 00
Evento: TRANSITION
Repeticoes: 1
Notas: Transicao detectada por mudanca de PGN, payload.

[2026-05-13 16:07:20.372]
DeltaMs: 0
Origem: 0xC0
Destino: GLOBAL
PGN: 0x00FF27
Dados: 00 FF 00 00 00 00 00 00
Evento: TRANSITION
Repeticoes: 1
Notas: Transicao detectada por mudanca de PGN, payload.

[2026-05-13 16:07:20.381]
DeltaMs: 8
Origem: 0xC0
Destino: GLOBAL
PGN: 0x00FF2A
Dados: 91 FF 00 00 81 FF FF FF
Evento: TRANSITION
Repeticoes: 1
Notas: Transicao detectada por mudanca de PGN, payload.

[2026-05-13 16:07:20.442]
DeltaMs: 60
Origem: 0xC0
Destino: GLOBAL
PGN: 0x00FF25
Dados: 00 FF 00 00 00 00 00 00
Evento: TRANSITION
Repeticoes: 1
Notas: Transicao detectada por mudanca de PGN, payload.

[2026-05-13 16:07:20.481]
DeltaMs: 38
Origem: 0xC0
Destino: GLOBAL
PGN: 0x00FF2A
Dados: 91 FF 00 00 81 FF FF FF
Evento: TRANSITION
Repeticoes: 1
Notas: Transicao detectada por mudanca de PGN, payload.

[2026-05-13 16:07:20.572]
DeltaMs: 90
Origem: 0xC0
Destino: GLOBAL
PGN: 0x00FF26
Dados: 00 00 00 00 00 00 00 00
Evento: TRANSITION
Repeticoes: 1
Notas: Transicao detectada por mudanca de PGN, payload.

[2026-05-13 16:07:20.572]
DeltaMs: 0
Origem: 0xC0
Destino: GLOBAL
PGN: 0x00FF27
Dados: 00 FF 00 00 00 00 00 00
Evento: TRANSITION
Repeticoes: 1
Notas: Transicao detectada por mudanca de PGN, payload.

[2026-05-13 16:07:20.581]
DeltaMs: 8
Origem: 0xC0
Destino: GLOBAL
PGN: 0x00FF2A
Dados: 91 FF 00 00 81 FF FF FF
Evento: TRANSITION
Repeticoes: 1
Notas: Transicao detectada por mudanca de PGN, payload.

[2026-05-13 16:07:20.641]
DeltaMs: 59
Origem: 0xC0
Destino: GLOBAL
PGN: 0x00FF25
Dados: 00 FF 00 00 00 00 00 00
Evento: TRANSITION
Repeticoes: 1
Notas: Transicao detectada por mudanca de PGN, payload.

[2026-05-13 16:07:20.672]
DeltaMs: 30
Origem: 0xC0
Destino: GLOBAL
PGN: 0x00FF28
Dados: 00 FF 00 FE FF FE FE 01
Evento: TRANSITION
Repeticoes: 1
Notas: Transicao detectada por mudanca de PGN, payload.

[2026-05-13 16:07:20.672]
DeltaMs: 0
Origem: 0xC0
Destino: GLOBAL
PGN: 0x00FF29
Dados: C4 00 00 00 05 3F FF FF
Evento: TRANSITION
Repeticoes: 1
Notas: Transicao detectada por mudanca de PGN, payload.

[2026-05-13 16:07:20.682]
DeltaMs: 9
Origem: 0xC0
Destino: GLOBAL
PGN: 0x00FF2A
Dados: 91 FF 00 00 81 FF FF FF
Evento: TRANSITION
Repeticoes: 1
Notas: Transicao detectada por mudanca de PGN, payload.

[2026-05-13 16:07:20.682]
DeltaMs: 0
Origem: 0xC0
Destino: GLOBAL
PGN: 0x00FF7C
Dados: FF FF FF FF FF FF FF FC
Evento: TRANSITION
Repeticoes: 1
Notas: Transicao detectada por mudanca de PGN, payload.

[2026-05-13 16:07:20.772]
DeltaMs: 89
Origem: 0xC0
Destino: GLOBAL
PGN: 0x00FF26
Dados: 00 00 00 00 00 00 00 00
Evento: TRANSITION
Repeticoes: 1
Notas: Transicao detectada por mudanca de PGN, payload.

[2026-05-13 16:07:20.772]
DeltaMs: 0
Origem: 0xC0
Destino: GLOBAL
PGN: 0x00FF27
Dados: 00 FF 00 00 00 00 00 00
Evento: TRANSITION
Repeticoes: 1
Notas: Transicao detectada por mudanca de PGN, payload.

[2026-05-13 16:07:20.781]
DeltaMs: 8
Origem: 0xC0
Destino: GLOBAL
PGN: 0x00FF2A
Dados: 91 FF 00 00 81 FF FF FF
Evento: TRANSITION
Repeticoes: 1
Notas: Transicao detectada por mudanca de PGN, payload.

[2026-05-13 16:07:20.841]
DeltaMs: 59
Origem: 0xC0
Destino: GLOBAL
PGN: 0x00FF25
Dados: 00 FF 00 00 00 00 00 00
Evento: TRANSITION
Repeticoes: 1
Notas: Transicao detectada por mudanca de PGN, payload.

[2026-05-13 16:07:20.881]
DeltaMs: 40
Origem: 0xC0
Destino: GLOBAL
PGN: 0x00FF2A
Dados: 91 FF 00 00 81 FF FF FF
Evento: TRANSITION
Repeticoes: 1
Notas: Transicao detectada por mudanca de PGN, payload.

[2026-05-13 16:07:20.972]
DeltaMs: 90
Origem: 0xC0
Destino: GLOBAL
PGN: 0x00FF26
Dados: 00 00 00 00 00 00 00 00
Evento: TRANSITION
Repeticoes: 1
Notas: Transicao detectada por mudanca de PGN, payload.

[2026-05-13 16:07:20.972]
DeltaMs: 0
Origem: 0xC0
Destino: GLOBAL
PGN: 0x00FF27
Dados: 00 FF 00 00 00 00 00 00
Evento: TRANSITION
Repeticoes: 1
Notas: Transicao detectada por mudanca de PGN, payload.

[2026-05-13 16:07:20.981]
DeltaMs: 8
Origem: 0xC0
Destino: GLOBAL
PGN: 0x00FF2A
Dados: 91 FF 00 00 81 FF FF FF
Evento: TRANSITION
Repeticoes: 1
Notas: Transicao detectada por mudanca de PGN, payload.

[2026-05-13 16:07:21.042]
DeltaMs: 60
Origem: 0xC0
Destino: 0x00
PGN: 0x000000
Dados: 00 00 00 FA FF FF FF FF
Evento: TRANSITION
Repeticoes: 1
Notas: Transicao detectada por mudanca de destino, PGN, payload.

[2026-05-13 16:07:21.042]
DeltaMs: 0
Origem: 0xC0
Destino: GLOBAL
PGN: 0x00FF11
Dados: FF FF FF FF FF FF FF FF
Evento: TRANSITION
Repeticoes: 1
Notas: Transicao detectada por mudanca de destino, PGN, payload.

[2026-05-13 16:07:21.042]
DeltaMs: 0
Origem: 0xC0
Destino: GLOBAL
PGN: 0x00FF15
Dados: FF FF FF 00 FF FF FF FF
Evento: TRANSITION
Repeticoes: 1
Notas: Transicao detectada por mudanca de PGN, payload.

[2026-05-13 16:07:21.044]
DeltaMs: 1
Origem: 0xC0
Destino: GLOBAL
PGN: 0x00FF25
Dados: 00 FF 00 00 00 00 00 00
Evento: TRANSITION
Repeticoes: 1
Notas: Transicao detectada por mudanca de PGN, payload.

[2026-05-13 16:07:21.081]
DeltaMs: 36
Origem: 0xC0
Destino: GLOBAL
PGN: 0x00FF2A
Dados: 91 FF 00 00 81 FF FF FF
Evento: TRANSITION
Repeticoes: 1
Notas: Transicao detectada por mudanca de PGN, payload.

[2026-05-13 16:07:21.172]
DeltaMs: 90
Origem: 0xC0
Destino: GLOBAL
PGN: 0x00FF26
Dados: 00 00 00 00 00 00 00 00
Evento: TRANSITION
Repeticoes: 1
Notas: Transicao detectada por mudanca de PGN, payload.

[2026-05-13 16:07:21.172]
DeltaMs: 0
Origem: 0xC0
Destino: GLOBAL
PGN: 0x00FF27
Dados: 00 FF 00 00 00 00 00 00
Evento: TRANSITION
Repeticoes: 1
Notas: Transicao detectada por mudanca de PGN, payload.

[2026-05-13 16:07:21.172]
DeltaMs: 0
Origem: 0xC0
Destino: GLOBAL
PGN: 0x00FF28
Dados: 00 FF 00 FE FF FE FE 01
Evento: TRANSITION
Repeticoes: 1
Notas: Transicao detectada por mudanca de PGN, payload.

[2026-05-13 16:07:21.174]
DeltaMs: 1
Origem: 0xC0
Destino: GLOBAL
PGN: 0x00FF29
Dados: C4 00 00 00 05 3F FF FF
Evento: TRANSITION
Repeticoes: 1
Notas: Transicao detectada por mudanca de PGN, payload.

[2026-05-13 16:07:21.182]
DeltaMs: 7
Origem: 0xC0
Destino: GLOBAL
PGN: 0x00FF2A
Dados: 91 FF 00 00 81 FF FF FF
Evento: TRANSITION
Repeticoes: 1
Notas: Transicao detectada por mudanca de PGN, payload.

[2026-05-13 16:07:21.182]
DeltaMs: 0
Origem: 0xC0
Destino: GLOBAL
PGN: 0x00FF2B
Dados: E3 C8 71 00 04 06 F7 B6
Evento: TRANSITION
Repeticoes: 1
Notas: Transicao detectada por mudanca de PGN, payload.

[2026-05-13 16:07:21.183]
DeltaMs: 0
Origem: 0xC0
Destino: GLOBAL
PGN: 0x00FF2C
Dados: 00 00 00 00 00 00 FF FF
Evento: TRANSITION
Repeticoes: 1
Notas: Transicao detectada por mudanca de PGN, payload.

[2026-05-13 16:07:21.184]
DeltaMs: 0
Origem: 0xC0
Destino: GLOBAL
PGN: 0x00FF7C
Dados: FF FF FF FF FF FF FF FC
Evento: TRANSITION
Repeticoes: 1
Notas: Transicao detectada por mudanca de PGN, payload.

[2026-05-13 16:07:21.193]
DeltaMs: 8
Origem: 0xC0
Destino: GLOBAL
PGN: 0x00FFA7
Dados: 40 17 9A 03 00 00 00 00
Evento: TRANSITION
Repeticoes: 1
Notas: Transicao detectada por mudanca de PGN, payload.

[2026-05-13 16:07:21.193]
DeltaMs: 0
Origem: 0xC0
Destino: GLOBAL
PGN: 0x00FFA8
Dados: FF FF FF FF FF FF FF FF
Evento: TRANSITION
Repeticoes: 1
Notas: Transicao detectada por mudanca de PGN, payload.
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

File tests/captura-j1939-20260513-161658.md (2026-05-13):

# Sessao
Id: 6fc9012f0a094b3c82a3f708bf0c4c3f
Inicio: 2026-05-13 16:16:47.046
Fim: 2026-05-13 16:16:58.625
DuracaoMs: 11578
FramesRecebidos: 259
FramesUnicos: 242
EventosExportados: 257

# Resumo por PGN
- PGN=0x00FF2A eventos=59 frames=72
- PGN=0x00DA00 eventos=41 frames=45
- PGN=0x00FF25 eventos=29 frames=29
- PGN=0x00FF26 eventos=29 frames=29
- PGN=0x00FF27 eventos=29 frames=29
- PGN=0x00FF28 eventos=11 frames=11
- PGN=0x00FF29 eventos=11 frames=11
- PGN=0x00FF7C eventos=11 frames=11
- PGN=0x000000 eventos=5 frames=5
- PGN=0x00FF11 eventos=5 frames=5
- PGN=0x00FF15 eventos=5 frames=5
- PGN=0x00FF2B eventos=5 frames=5
- PGN=0x00FF2C eventos=5 frames=5
- PGN=0x00FFA7 eventos=5 frames=5
- PGN=0x00FFA8 eventos=5 frames=5
- PGN=0x00EE00 eventos=1 frames=1
- PGN=0x00FFCB eventos=1 frames=1

# Resumo por Source Address
- SA=0xC0 eventos=235 frames=248
- SA=0xF9 eventos=22 frames=26

# Periodicidade detectada
- 2026-05-13 16:16:50.348 SA=0xF9 DST=GLOBAL PGN=0x00DA00 intervalo_ms=1013 repeticoes=4
- 2026-05-13 16:16:52.376 SA=0xF9 DST=GLOBAL PGN=0x00DA00 intervalo_ms=1014 repeticoes=2
- 2026-05-13 16:16:53.326 SA=0xC0 DST=GLOBAL PGN=0x00FF2A intervalo_ms=96 repeticoes=2
- 2026-05-13 16:16:53.526 SA=0xC0 DST=GLOBAL PGN=0x00FF2A intervalo_ms=96 repeticoes=2
- 2026-05-13 16:16:54.546 SA=0xC0 DST=GLOBAL PGN=0x00FF2A intervalo_ms=99 repeticoes=2
- 2026-05-13 16:16:54.946 SA=0xC0 DST=GLOBAL PGN=0x00FF2A intervalo_ms=99 repeticoes=2
- 2026-05-13 16:16:55.347 SA=0xC0 DST=GLOBAL PGN=0x00FF2A intervalo_ms=99 repeticoes=2
- 2026-05-13 16:16:55.546 SA=0xC0 DST=GLOBAL PGN=0x00FF2A intervalo_ms=100 repeticoes=2
- 2026-05-13 16:16:55.947 SA=0xC0 DST=GLOBAL PGN=0x00FF2A intervalo_ms=100 repeticoes=2
- 2026-05-13 16:16:56.347 SA=0xC0 DST=GLOBAL PGN=0x00FF2A intervalo_ms=100 repeticoes=2
- 2026-05-13 16:16:56.546 SA=0xC0 DST=GLOBAL PGN=0x00FF2A intervalo_ms=97 repeticoes=2
- 2026-05-13 16:16:56.946 SA=0xC0 DST=GLOBAL PGN=0x00FF2A intervalo_ms=99 repeticoes=2
- 2026-05-13 16:16:57.347 SA=0xC0 DST=GLOBAL PGN=0x00FF2A intervalo_ms=100 repeticoes=2
- 2026-05-13 16:16:57.946 SA=0xC0 DST=GLOBAL PGN=0x00FF2A intervalo_ms=99 repeticoes=2
- 2026-05-13 16:16:58.347 SA=0xC0 DST=GLOBAL PGN=0x00FF2A intervalo_ms=98 repeticoes=2

# Top talkers
- SA=0xC0 frames=248
- SA=0xF9 frames=26
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

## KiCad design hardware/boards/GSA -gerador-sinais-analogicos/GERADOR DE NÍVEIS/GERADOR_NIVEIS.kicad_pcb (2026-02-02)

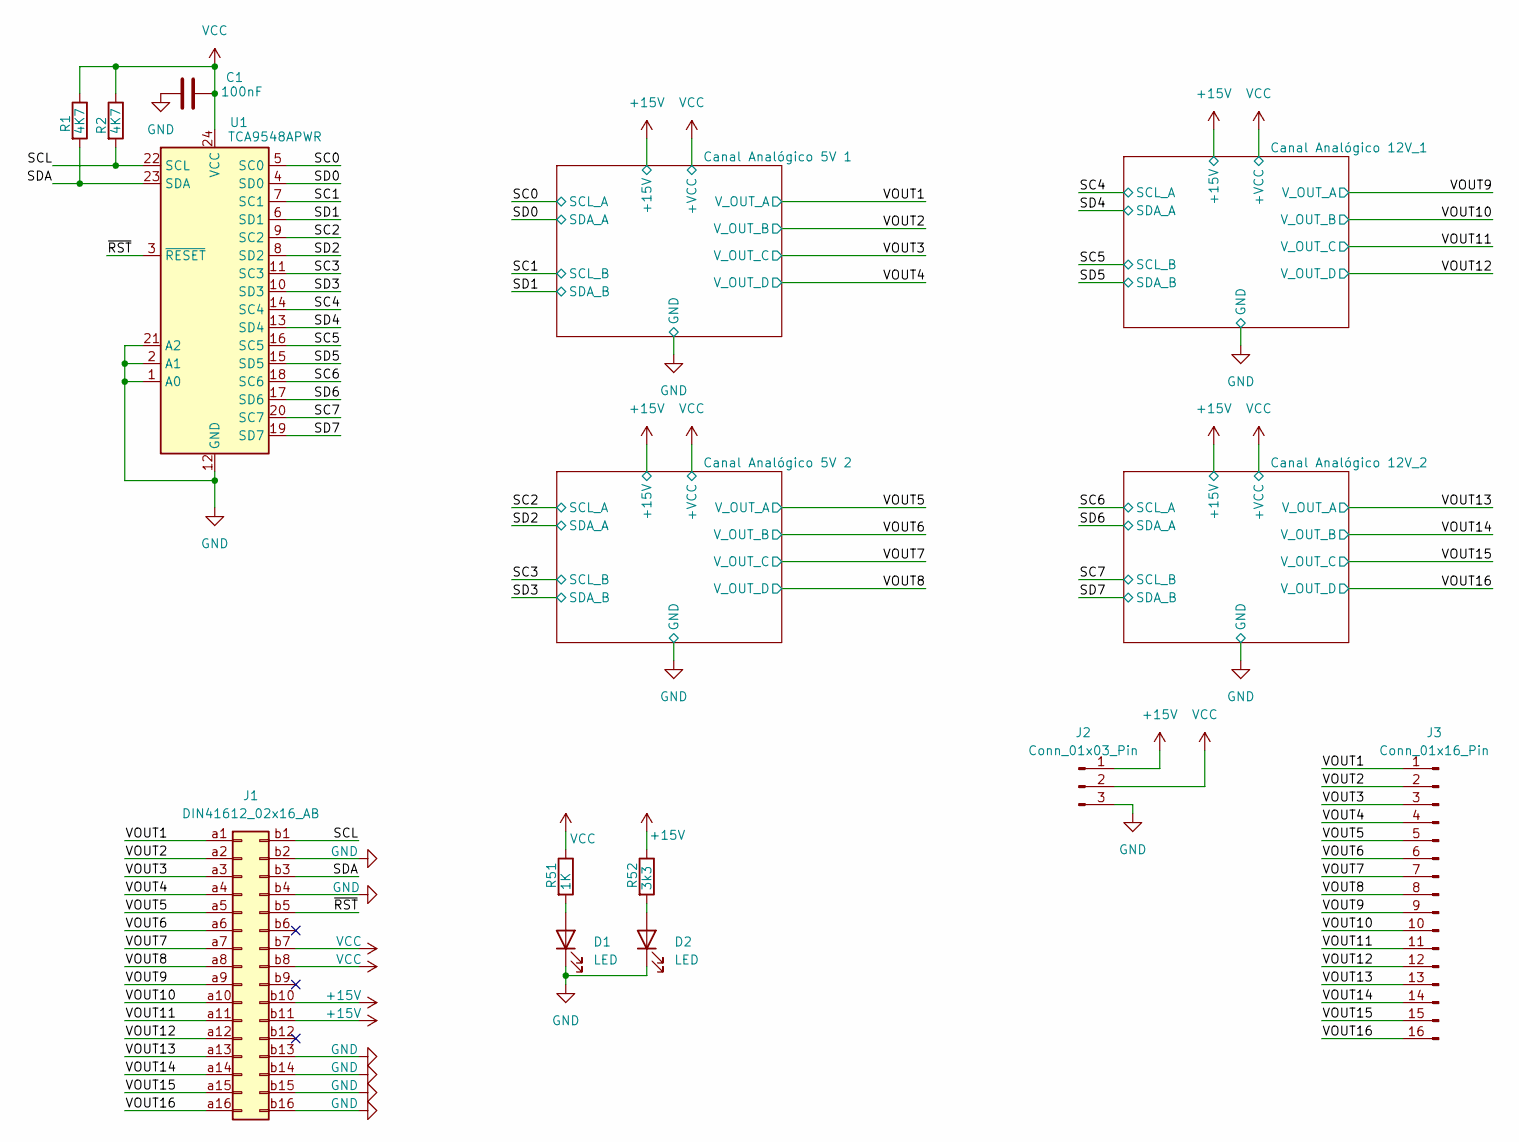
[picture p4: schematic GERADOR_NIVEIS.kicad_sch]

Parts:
C1: 100nF; C_0805_2012Metric
D1, D2: LED; LED_Avago_PLCC4_3.2x2.8mm_CW
J1: DIN41612_02x16_AB; DIN41612_B2_2x16_Female_Vertical_THT
J2: Conn_01x03_Pin; FanPinHeader_1x03_P2.54mm_Vertical
J3: Conn_01x16_Pin; PinHeader_1x16_P1.00mm_Vertical
R1, R2: 4K7; R_0805_2012Metric
R51: 1K; R_0805_2012Metric
R52: 3k3; R_0805_2012Metric
U1: TCA9548APWR; TSSOP-24_4.4x7.8mm_P0.65mm

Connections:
+15V: J1.b10, J1.b11, J2.1, R52.1; also elsewhere on the board
/SC0: U1.5 (SC0); also elsewhere on the board
/SC1: U1.7 (SC1); also elsewhere on the board
/SC2: U1.9 (SC2); also elsewhere on the board
/SC3: U1.11 (SC3); also elsewhere on the board
/SC4: U1.14 (SC4); also elsewhere on the board
/SC5: U1.16 (SC5); also elsewhere on the board
/SC6: U1.18 (SC6); also elsewhere on the board
/SC7: U1.20 (SC7); also elsewhere on the board
/SCL: J1.b1, R2.2, U1.22 (SCL)
/SD0: U1.4 (SD0); also elsewhere on the board
/SD1: U1.6 (SD1); also elsewhere on the board
/SD2: U1.8 (SD2); also elsewhere on the board
/SD3: U1.10 (SD3); also elsewhere on the board
/SD4: U1.13 (SD4); also elsewhere on the board
/SD5: U1.15 (SD5); also elsewhere on the board
/SD6: U1.17 (SD6); also elsewhere on the board
/SD7: U1.19 (SD7); also elsewhere on the board
/SDA: J1.b3, R1.2, U1.23 (SDA)
/VOUT1: J1.a1, J3.1; also elsewhere on the board
/VOUT2: J1.a2, J3.2; also elsewhere on the board
/VOUT3: J1.a3, J3.3; also elsewhere on the board
/VOUT4: J1.a4, J3.4; also elsewhere on the board
/VOUT5: J1.a5, J3.5; also elsewhere on the board
/VOUT6: J1.a6, J3.6; also elsewhere on the board
/VOUT7: J1.a7, J3.7; also elsewhere on the board
/VOUT8: J1.a8, J3.8; also elsewhere on the board
/VOUT9: J1.a9, J3.9; also elsewhere on the board
/VOUT10: J1.a10, J3.10; also elsewhere on the board
/VOUT11: J1.a11, J3.11; also elsewhere on the board
/VOUT12: J1.a12, J3.12; also elsewhere on the board
/VOUT13: J1.a13, J3.13; also elsewhere on the board
/VOUT14: J1.a14, J3.14; also elsewhere on the board
/VOUT15: J1.a15, J3.15; also elsewhere on the board
/VOUT16: J1.a16, J3.16; also elsewhere on the board
/~RST: J1.b5, U1.3 (~RESET)
GND: C1.1, D1.1 (K), D2.1 (K), J1.b2, J1.b4, J1.b13, J1.b14, J1.b15, J1.b16, J2.3, U1.1 (A0), U1.2 (A1), U1.12 (GND), U1.21 (A2); also elsewhere on the board
unnamed: D1.2 (A), R51.2
unnamed: D2.2 (A), R52.2
VCC: C1.2, J1.b7, J1.b8, J2.2, R1.1, R2.1, R51.1, U1.24 (VCC); also elsewhere on the board

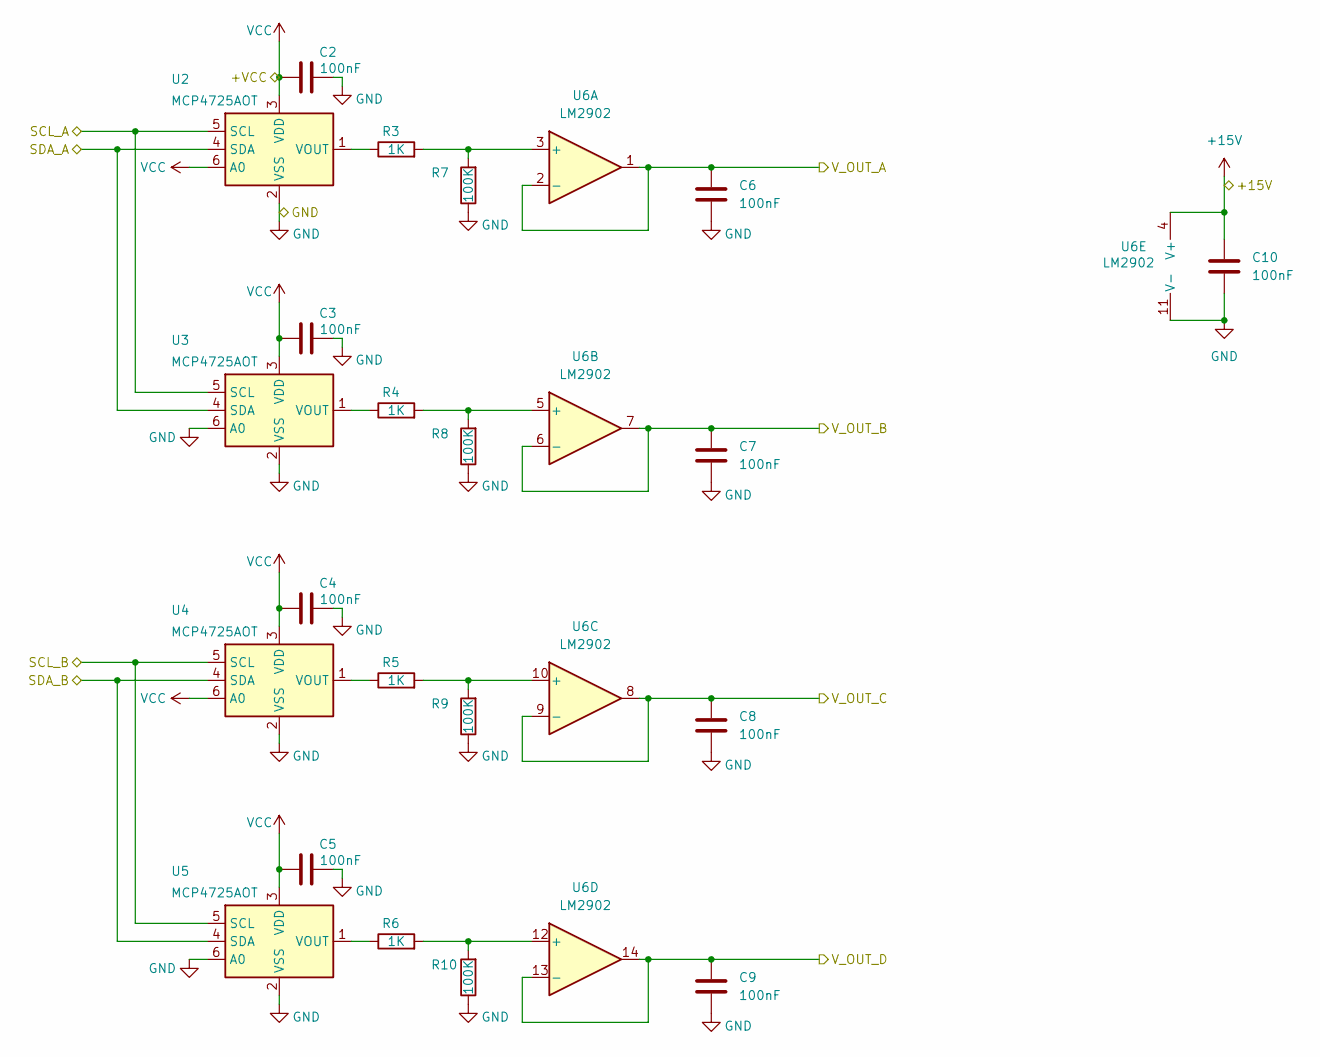
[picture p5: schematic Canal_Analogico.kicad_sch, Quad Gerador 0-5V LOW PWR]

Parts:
C2, C3, C4, C5, C6, C7, C8, C9, C10: 100nF; C_0805_2012Metric
R3, R4, R5, R6: 1K; R_0805_2012Metric
R7, R8, R9, R10: 100K; R_0805_2012Metric
U2, U3, U4, U5: MCP4725AOT; SOT-23-6
U6: LM2902; SOIC-14_3.9x8.7mm_P1.27mm

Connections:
+15V: C10.1, U6.4 (V+); also elsewhere on the board
/SC0: U2.5 (SCL), U3.5 (SCL); also elsewhere on the board
/SC1: U4.5 (SCL), U5.5 (SCL); also elsewhere on the board
/SD0: U2.4 (SDA), U3.4 (SDA); also elsewhere on the board
/SD1: U4.4 (SDA), U5.4 (SDA); also elsewhere on the board
/VOUT1: C6.1, U6.1, U6.2 (-); also elsewhere on the board
/VOUT2: C7.1, U6.6 (-), U6.7; also elsewhere on the board
/VOUT3: C8.1, U6.8, U6.9 (-); also elsewhere on the board
/VOUT4: C9.1, U6.13 (-), U6.14; also elsewhere on the board
GND: C2.2, C3.2, C4.2, C5.2, C6.2, C7.2, C8.2, C9.2, C10.2, R7.1, R8.1, R9.1, R10.1, U2.2 (VSS), U3.2 (VSS), U3.6 (A0), U4.2 (VSS), U5.2 (VSS), U5.6 (A0), U6.11 (V-); also elsewhere on the board
unnamed: R3.1, U2.1 (VOUT)
unnamed: R4.1, U3.1 (VOUT)
unnamed: R5.1, U4.1 (VOUT)
unnamed: R6.1, U5.1 (VOUT)
unnamed: R3.2, R7.2, U6.3 (+)
unnamed: R4.2, R8.2, U6.5 (+)
unnamed: R5.2, R9.2, U6.10 (+)
unnamed: R6.2, R10.2, U6.12 (+)
VCC: C2.1, C3.1, C4.1, C5.1, U2.3 (VDD), U2.6 (A0), U3.3 (VDD), U4.3 (VDD), U4.6 (A0), U5.3 (VDD); also elsewhere on the board

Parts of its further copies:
C11, C12, C13, C14, C15, C16, C17, C18, C19: 100nF; C_0805_2012Metric
R11, R12, R13, R14: 1K; R_0805_2012Metric
R15, R16, R17, R18: 100K; R_0805_2012Metric
U7, U8, U9, U10: MCP4725AOT; SOT-23-6
U11: LM2902; SOIC-14_3.9x8.7mm_P1.27mm

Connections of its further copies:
+15V: C19.1, U11.4 (V+); also elsewhere on the board
/SC2: U7.5 (SCL), U8.5 (SCL); also elsewhere on the board
/SC3: U9.5 (SCL), U10.5 (SCL); also elsewhere on the board
/SD2: U7.4 (SDA), U8.4 (SDA); also elsewhere on the board
/SD3: U9.4 (SDA), U10.4 (SDA); also elsewhere on the board
/VOUT5: C15.1, U11.1, U11.2 (-); also elsewhere on the board
/VOUT6: C16.1, U11.6 (-), U11.7; also elsewhere on the board
/VOUT7: C17.1, U11.8, U11.9 (-); also elsewhere on the board
/VOUT8: C18.1, U11.13 (-), U11.14; also elsewhere on the board
GND: C11.2, C12.2, C13.2, C14.2, C15.2, C16.2, C17.2, C18.2, C19.2, R15.1, R16.1, R17.1, R18.1, U7.2 (VSS), U8.2 (VSS), U8.6 (A0), U9.2 (VSS), U10.2 (VSS), U10.6 (A0), U11.11 (V-); also elsewhere on the board
unnamed: R11.1, U7.1 (VOUT)
unnamed: R12.1, U8.1 (VOUT)
unnamed: R13.1, U9.1 (VOUT)
unnamed: R14.1, U10.1 (VOUT)
unnamed: R11.2, R15.2, U11.3 (+)
unnamed: R12.2, R16.2, U11.5 (+)
unnamed: R13.2, R17.2, U11.10 (+)
unnamed: R14.2, R18.2, U11.12 (+)
VCC: C11.1, C12.1, C13.1, C14.1, U7.3 (VDD), U7.6 (A0), U8.3 (VDD), U9.3 (VDD), U9.6 (A0), U10.3 (VDD); also elsewhere on the board

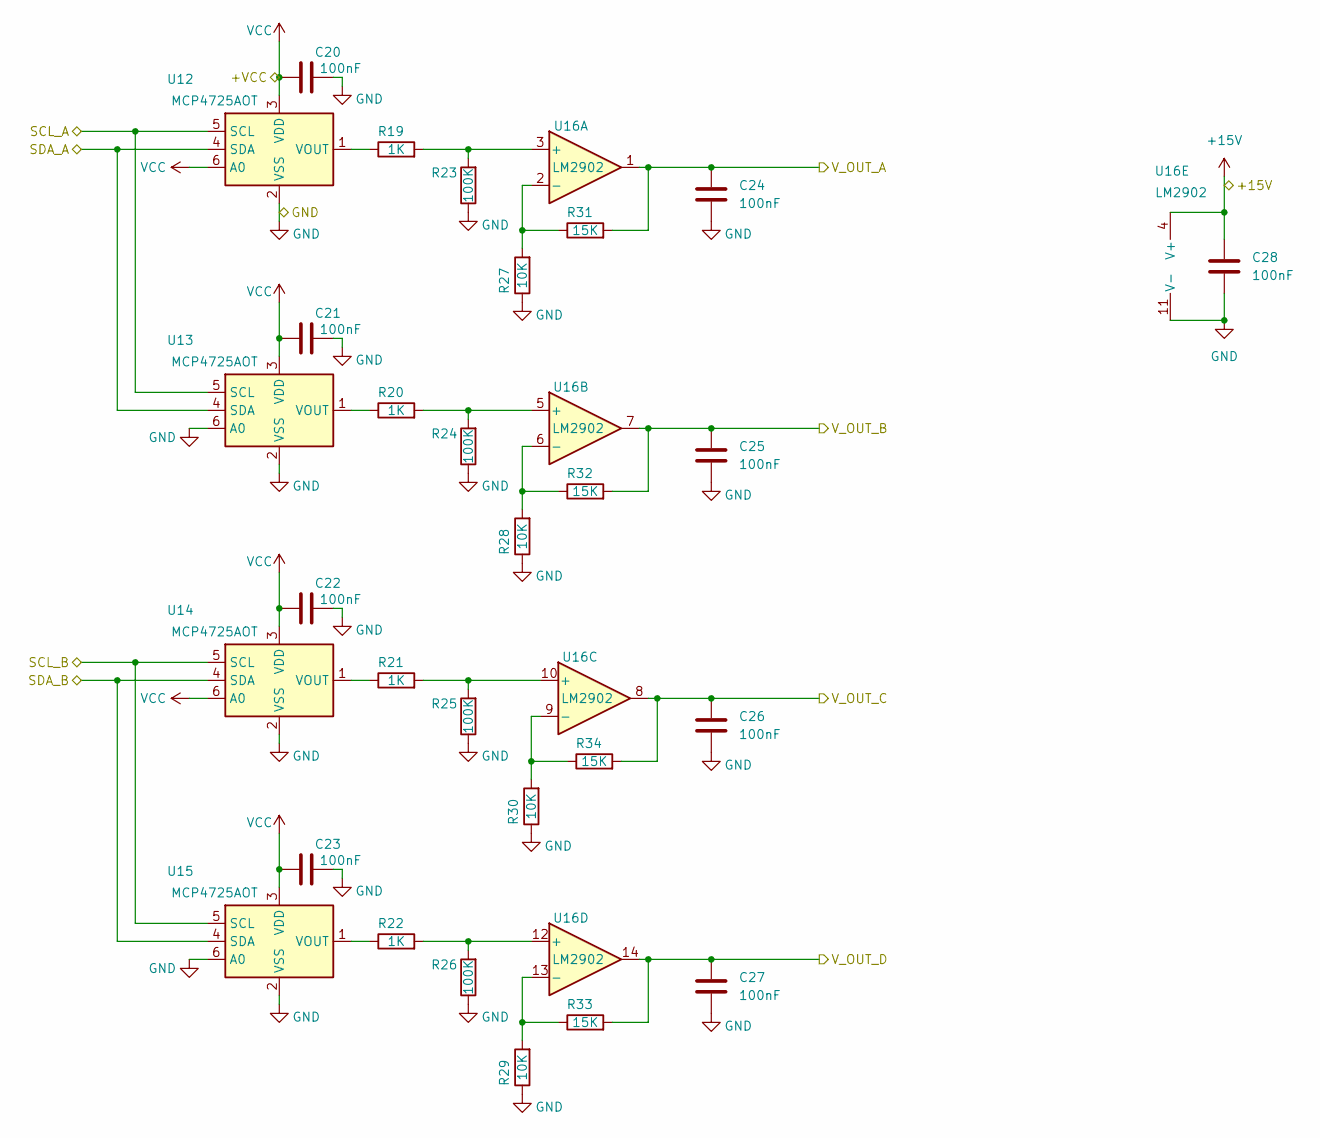
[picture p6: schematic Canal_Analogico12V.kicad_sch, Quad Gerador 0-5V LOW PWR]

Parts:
C20, C21, C22, C23, C24, C25, C26, C27, C28: 100nF; C_0805_2012Metric
R19, R20, R21, R22: 1K; R_0805_2012Metric
R23, R24, R25, R26: 100K; R_0805_2012Metric
R27, R28, R29, R30: 10K; R_0805_2012Metric
R31, R32, R33, R34: 15K; R_0805_2012Metric
U12, U13, U14, U15: MCP4725AOT; SOT-23-6
U16: LM2902; SOIC-14_3.9x8.7mm_P1.27mm

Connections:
+15V: C28.1, U16.4 (V+); also elsewhere on the board
/SC4: U12.5 (SCL), U13.5 (SCL); also elsewhere on the board
/SC5: U14.5 (SCL), U15.5 (SCL); also elsewhere on the board
/SD4: U12.4 (SDA), U13.4 (SDA); also elsewhere on the board
/SD5: U14.4 (SDA), U15.4 (SDA); also elsewhere on the board
/VOUT9: C24.1, R31.2, U16.1; also elsewhere on the board
/VOUT10: C25.1, R32.2, U16.7; also elsewhere on the board
/VOUT11: C26.1, R34.2, U16.8; also elsewhere on the board
/VOUT12: C27.1, R33.2, U16.14; also elsewhere on the board
GND: C20.2, C21.2, C22.2, C23.2, C24.2, C25.2, C26.2, C27.2, C28.2, R23.1, R24.1, R25.1, R26.1, R27.1, R28.1, R29.1, R30.1, U12.2 (VSS), U13.2 (VSS), U13.6 (A0), U14.2 (VSS), U15.2 (VSS), U15.6 (A0), U16.11 (V-); also elsewhere on the board
unnamed: R19.1, U12.1 (VOUT)
unnamed: R20.1, U13.1 (VOUT)
unnamed: R21.1, U14.1 (VOUT)
unnamed: R22.1, U15.1 (VOUT)
unnamed: R19.2, R23.2, U16.3 (+)
unnamed: R27.2, R31.1, U16.2 (-)
unnamed: R20.2, R24.2, U16.5 (+)
unnamed: R28.2, R32.1, U16.6 (-)
unnamed: R21.2, R25.2, U16.10 (+)
unnamed: R30.2, R34.1, U16.9 (-)
unnamed: R22.2, R26.2, U16.12 (+)
unnamed: R29.2, R33.1, U16.13 (-)
VCC: C20.1, C21.1, C22.1, C23.1, U12.3 (VDD), U12.6 (A0), U13.3 (VDD), U14.3 (VDD), U14.6 (A0), U15.3 (VDD); also elsewhere on the board

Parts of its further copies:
C29, C30, C31, C32, C33, C34, C35, C36, C37: 100nF; C_0805_2012Metric
R35, R36, R37, R38: 1K; R_0805_2012Metric
R39, R40, R41, R42: 100K; R_0805_2012Metric
R43, R44, R46: 10K; R_0805_2012Metric
R47, R48, R49, R50: 15K; R_0805_2012Metric
U17, U18, U19, U20: MCP4725AOT; SOT-23-6
U21: LM2902; SOIC-14_3.9x8.7mm_P1.27mm

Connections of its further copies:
+15V: C37.1, U21.4 (V+); also elsewhere on the board
/SC6: U17.5 (SCL), U18.5 (SCL); also elsewhere on the board
/SC7: U19.5 (SCL), U20.5 (SCL); also elsewhere on the board
/SD6: U17.4 (SDA), U18.4 (SDA); also elsewhere on the board
/SD7: U19.4 (SDA), U20.4 (SDA); also elsewhere on the board
/VOUT13: C33.1, R47.2, U21.1; also elsewhere on the board
/VOUT14: C34.1, R48.2, U21.7; also elsewhere on the board
/VOUT15: C35.1, R50.2, U21.8; also elsewhere on the board
/VOUT16: C36.1, R49.2, U21.14; also elsewhere on the board
GND: C29.2, C30.2, C31.2, C32.2, C33.2, C34.2, C35.2, C36.2, C37.2, R39.1, R40.1, R41.1, R42.1, R43.1, R44.1, R46.1, U17.2 (VSS), U18.2 (VSS), U18.6 (A0), U19.2 (VSS), U20.2 (VSS), U20.6 (A0), U21.11 (V-); also elsewhere on the board
unnamed: R35.1, U17.1 (VOUT)
unnamed: R36.1, U18.1 (VOUT)
unnamed: R37.1, U19.1 (VOUT)
unnamed: R38.1, U20.1 (VOUT)
unnamed: R35.2, R39.2, U21.3 (+)
unnamed: R43.2, R47.1, U21.2 (-)
unnamed: R36.2, R40.2, U21.5 (+)
unnamed: R44.2, R48.1, U21.6 (-)
unnamed: R37.2, R41.2, U21.10 (+)
unnamed: R46.2, R50.1, U21.9 (-)
unnamed: R38.2, R42.2, U21.12 (+)
unnamed 78: R49.1, U21.13 (-); also elsewhere on the board
VCC: C29.1, C30.1, C31.1, C32.1, U17.3 (VDD), U17.6 (A0), U18.3 (VDD), U19.3 (VDD), U19.6 (A0), U20.3 (VDD); also elsewhere on the board

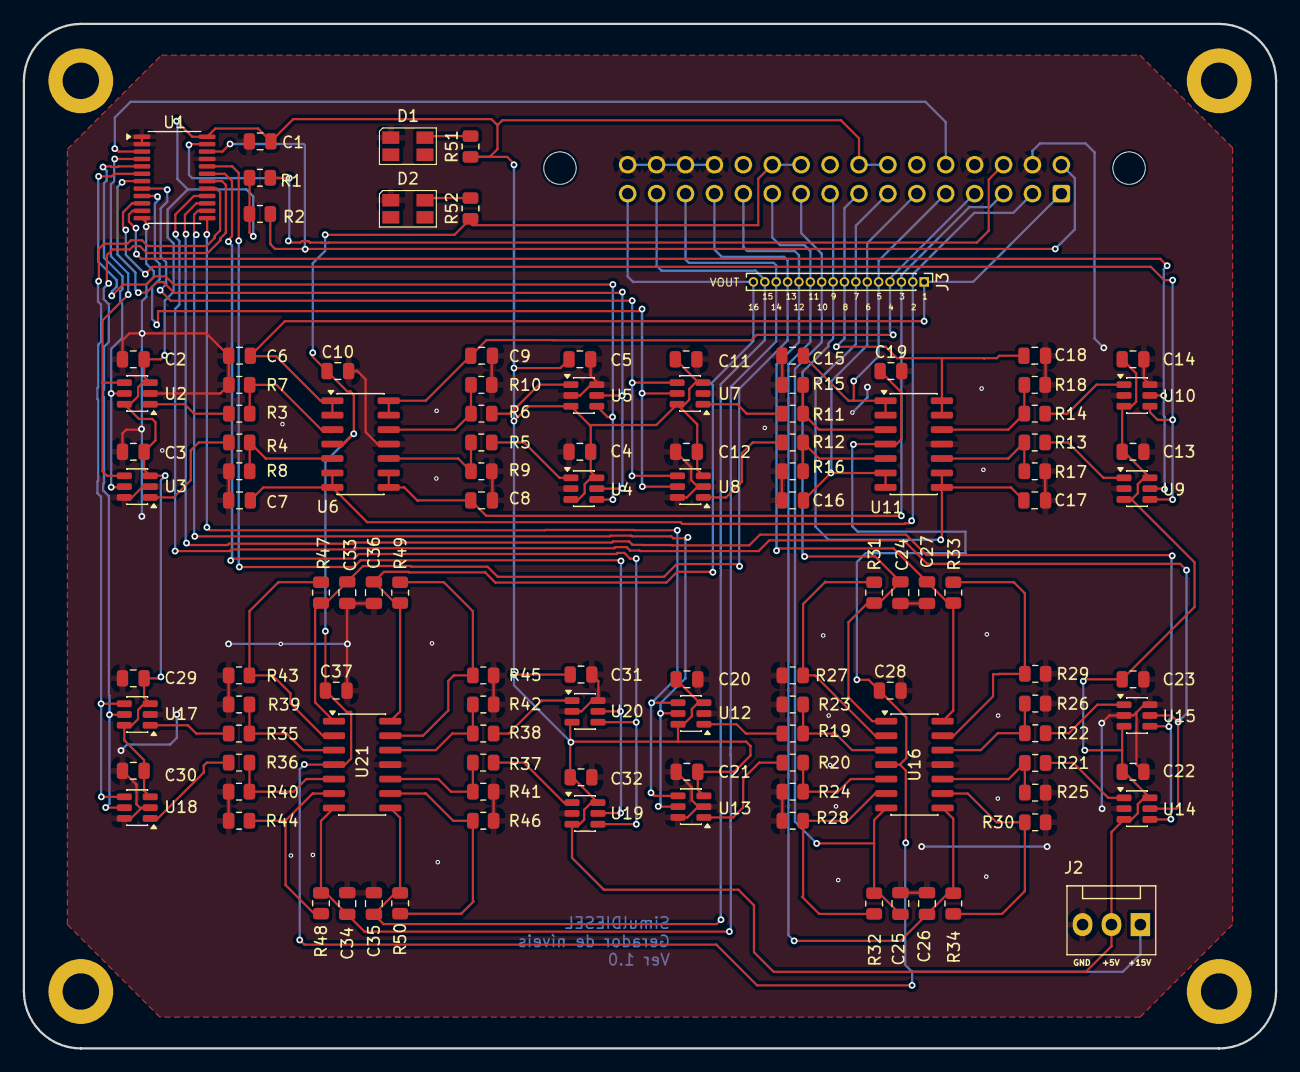
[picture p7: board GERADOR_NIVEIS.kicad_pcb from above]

Board: 2 copper layers, 110.0 x 90.0 mm, 115 parts (1 on the bottom side), 80 nets.

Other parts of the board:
R45: 10K; R_0805_2012Metric

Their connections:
GND: R45.1; also elsewhere on the board
unnamed 78: R45.2; also elsewhere on the board

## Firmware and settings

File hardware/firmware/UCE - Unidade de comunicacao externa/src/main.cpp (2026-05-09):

#include <Arduino.h>
#include "core/link/SpiLink.h"
#include "core/services/UceServiceDispatcher.h"
#include "core/transport/UceTransport.h"
#include "services/can/sdctp/SdctpService.h"
#include "services/led/LedService.h"

namespace {
SpiLink g_spiLink;
LedService g_ledService;
SdctpService g_sdctpService;
UceServiceDispatcher g_dispatcher(g_ledService, g_sdctpService);
UceTransport g_transport(g_spiLink, g_dispatcher);
}

void setup() {
  g_spiLink.begin();
  g_transport.begin();
}

void loop() {
  g_transport.poll();
  g_dispatcher.loop();
}

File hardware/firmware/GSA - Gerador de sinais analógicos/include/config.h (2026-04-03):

#pragma once

#include <stdint.h>
#include <Arduino.h>

static const uint8_t GSA_CHANNEL_COUNT = 16;
static const uint8_t GSA_CHANNEL_FIRST = 1;
static const uint8_t GSA_CHANNEL_LAST = 16;

static const uint16_t GSA_LOW_RANGE_MAX_MV = 5000;
static const uint16_t GSA_HIGH_RANGE_MAX_MV = 12000;
static const uint16_t GSA_IREAD_MAX_MA = 200;

static const uint16_t GSA_SIM_BASE_VOUT_MV = 1000;
static const uint16_t GSA_SIM_VOUT_STEP_MV = 100;
static const uint16_t GSA_SIM_BASE_IREAD_MA = 100;
static const uint16_t GSA_SIM_IREAD_STEP_MA = 1;

static const uint16_t GSA_EEPROM_SIGNATURE = 0x4753;
static const uint8_t GSA_EEPROM_VERSION = 1;

// Pinagem oficial GSA <-> BPM.
// I2C fisico com a BPM: Wire / A4-A5 (slave).
// I2C logico com TCA9548 + MCP4725: SoftwareWire / D2-D3 (master).
static const uint8_t GSA_PHYSICAL_I2C_SDA_PIN = A4;
static const uint8_t GSA_PHYSICAL_I2C_SCL_PIN = A5;
static const uint8_t GSA_LOGICAL_I2C_SDA_PIN = 2;
static const uint8_t GSA_LOGICAL_I2C_SCL_PIN = 3;
static const uint8_t GSA_IRQ_PIN = 4;
static const uint8_t GSA_TCA_RESET_PIN = 8;

static const uint16_t GSA_LOGICAL_I2C_DELAY_US = 5;
static const uint8_t GSA_TCA_RESET_PULSE_MS = 1;
static const uint8_t GSA_TCA_RESET_SETTLE_MS = 1;
static const uint8_t GSA_PHYSICAL_OP_QUEUE_SIZE = 24;
static const uint8_t GSA_EVENT_QUEUE_SIZE = 24;

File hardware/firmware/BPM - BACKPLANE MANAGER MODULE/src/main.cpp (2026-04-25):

#include <Arduino.h>

#include "SdgwDefs.h"
#include "SdgwTransport.h"
#include "SdgwBluetoothEndpoint.h"
#include "SdgwEndpointMux.h"
#include "SdgwSessionOwner.h"
#include <SdgwLink.h>

// GatewayCore
#include "IGatewayApp.h"
#include "GatewayApp.h"
#include "GwI2cBus.h"
#include "GwSpiBus.h"
#include "GwRouter.h"

static SdgwTransport serialTransport(Serial);
static SdgwBluetoothEndpoint bluetoothTransport("SimulDIESEL - BPM");
static SdgwSessionOwner sessionOwner(SDGW_ENDPOINT_NONE);
static SdgwEndpointMux transportMux(sessionOwner, serialTransport, bluetoothTransport);
static SdgwLink sdgwLink(transportMux, sessionOwner);

// Buses
static GwI2cBus i2cBus(Wire);
static GwSpiBus spiBus(SPI);

// Router
static GwRouter router(i2cBus, spiBus);

// App
static GatewayApp app(sdgwLink, router);

void setup() {
  // Reserva o GPIO23 exclusivamente para o reset global.
  digitalWrite(BPM_GLOBAL_RESET_PIN, BPM_GLOBAL_RESET_INACTIVE_LEVEL);
  pinMode(BPM_GLOBAL_RESET_PIN, OUTPUT);

  serialTransport.begin();
  serialTransport.setTextEnabled(true);
  bluetoothTransport.begin();
  bluetoothTransport.setTextEnabled(true);

  i2cBus.begin(BPM_GSA_I2C_SDA_PIN, BPM_GSA_I2C_SCL_PIN, 400000);
  spiBus.begin(1000000UL,
               BPM_SPI_SCK_PIN,
               BPM_SPI_MISO_PIN,
               BPM_SPI_MOSI_PIN);

  sdgwLink.attachApp(&app);
  app.begin();
  sdgwLink.begin();
}

void loop() {
  sdgwLink.poll();
  app.tick();
}

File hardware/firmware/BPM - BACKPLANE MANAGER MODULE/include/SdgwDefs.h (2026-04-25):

#pragma once
#include <stdint.h>


// ============================================================
// I2C - Baby boards
// ============================================================
#define I2C_GSA_ADDR  0x23   // endereco fisico padrao do GSA no barramento I2C
#define BPM_GSA_I2C_SDA_PIN   21
#define BPM_GSA_I2C_SCL_PIN   22
#define BPM_GSA_IRQ_PIN       19
#define BPM_GLOBAL_RESET_PIN  23
#define BPM_GLOBAL_RESET_ACTIVE_LEVEL LOW
#define BPM_GLOBAL_RESET_INACTIVE_LEVEL HIGH

// ============================================================
// SPI - UCE backplane
// ============================================================
#define BPM_SPI_SCK_PIN       18
#define BPM_SPI_MISO_PIN      26
#define BPM_SPI_MOSI_PIN      25
#define BPM_UCE_SPI_CS_PIN    33
#define BPM_UCE_IRQ_PIN       27
#define BPM_UCE_RESET_PIN     BPM_GLOBAL_RESET_PIN

// ============================================================
// GSA - TLV commands (I2C payload)
// ============================================================
#define GSA_CMD_SETPOINT       0x10
#define GSA_CMD_ENABLE_CH      0x11
#define GSA_CMD_SET_LED        0x12
#define GSA_CMD_ENABLE_GLOBAL  0x14
#define GSA_CMD_FAULT_RESET    0x15
#define GSA_CMD_OFFSET_SET     0x16
#define GSA_CMD_OFFSET_SAVE    0x18
#define GSA_CMD_OFFSET_RESET   0x1A
#define GSA_CMD_STATUS_CH      0x1B
#define GSA_CMD_FAULT_EVENT    0x30
#define GSA_CMD_PHYSICAL_EVENT 0x31
#define GSA_CMD_FUNC_ERROR     0x7F
#define UCE_CMD_SET_LED        0x12
#define UCE_CMD_FUNC_ERROR     0x7F

#define LED_BUILTIN  2
// ============================================================
// UART
// ============================================================
#define SDGW_UART_BAUDRATE              115200
#define SDGW_UART_CONFIG                SERIAL_8N1


// Ajuste caso o LED da sua placa seja ativo em LOW
#define LED_ACTIVE_LOW 0


// ============================================================
// Protocol limits (logical = antes do COBS)
// ============================================================
#define SDGW_MAX_LOGICAL_FRAME          250   // CMD+FLAGS+SEQ+DATA(0..247)+CRC
#define SDGW_MAX_PAYLOAD                247

// COBS worst-case: len + len/254 + 1  (250 => 252) + delimiter => 253
// Mantemos folga para robustez
#define SDGW_MAX_ENCODED_FRAME          384
#define GW_SPI_PACKET_LIMIT             64

// Cache de resposta para retransmissão (ACK/ERR + delimiter)
// 64 é suficiente para ACK/ERR + 1 byte de erro, mas deixamos folga
#define SDGW_MAX_LAST_RESPONSE          64

// Handshake
#define SDGW_HANDSHAKE_BUFFER           64
#define SDGW_HANDSHAKE_TIMEOUT_MS       2000

// Sessao/atividade do link
#define SDGW_LINK_ACTIVITY_TIMEOUT_MS   4000

// Timeout interno do gateway ao rotear para a baby board
#define SDGW_GATEWAY_ROUTE_TIMEOUT_MS   100

// ============================================================
// Flags
// ============================================================
#define SDGW_FLAG_ACK_REQUIRED          0x01
#define SDGW_FLAG_IS_EVENT              0x02

// ============================================================
// Reserved commands
// ============================================================
#define SDGW_CMD_ACK                    0xF1
#define SDGW_CMD_ERR                    0xF2
#define SDGW_TLV_GATEWAY_ERR            0xFE

// ============================================================
// Reserved operational commands
// ============================================================
#define SDGW_CMD_PING                   0x55

// ============================================================
// Error codes (para payload do ERR)
// ============================================================
#define SDGW_ERR_UNKNOWN_CMD            0x01
#define SDGW_ERR_BAD_CRC                0x02
#define SDGW_ERR_BAD_COBS               0x03
#define SDGW_ERR_TOO_LARGE              0x04
#define SDGW_ERR_TOO_SMALL              0x05

// ============================================================
// CRC-8/ATM
// ============================================================
#define SDGW_CRC_POLY                   0x07
#define SDGW_CRC_INIT                   0x00

// ============================================================
// COBS framing
// ============================================================
#define SDGW_COBS_DELIMITER             0x00

// ============================================================
// Handshake strings
// ============================================================
#define SDGW_PC_BANNER                  "\nSIMULDIESELAPI\n"
#define SDGW_DEVICE_BANNER              "SimulDIESEL ver 0.0.1\n"

// ============================================================
// Sequence
// ============================================================
#define SDGW_SEQ_START                  1
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

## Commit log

2026-02-02 docs(protocol): add SD-GW-LINK spec, ADR-0007 and hex test vectors
    [Canal_Analogico.kicad_sch, Canal_Analogico12V.kicad_sch, GERADOR_NIVEIS.kicad_pcb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]
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2026-02-17 Integrate SGGW: link engine + client API + LED tool + ESP32 firmware
2026-02-21 gateway: reorganiza estrutura para modelo src/ + roteamento TLV puro
2026-02-28 Adiciona CI para firmware (PlatformIO)
2026-02-28 Chore: move relatórios gerados para tools/out e ignora a pasta
2026-03-06 SimulDIESEL v0.3.0
    Arquitetura estabilizada
    Reorganização completa da documentação
    Separação arquitetura / hardware
    Integração PC ↔ Gateway definida
    Estrutura do projeto consolidada
2026-03-14 docs: update documentation and project state
    [01-comparacao-docs.csv, 02-merge-docs.csv, docs_dump.txt]
2026-03-16 Fix I2C instability, restore stable BPM/GSA modules, and validate GSA LED command end-to-end
    [Canal_Analogico.kicad_sch, Canal_Analogico12V.kicad_sch, GERADOR_NIVEIS.kicad_pcb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]
2026-03-17 Refatora arquitetura do local-api por boards, forms logic e camadas de protocolo
    [dump_reestrutura.txt]
2026-03-17 Remove dump técnico da refatoração
    [dump_reestrutura.txt]
2026-03-17 Ajusta regras de EOL no repositório
2026-03-22 Checkpoint antes da implementação completa da GSA
    [Canal_Analogico.kicad_sch, Canal_Analogico12V.kicad_sch, GERADOR_NIVEIS.kicad_pcb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]
2026-03-22 Checkpoint antes da migração do TLV 0x12 para 0x1B na GSA
2026-03-22 Migra GSA channel.status de 0x12 para 0x1B
2026-03-22 Checkpoint antes da implementação I2C real TCA9548 + MCP4725
2026-03-22 Checkpoint antes da implementação da máquina operacional GSA BUSY/IDLE + I2C master/slave + TCA9548 + MCP4725
2026-03-24 Checkpoint antes da adaptação do gateway BPM para IRQ + evento 0x31 da GSA
2026-03-24 Checkpoint antes da integração I2C duplo + IRQ + evento 0x31 na GSA
2026-03-27 Checkpoint antes da Fase 1 - refatoracao do host para multiplos transportes
2026-03-27 Refatora host SDGW para desacoplar sessao do transporte e preservar Serial
2026-03-27 Checkpoint antes da Fase 2 - refatoracao do firmware BPM para multiplos transportes
2026-03-27 Refatora firmware BPM para desacoplar SGGW do stream fisico e preservar Serial
2026-04-03 Checkpoint antes da reestruturacao da documentacao
    [dump.txt]
2026-04-06 docs: aprofunda documentação de firmware e hardware e fecha etapa atual
    Reflete o estado implementado de BPM, GSA e da bancada, consolida as trilhas ONDE e COMO fora da API e registra o fechamento da etapa atual, deixando apenas a finalização da GSA pendente e preparando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
2026-04-06 refactor: consolida nova fundação SDGW e estrutura modular da solução
    [01-comparacao-docs.csv, 02-merge-docs.csv, Canal_Analogico.kicad_sch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]
2026-04-17 Checkpoint SPI Parte A: correção do transporte BPM<->UCE com TX explícito no slave, validação de header no master e melhoria na classificação de erros. Builds OK (UCE/BPM). Validação em bancada pende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
2026-04-17 Checkpoint SPI Parte A + comissionamento: correção do transporte BPM<->UCE, dumps técnicos versionados para rastreabilidade, builds OK, validação de bancada pendente
    [_c_ast.cfg, app3M_fat9M_16MB.csv, app3M_fat9M_fact512k_16MB.csv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]
2026-04-24 Commission validated BPM-UCE SPI LED handshake
2026-04-25 feat: comissiona transporte SPI e dispatchers por board
2026-04-25 refactor: centraliza transacoes TLV por board na API
2026-04-25 Desenvolvendo controle de mensagens CAN
2026-04-27 feat(can): implementa CAN_RX_EVENT assíncrono com pipeline UCE→BPM→API validado em bancada
2026-04-30 Construção de CanService na UCE
2026-05-09 feat(sdctp): consolida arquitetura final CAN transport protocol para producao
2026-05-09 feat(api): inicia camada de decodificacao J1939
2026-05-09 chore(api): remove log legado de depuracao CAN_TIC
2026-05-09 feat(api): adiciona catalogo padrao de PGNs J1939
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2026-05-17 docs: cria guia comum para agentes
2026-05-17 docs: consolida bootstrap de agentes em .agents
2026-05-17 docs: rebaixa AGENTS.md para redirecionamento
2026-05-17 docs: remove AGENTS legado apos migracao para .agents
2026-05-17 docs: migra indice de skills para .agents
2026-05-17 docs: simplifica bootstrap de agentes no README raiz
2026-05-17 docs: migra skill de arquitetura para .agents
2026-05-17 docs: migra skill architecture para .agents
2026-05-17 docs: migra skill winforms-ui para .agents
2026-05-17 docs: migra skill bll-dal-dtl para .agents
2026-05-17 docs: centraliza regras globais de agentes
2026-05-17 docs: consolida governanca de agentes e saneia skills
2026-05-17 docs: adiciona skill de gestao de regras de governanca
2026-05-17 docs: reforca regra de gestao de governanca IA
2026-05-17 docs: atualiza skill de governanca
2026-05-17 docs: adiciona skill de workflow de execucao de tarefas
2026-05-17 docs: adiciona workflow oficial de execucao de tarefas
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2026-05-17 docs: centraliza regras especificas de tasks na skill local
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2026-05-18 docs: ajusta regra transitoria de divergencia docs x codigo
2026-05-18 docs: absorve regras antigas de DOCUMENTATION_RULES para skill docs
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2026-05-18 docs: cria ETAPA de consolidacao estrutural de docs
2026-05-18 docs: cria ETAPA de atualizacao documental baseada no codigo
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
